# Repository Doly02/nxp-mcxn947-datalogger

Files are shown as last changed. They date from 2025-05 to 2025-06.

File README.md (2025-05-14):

## Digital Data Logger with Information Loss Prevention in Case of Power Failure

- Author: Tomáš Dolák 
- Login: [xdolak09](https://www.vut.cz/lide/tomas-dolak-247220)
- Email: <xdolak09@stud.fit.vutbr.cz>
- Supervisor: Ing. Václav Šímek
- Consultant: Ing. Martin Moštěk PhD. (NXP Semiconductors)

The goal of this project is to develop a digital data logger that captures serial data from a UART peripheral, timestamps it, and stores the logged data on an SD card.
A key requirement of the implementation is to ensure data integrity by preventing loss in the event of a power failure. This digital data logger was developed based on the requirements provided by the Wireless Charging Team at NXP Semiconductors.

### Table of Contents
- [Requirements](#requirements)
  - [Hardware Components](#hardware-components)
  - [Software Requirements](#software-requirements)
- [Repository Organization](#repository-organization)
- [How to Use the Digital Data Logger](#how-to-use-the-digital-data-logger)
  - [USB Interfaces](#usb-interfaces)
  - [Signal Diodes](#signal-diodes)
  - [Data Recording](#data-recording)
  - [Reading Data from the Data Logger](#reading-data-from-the-data-logger)
  - [Structure of Logged Data](#structure-of-logged-data)
  - [Format of Logged Entries](#format-of-logged-entries)
- [Developer Notes](#developer-notes)
  - [Modules](#modules)
- [Testing](#testing)
  - [Functional Testing](#functional-testing)
  - [Static Code Analysis](#static-code-analysis)
- [Documentation](#documentation)
- [Known Issues](#known-issues)
- [References](#references)

### Requirements 
To build and run `datalogger`, you will need the following:

#### Hardware Components
1. NXP FRDM-MCXN947 Development Board
2. Expansion Shield Proposed in This Bachelor Thesis

#### Software Requirements
1. MCUXpresso IDE v11.10.0 With GCC-based ARM Embedded Toolchain (Arm-none-eabi-gcc Compiler)
1. NXP SDK FRDM-MCXN947 Version 2.16.000

### Repository Organization
```
/nxp-mcxn947-datalogger
├── application/                 # Main Directory With Digital Recorder Firmware.
│   ├── src/                  # Contains The Firmware Source Files.
│   ├── doc/                     # HTML and LaTeX Firmware Documentation Generated by Doxygen.
│   ├── include/                 # Contains The Firmware Header Files.
│   └── others...                # Project Files (.cproject & .project), Libraries (e.g. FATFS), FreeRTOS, Utilities, Modules and Drivers From NXP SDK.
│
├── hardware/
│   ├── components/              # List of Used Hardware Components on Expansion Shield.
│   ├── design/                  # KiCAD Project Containing Schematic and PCB Design.
│   └── pinout_datalogger.xlsx   # Table With Overview of Microcontroller Pin Connections.
├── power_consumption/           # Digital Data Logger Power Consumption Data, Measured By Power Profiler Kit II. [1]
├── tests/
│   ├── functional_tests/        # Functional Test Folder For Verifying Correct Data Collection.
│   │   ├── test_files/          # Test Files Used By serial_tests.py Script.
│   │   ├── stress_test.py       # Script With Stress Test For Digital Data Logger Sends Data Continiously With Baudrate 921600.
│   │   └── serial_tests.py      # serial_tests.py Script.
│   └── static_analysis/
│       ├── outputs/             # Contains Outputs of Static Code Analysis According To MISRA C:2012 Rules, Performed by PC-lint Tool.
│       ├── parsers/             # Contains Parsers That Filter Rule-Breakings MISRA Rules From The Required and Mandatory Categories.
│       ├── lint_config.lnt      # Configuration File of PC Lint Plus.
│       └── sources.lst          # Defines a Set of Files To Be Analyzed by PC Lint Plus.
│
├── thesis/                                     # Sub-Module
│   ├── xdolak09-bthesis.tex                    # Main LaTeX Project of Technical Report.
│   ├── project-01-kapitoly-chapters.tex        # Chapters LaTeX Project of Technical Report.
│   ├── project-20-literatura-bibliography.bib  # Bibliography of Technical Report.
│   ├── project-30-prilohy-appendices.tex       # Appendices of Technical Report.
│   ├── table-of-extraneous-words.tex           # Table of Extraneous Words in Technical Report.
│   ├── bib-styles
│   ├── obrazky-figures/         # Used Figures.
│   ├── template-fig/            # VUT Logo.
│   └── diagrams/                # Created Digrams For Technical Report.
│
├── config                       # Contains a Sample Configuration File That Can Be Used To Configure The Behaviour of The Digital Recorder.
├── README.md
```

### How to Use the Digital Data Logger

#### Signal Diodes

The digital data logger is equipped with five status LEDs (labeled 1–5) located on the front side of the enclosure. These LEDs visually indicate the current operational state of the logger.

The image below shows the placement and labeling of each LED on the front panel of the enclosure:

<p align="center">
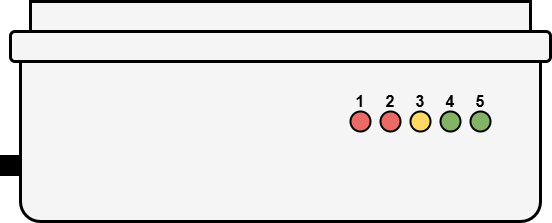
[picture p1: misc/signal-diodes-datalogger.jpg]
Data logger status LEDs
  <br>
  <em>Data logger status LEDs </em><br>
</p>

The table below describes the function of each LED:

| LED | Description |
|-----|---|
| 1 | Lights up when the available free space on the SD card falls below the limit defined by the `free_space` parameter in the configuration file. |
| 2 | Indicates an error condition. This LED turns on if the configuration file is invalid or if a critical error occurs during data recording (e.g., file creation failure or UART framing error). |
| 3 | Signals that the data logger is no longer actively recording. This state occurs, for example, when the monitored device stops transmitting data or is disconnected. |
| 4 | Blinks during active data recording to indicate that data is being received and saved to the SD card. |
| 5 | Lights up approximately 16 seconds after powering the logger to indicate that the backup capacitor is sufficiently charged. Once lit, it is safe to disconnect the device from power without risking data loss. |

#### Data Recording
1. **(Optional But Recommended)** Prepare the configuration file `config`, which should be placed in the root directory of the SD card.  
This file allows you to customize the data logger's behavior instead of using the default configuration.

<p align="center">
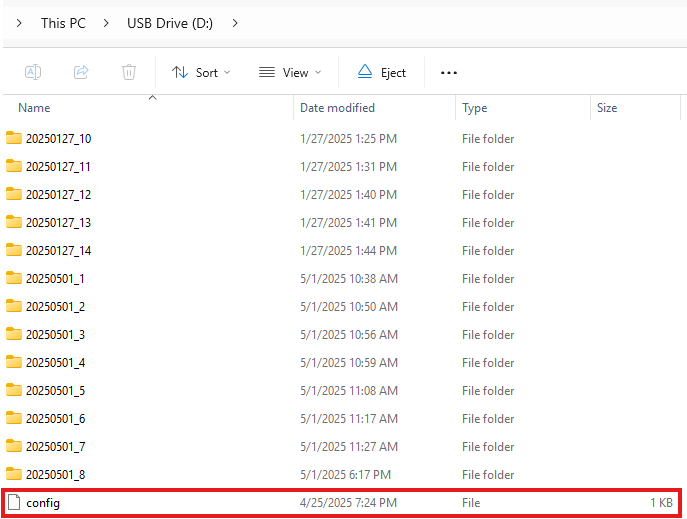
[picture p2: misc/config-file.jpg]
Location of the config file on the SD card
  <br>
  <em>Location of the config file on the SD card</em><br>
</p>

Example content of `config`:
```
baudrate=115200
file_size=2048
stop_bits=1
data_bits=8
parity=none
free_space=50
```
- **Note:** The order of parameters is not fixed.

If some of the parameters in the configuration file are missing or the configuration file is missing completely,  
the default values defined in the `defs.h` file are used.

| Parameter | Default Value | Data Type |
|---|---|---|
| `baudrate` | `230400` | uint32_t |
| `file_size` | `8192` | uint32_t (in KiB) |
| `stop_bits` | `kLPUART_OneStopBit` | enum (lpuart_stop_bit_count_t) |
| `data_bits` | `kLPUART_EightDataBits` | enum (lpuart_data_bits_t) |
| `parity` | `kLPUART_ParityDisabled` | enum (lpuart_parity_mode_t) |
| `free_space` | `50` | uint32_t (in MiB) |

2. Insert the SD card (type SDHC) into the data logger.

3. Power on the data logger via USB or another power source. The data logger will automatically:
- Load the configuration from `config` (if present)
- After startup, the data logger enters the recording mode by default. At the beginning of the record task, it initializes the SD card, and if a new or unformatted card is detected,  
  the firmware will automatically format it and initialize the FAT file system with 32-bit LBA.

4. Wait until the LED 5 indicator turns on.  
   This LED indicates that the digital data logger can be safely disconnected without the risk of data loss or file system corruption.

5. Connect the digital data logger to the monitored device that transmits serial data via UART.  
   Once the data transmission starts, the data logger will indicate active reception by blinking a dedicated LED 4,  
   which is shown in the following image.

6. At this point, the digital data logger is actively recording incoming UART data.  
   During recording, the same LED continuously blinks to indicate that data logging is in progress.

7. If an error occurs during UART data reception (e.g. framing error),  
   the digital data logger will illuminate a separate error LED 2  
   to indicate that logging has been interrupted due to a fault.

   If the error prevents further data reception, an additional LED 3 will also light up  
   to signal that the device can no longer continue logging until it is restarted or the error is resolved.

8. To safely stop data logging, disconnect the digital data logger from the monitored device.  
   At this point, all buffered data will be properly finalized and stored on the SD card.  
   The status LED D3 will then light up to indicate that data reception has been halted  
   and the device is in standby mode.

9. To resume data logging after it has been halted, simply reconnect the digital data logger  
   to the monitored UART device. The logger will automatically return to recording mode  
   (described in step 6) and continue capturing incoming data.

10. In the event of a power disconnection during logging,  
    the digital data logger detects the power loss and automatically saves all buffered data.  
    The recording is then gracefully finalized to prevent data loss or file system corruption.

#### Reading Data from the Data Logger
To read the recorded data from the digital data logger, simply connect the device to a computer using the USB1_HS connector.  
The data logger will automatically switch into data access mode (MSC mode), and the SD card will be exposed as a standard mass storage device,  
allowing the user to copy the recorded data files.

<p align="center">
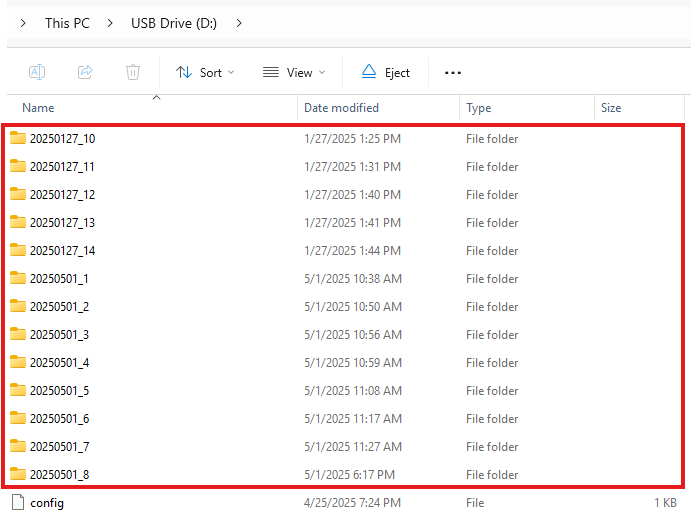
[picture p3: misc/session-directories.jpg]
Organization of session directories with logs on SD cards
  <br>
  <em>Organization of session directories with logs on SD cards</em><br>
</p>

#### Structure of Logged Data
After each startup, the data logger creates a new session directory in which all the logs from the current runtime are stored.  
These session folders are organized by the date and an incrementing counter in the format:

```
YYYYMMDD_X/
```

Where:  
- `YYYYMMDD` is the date of the session creation  
- `X` is an integer session index used to differentiate multiple sessions created on the same day

After data has been recorded, each session folder contains text-based log files storing the data collected during the corresponding session.  
The maximum size of each log file is determined by the `file_size` parameter defined in the configuration file (see chapter on configuration).  
Log files are named using the following format:

```
YYYYMMDD_HHMMSS_X.txt
```

- `YYYYMMDD_HHMMSS` is the timestamp when the log file was created  
- `X` is an index used to differentiate multiple files created at the same second

#### Format of Logged Entries
Each logged line represents a single data record terminated by a line break sequence (`\r\n`).  
Every line is prefixed with a timestamp in the format:

```
(HH:MM:SS) Logged Message
```

This timestamp represents the time when the specific data was captured by the logger.  
The following example illustrates the typical appearance of consecutive logged lines in a file:

```
(00:10:16) New Data 23741
(00:10:16) New Data 23742
(00:10:16) New Data 23743
(00:10:16) New Data 23744
(00:10:16) New Data 23745
(00:10:16) New Data 23746
(00:10:16) New Data 23747
(00:10:16) New Data 23748
(00:10:16) New Data 23749
```

### Developer Notes
All application-level source and header files are located in the `source/` and `include/` directories.

The firmware is structured into several functional modules, such as recording logic, mass storage access, power loss detection, and system status signaling.  
Many of these modules can be individually enabled or disabled as needed. This behavior is achieved through conditional compilation in ISO C, and logic blocks are active only  
if enabled via preprocessor macros. These settings are centrally managed in the application configuration header file `defs.h`.

The `defs.h` configuration file also includes the option to control the verbosity of firmware output messages. The firmware supports three message output levels:

- **Error Messages** (prefixed with `ERR:`) report critical conditions. This level is always active and can't be disabled.

```
PRINTF("ERR: Failed to Create File %s. Error=%d\r\n", u8FileName, (uint32_t)status);
```

- **Informational Messages** (prefixed with `INFO:`) provide context such as initialization progress, configuration file loading, creation of log, etc.

```
PRINTF("INFO: Created Log %s.\r\n", u8FileName);
```

- **Debug messages** (prefixed with `DEBUG:`) offer the most detailed output and include additional technical details useful during development.

```
PRINTF("DEBUG: File System Not Found. Creating FAT File System...\r\n");
```

All of these outputs are provided through the UART serial interface. The firmware uses the `LP_FLEXCOMM4` UART peripheral instance,  
configured with the following parameters:

| Parameter | Value | 
|---|---|
| Baudrate | 115200 |
| Data Bits | 8 |
| Stop Bit | 1 |
| Parity | None |

The firmware runs on the FreeRTOS real-time operating system. To ensure maximum reliability and predictability, only static memory  
allocation is used throughout the firmware. All tasks and synchronization primitives are created with predefined memory sizes,  
and dynamic memory allocation is fully disabled in the FreeRTOS configuration. Additionally, specific memory allocation functions  
for system tasks such as the idle task and timer task have been implemented to support fully static operation.

The overall hardware and software initialization procedures are handled by the `APP_InitBoard()` function, declared in the header file _app_initialization.h_  
and defined in the source file _app_initialization.c_.

The application consists of two FreeRTOS tasks – _record_task_, which is responsible for recording UART data, and _msc_task_, responsible for exposing the recorded data  
via USB. These tasks are implemented in `app_tasks.c` and `pp_tasks.h`, and are created and started from within the `main.c` file.

### Modules
The application files (`main.c`, `app_tasks.c`, and `app_initialization.c`) utilize the following separate modules.  
Each module has its own source and header file:

- `error` – Handles errors and defines error codes.  
- `led` – Manages LED Indicators For System Status.
- `mass_storage` – Provides access to log files over USB MSC.  
- `parser` – Parses the configuration file (`config`) from the SD card.
- `pwrloss_det` – Detects and reacts to power loss.
- `record` – Implements logic for recording incoming serial data from UART.
- `task_switching` – Includes the method for detection of attached or detached application USB.
- `time` – Provides date/time handling for file naming and timestamping (external and internal RTCs).
- `uart` – Includes initialization (+ configuration), enabling and disabling of the UART peripheral.  
- `temperature` – Extension for temperature measurement using the P3T1755 on-board temperature sensor on the FRDM-MCXN947.

### Testing

#### Functional Testing
The digital data logger was tested using a Python script located in the `tests/` directory under the name `serial_test.py`.

The script `serial_test.py` simulates the monitored device by reading test text files and sending their contents as serial data through the COM port to the digital data logger.  
There is a time delay between each file being sent, which deliberately causes the `CONSOLELOG_Flush()` function to be called,  
so that each test input is recorded in a separate file that can be compared against the original test file.

Scripted testing was performed at various baud rates, with testing primarily focused on baud rates corresponding to actual deployment scenarios.  
After the test was completed, the recorded outputs were compared to the original test files. The results of the comparison confirmed that in all cases tested,  
the transfer was correct and there was no data loss or corruption.

The digital data logger was also successfully verified using the `stress_test.py` script that contains a stress test.  
In this test, data was sent at 921600 baud. The data was first collected into a circular buffer of 4 KiB,  
from which it was then stored on the SD card in blocks of 4 KiB. The resulting recording files were 1 MiB in size.

Functional testing also covered the behavior of the digital recorder in non-standard scenarios that may occur during real-world deployment.The Results are Summarized in Table Below.

| Test description | Expected result | Passed |
|---|---|---|
| Missing configuration file | Error indication using LED D2, recording interrupted | Yes |
| Missing `baudrate` value in configuration | Start recording with default `baudrate` value | Yes |
| Recording on a new unformatted SD card | SD card is formatted, file system initialized, and device then records incoming data | Yes |
| Recording with file size of 512 B | File created and properly closed upon reaching limit | Yes |
| Recording with file size of 1 MB | File created and properly closed upon reaching limit | Yes |
| Low free SD card capacity (i.e., below value of parameter `free_space`) | Indication via LED | Yes |
| Transfer of recorded data from the digital recorder | Records transferred to host device from the digital recorder | Yes |

#### Static Code Analysis
In addition to functional testing, static analysis of the source code was performed using rules from the MISRA (_Motor Industry Software Reliability Association_) specification, specifically MISRA C:2012. The focus was primarily on rules classified as required and mandatory. All detected violations in these categories were either corrected or justified through comments in the source code, including a reference to the relevant rule and a rationale for the exception.

The code analysis was performed with tool PC-lint Plus v2.2 developed by Vector. [2]

#### Documentation

This project provides a full range of documentation.

- The hardware and software design concepts are described in detail in the technical report, which is available in folder `thesis/` under name `xdolak09-bthesis.pdf`
- The firmware documentation is located in the `application/doc/` directory. It is generated using Doxygen and available in two formats:
  1. **HTML documentation** - open the file `annotated.html` on the path `application/doc/html/`to start browsing.
  2. **LaTeX documentation** - found under `application/doc/latex` , where the main output file is `refman.pdf`.

### Known Issues
No issues were observed during development, testing, or practical usage of the digital data logger.

### References
[1] "Nordic Semiconductors Power Profiler Kit II" [online]. [cited 2025-5-6]. Available at [https://www.nordicsemi.com/Products/Development-hardware/Power-Profiler-Kit-2](https://www.nordicsemi.com/Products/Development-hardware/Power-Profiler-Kit-2)

[2] "PC-lint Plus 2.2 Static Code Analysis Tool for C and C++ Source Code" [online]. [cited 2025-5-6]. Available at [https://pclintplus.com/](https://pclintplus.com/)

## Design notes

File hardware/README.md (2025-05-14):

# Hardware Documentation

This folder contains all hardware-related materials for the expansion shield designed for the FRDM-MCXN947 development board used in data logger project.

### Folder Structure

- `expansion_shield/` – Contains the full KiCad 8 project of the expansion board. This includes the schematic, PCB layout, and associated design files.
- `BOM.csv` – A standard bill of materials generated from KiCad 8 listing the components used on the expansion board.  
- `component.txt` – A human-readable version of the BOM, listing key components along with direct links to online distributors for easy purchasing.  
  **Note:** This list does **not** include passive components such as resistors and capacitor (100 nF) used for the RTC DS3231M+.
- `schematic.pdf` – A PDF version of the complete schematic diagram of the expansion shield for quick reference without needing KiCad.

### Notes
- The KiCad project is created with **KiCad 8**. Make sure to use the correct version to avoid compatibility issues.
- The provided component links in `component.txt` were valid at the time of writing but may change over time depending on distributor availability.

For more information about the system design, refer to the `thesis/` folder or see the main `README` in root folder.

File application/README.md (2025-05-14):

# Application – Firmware Source Code

This folder contains the complete source code, configuration, and documentation for the firmware of the digital data logger.

### Folder Structure

- `src/` – Contains all **source files** implementing the functionality of the digital data logger.  
  This includes modules for UART data reception, SD card logging, power loss detection, LED signaling, and system management.

- `include/` – Contains the corresponding **header files** for the source files in `src/`.  
  This folder also includes the main **firmware configuration file** `defs.h`, which allows developers to e.g. enable or disable specific firmware modules at compile time, adjust default values for logging parameters such as baud rate, file size, or thresholds, configuration of FreeRTOS task stacks 

- `doc/` – Contains **Doxygen-generated documentation** for the firmware in two formats:
  - `html/annotated.html` – Start page for **HTML documentation** that can be viewed in a web browser
  - `latex/refman.pdf` – Main file of the **PDF documentation** generated via LaTeX

- `configuration/` – Holds configuration files for **external modules** used in the project, such as:
  - **FreeRTOS** – Real-time operating system for task scheduling and memory management
  - **FATFS** – Lightweight filesystem used for SD card access

- Additional source files, drivers, and libraries from the **MCUXpresso SDK** are also included.  
  These are required for proper compilation and hardware support for the **NXP FRDM-MCXN947** microcontroller.

### Project Configuration
The project currently includes two build configurations:
- `Debug/`
- `Release/` 

The project structure is prepared for future expansion, where development (`Debug`) and production (`Release`) builds can be differentiated.

### Notes

- The firmware is written in **C**, structured modularly, and built for the **NXP FRDM-MCXN947** board.
- All modules and configuration options are documented in the `doc/` folder and the comments within `defs.h`.

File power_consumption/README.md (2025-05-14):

This Folder Includes:

- Files starting with a prefix `pwr_consumption_DD_MM_YYYY_mcxn947...ppk2` are the measurement log files of a fully implemented digital logger with an expansion shield.

- File `pwr_consumption_2-2-2025-5min.ppk2` is a five-minute run of the digital recorder, in a state when the digital recorder was not yet fully developed and it was necessary to measure the consumption of the device to derive the parameters of the backup power supply.

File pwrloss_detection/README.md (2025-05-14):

This folder contains signal recordings that are essential for detecting power loss events and for analyzing how the firmware of the digital data logger responds to such conditions.
The log files are named using the pattern `pwrloss-x.sal`, where `x` is a number indicating the capture sequence. 

Note: 
- In capture `x = 0`, the recording started shortly after the digital data logger was powered on. Therefore, the initial voltage rise (power-up transition) is not visible in this trace.
- - In captures `x = {1,2,3,4}`, the recording was started before the digital data logger was connected to power. As a result, these traces include the full power-up sequence, including the rising edge of the `VIN` signal.

To visualize the recorded signals, you need the Logic 2  application from Saleae.

Signal Descriptions:
- `TIMER_state` signal indicates when the power loss detection is enabled or triggered (main CTIMER signal).
- `CMP_state` signal indicates the comparator's response to power loss.
- `VIN` signal is the input voltage (5V branch).

On the signal captures, it can be observed that around the 16th second, the power loss detection is enabled. This is indicated by:
- `TIMER_state` transitioning from `1` to `0`
- `CMP_state` stays at `0`

If a power loss is subsequently detected, it is indicated by:
- `CMP_state` transitioning from `0` to `1`
- `TIMER_state` transitioning from `1` to `0`

At this moment, the firmware initiates a dedicated procedure (RECORD_PowerlossFlush) that ensures no data is lost and the file system remains intact during the power-down event. This includes safely closing open files and flushing remaining data from internal buffers to the storage medium.

It is also important to monitor the `VIN` signal in the voltage range from 5 V down to 3.5 V. When the voltage approaches 3.5 V, the LDO regulator may become unstable, which can affect the operation of the digital logger.

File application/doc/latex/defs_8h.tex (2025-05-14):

\doxysection{include/defs.h File Reference}
\hypertarget{defs_8h}{}\label{defs_8h}\index{include/defs.h@{include/defs.h}}
{\ttfamily \#include $<$stdbool.\+h$>$}\newline
\doxysubsubsection*{Macros}
\begin{DoxyCompactItemize}
\item 
\#define \mbox{\hyperlink{defs_8h_aec2bcbab7ad208b42215cf4225e259e1}{NOT\+\_\+\+IMPLEMENTED}}~\#\mbox{\hyperlink{error_8c_a5798ff116cd549740fcaa6c6c1589ca1}{error}} "{}This Feature Is Not Implemented!"{}
\item 
\#define \mbox{\hyperlink{defs_8h_a8e3b191086204c5a914ecb42010d79b7}{MSC\+\_\+\+STACK\+\_\+\+SIZE}}~((uint32\+\_\+t)(5000\+UL / (uint32\+\_\+t)sizeof(port\+STACK\+\_\+\+TYPE)))
\begin{DoxyCompactList}\small\item\em Defines The Stack Size For Mass Storage Task. \end{DoxyCompactList}\item 
\#define \mbox{\hyperlink{defs_8h_a596e2563f1ece6b4d9a86d20455183a1}{RECORD\+\_\+\+STACK\+\_\+\+SIZE}}~((uint32\+\_\+t)(5000\+UL / (uint32\+\_\+t)sizeof(port\+STACK\+\_\+\+TYPE)))
\begin{DoxyCompactList}\small\item\em Defines The Stack Size For Recording Task. \end{DoxyCompactList}\item 
\#define \mbox{\hyperlink{defs_8h_a8a9cca2657f8a210b60490573042babc}{MSC\+\_\+\+ENABLED}}~(true)
\begin{DoxyCompactList}\small\item\em Enables/\+Disables Mass Storage Functionality. \end{DoxyCompactList}\item 
\#define \mbox{\hyperlink{defs_8h_a580f977f97ee7f7ceb91b1c42306f537}{INFO\+\_\+\+ENABLED}}~(false)
\begin{DoxyCompactList}\small\item\em Enables/\+Disables Debug Mode. \end{DoxyCompactList}\item 
\#define \mbox{\hyperlink{defs_8h_a7d2ae674cad5299a52b0e7dceac10087}{DEBUG\+\_\+\+ENABLED}}~(false)
\begin{DoxyCompactList}\small\item\em Enables/\+Disables Debug Mode. \end{DoxyCompactList}\item 
\#define \mbox{\hyperlink{defs_8h_afce4b642de5f6181c410f35cffb92cfe}{UART\+\_\+\+FIFO\+\_\+\+ENABLED}}~(true)
\begin{DoxyCompactList}\small\item\em Enables/\+Disables HW FIFO Queue on Application LPUART. \end{DoxyCompactList}\item 
\#define \mbox{\hyperlink{defs_8h_a2cc80d434c5fb494b9c88cd7775f6059}{UART\+\_\+\+FIFO\+\_\+\+LENGHT}}~(4u)
\begin{DoxyCompactList}\small\item\em Defines The Size of HW FIFO Queue. \end{DoxyCompactList}\item 
\#define \mbox{\hyperlink{defs_8h_a2c770b4d1c45e582fe15305dd53bc832}{UART\+\_\+\+PRINT\+\_\+\+ENABLED}}~(false)
\begin{DoxyCompactList}\small\item\em Enables/\+Disables Print of Received Bytes From Application LPUART To Console. \end{DoxyCompactList}\item 
\#define \mbox{\hyperlink{defs_8h_a70ae7656d68a5c5e6ce6f867d0652007}{PWRLOSS\+\_\+\+DETECTION\+\_\+\+ENABLED}}~(true)
\begin{DoxyCompactList}\small\item\em Enables/\+Disables Power Loss Detection. \end{DoxyCompactList}\item 
\#define \mbox{\hyperlink{defs_8h_aa3252ba28db7a402d73243c25da84a06}{PWRLOSS\+\_\+\+TEST\+\_\+\+GPIOS}}~(false)
\begin{DoxyCompactList}\small\item\em Enables/\+Disables GPIO For Testing Power Loss Detection. \end{DoxyCompactList}\item 
\#define \mbox{\hyperlink{defs_8h_a4a49c87e19c04996c7a1e35606802798}{TAU5}}~16.\+5
\begin{DoxyCompactList}\small\item\em Constant 5 Tau, When Back-\/\+Up Power Capacitor is Charged To 99\%. \end{DoxyCompactList}\item 
\#define \mbox{\hyperlink{defs_8h_adb3d2bcd621f551c6b54658940c42fa1}{PWRLOSS\+\_\+\+DET\+\_\+\+ACTIVE\+\_\+\+IN\+\_\+\+TIME}}~\mbox{\hyperlink{defs_8h_a4a49c87e19c04996c7a1e35606802798}{TAU5}}
\begin{DoxyCompactList}\small\item\em Time Interval When Power Loss Detection Became Active. \end{DoxyCompactList}\item 
\#define \mbox{\hyperlink{defs_8h_a8f12c7ad5263aca7dc9115c3db453025}{UART\+\_\+\+RECEIVE\+\_\+\+PRIO}}~(6U)
\begin{DoxyCompactList}\small\item\em Priority of LP\+\_\+\+FLEXCOMM Interrupt (UART) For Rx Of Recorded Data. \end{DoxyCompactList}\item 
\#define \mbox{\hyperlink{defs_8h_adb153985b953cf1557608f13fdbd74f1}{PWRLOSS\+\_\+\+DET\+\_\+\+PRIO}}~(5U)
\begin{DoxyCompactList}\small\item\em Priority of Comparator Interrupt For Power Loss Detection. \end{DoxyCompactList}\item 
\#define \mbox{\hyperlink{defs_8h_a9833f31bb9cd2e701f52a6d805b76bad}{PWRLOSS\+\_\+\+TIMER\+\_\+\+PRIO}}~(7U)
\begin{DoxyCompactList}\small\item\em Priority of Comparator Interrupt For Power Loss Detection. \end{DoxyCompactList}\item 
\#define \mbox{\hyperlink{defs_8h_a2d4e809715243195fc8b939c5d923aaa}{TEMPERATURE\+\_\+\+MEAS\+\_\+\+ENABLED}}~(false)
\begin{DoxyCompactList}\small\item\em Enables/\+Disables Temperature Recording. \end{DoxyCompactList}\item 
\#define \mbox{\hyperlink{defs_8h_aa3506ff4730ee7e3991d94b6c9cd8775}{CONTROL\+\_\+\+LED\+\_\+\+ENABLED}}~(true)
\begin{DoxyCompactList}\small\item\em Enables/\+Disables Signaling By LEDs. \end{DoxyCompactList}\item 
\#define \mbox{\hyperlink{defs_8h_a725b92a6209ddcd32e9a3365f4bbb2c9}{DEFAULT\+\_\+\+MAX\+\_\+\+FILESIZE}}~8192
\begin{DoxyCompactList}\small\item\em Default Maximal File Size If The Configuration File Could Not Be Read Properly. \end{DoxyCompactList}\item 
\#define \mbox{\hyperlink{defs_8h_a42bf63540ee0039a3a23db1b5ec3202b}{CONFIG\+\_\+\+FILE}}~"{}config"{}
\begin{DoxyCompactList}\small\item\em Configuration File. \end{DoxyCompactList}\item 
\#define \mbox{\hyperlink{defs_8h_affa2c3ad646ea14cf1a034c341caf19c}{DEFAULT\+\_\+\+BAUDRATE}}~230400\+UL
\begin{DoxyCompactList}\small\item\em Default Baud Rate If The Configuration File Could Not Be Read Properly. \end{DoxyCompactList}\item 
\#define \mbox{\hyperlink{defs_8h_a46bd477a00070e71bc80db7a292dc3bd}{DEFAULT\+\_\+\+DATA\+\_\+\+BITS}}~k\+LPUART\+\_\+\+Eight\+Data\+Bits
\begin{DoxyCompactList}\small\item\em Default Number of Data Bits If The Configuration File Could Not Be Read Properly. \end{DoxyCompactList}\item 
\#define \mbox{\hyperlink{defs_8h_ac7c5493765f96597e37aa3aa26a629f9}{DEFAULT\+\_\+\+STOP\+\_\+\+BITS}}~k\+LPUART\+\_\+\+One\+Stop\+Bit
\begin{DoxyCompactList}\small\item\em Default Number of Stop Bits If The Configuration File Could Not Be Read Properly. \end{DoxyCompactList}\item 
\#define \mbox{\hyperlink{defs_8h_a939612a13947b5bb9fc848e3222a231d}{DEFAULT\+\_\+\+PARITY}}~k\+LPUART\+\_\+\+Parity\+Disabled
\begin{DoxyCompactList}\small\item\em Default UART Parity If The Configuration File Could Not Be Read Properly. \end{DoxyCompactList}\item 
\#define \mbox{\hyperlink{defs_8h_a261f35b47dc206df57ba54ba5adbc739}{DEFAULT\+\_\+\+FREE\+\_\+\+SPACE}}~50\+UL
\begin{DoxyCompactList}\small\item\em Defines The Threshold Level of Free Memory on The SD card, Below Which The Lack of Memory is Indicated. \end{DoxyCompactList}\end{DoxyCompactItemize}

\doxysubsection{Macro Definition Documentation}
\Hypertarget{defs_8h_a42bf63540ee0039a3a23db1b5ec3202b}\index{defs.h@{defs.h}!CONFIG\_FILE@{CONFIG\_FILE}}
\index{CONFIG\_FILE@{CONFIG\_FILE}!defs.h@{defs.h}}
\doxysubsubsection{\texorpdfstring{CONFIG\_FILE}{CONFIG\_FILE}}
{\footnotesize\ttfamily \label{defs_8h_a42bf63540ee0039a3a23db1b5ec3202b} 
\#define CONFIG\+\_\+\+FILE~"{}config"{}}

Configuration File. 

\Hypertarget{defs_8h_aa3506ff4730ee7e3991d94b6c9cd8775}\index{defs.h@{defs.h}!CONTROL\_LED\_ENABLED@{CONTROL\_LED\_ENABLED}}
\index{CONTROL\_LED\_ENABLED@{CONTROL\_LED\_ENABLED}!defs.h@{defs.h}}
\doxysubsubsection{\texorpdfstring{CONTROL\_LED\_ENABLED}{CONTROL\_LED\_ENABLED}}
{\footnotesize\ttfamily \label{defs_8h_aa3506ff4730ee7e3991d94b6c9cd8775} 
\#define CONTROL\+\_\+\+LED\+\_\+\+ENABLED~(true)}

Enables/\+Disables Signaling By LEDs. 

\Hypertarget{defs_8h_a7d2ae674cad5299a52b0e7dceac10087}\index{defs.h@{defs.h}!DEBUG\_ENABLED@{DEBUG\_ENABLED}}
\index{DEBUG\_ENABLED@{DEBUG\_ENABLED}!defs.h@{defs.h}}
\doxysubsubsection{\texorpdfstring{DEBUG\_ENABLED}{DEBUG\_ENABLED}}
{\footnotesize\ttfamily \label{defs_8h_a7d2ae674cad5299a52b0e7dceac10087} 
\#define DEBUG\+\_\+\+ENABLED~(false)}

Enables/\+Disables Debug Mode. 

If Debug Mode Is Enabled Then More Logs Are Printed Into Debug Console. \Hypertarget{defs_8h_affa2c3ad646ea14cf1a034c341caf19c}\index{defs.h@{defs.h}!DEFAULT\_BAUDRATE@{DEFAULT\_BAUDRATE}}
\index{DEFAULT\_BAUDRATE@{DEFAULT\_BAUDRATE}!defs.h@{defs.h}}
\doxysubsubsection{\texorpdfstring{DEFAULT\_BAUDRATE}{DEFAULT\_BAUDRATE}}
{\footnotesize\ttfamily \label{defs_8h_affa2c3ad646ea14cf1a034c341caf19c} 
\#define DEFAULT\+\_\+\+BAUDRATE~230400\+UL}

Default Baud Rate If The Configuration File Could Not Be Read Properly. 

\Hypertarget{defs_8h_a46bd477a00070e71bc80db7a292dc3bd}\index{defs.h@{defs.h}!DEFAULT\_DATA\_BITS@{DEFAULT\_DATA\_BITS}}
\index{DEFAULT\_DATA\_BITS@{DEFAULT\_DATA\_BITS}!defs.h@{defs.h}}
\doxysubsubsection{\texorpdfstring{DEFAULT\_DATA\_BITS}{DEFAULT\_DATA\_BITS}}
{\footnotesize\ttfamily \label{defs_8h_a46bd477a00070e71bc80db7a292dc3bd} 
\#define DEFAULT\+\_\+\+DATA\+\_\+\+BITS~k\+LPUART\+\_\+\+Eight\+Data\+Bits}

Default Number of Data Bits If The Configuration File Could Not Be Read Properly. 

\Hypertarget{defs_8h_a261f35b47dc206df57ba54ba5adbc739}\index{defs.h@{defs.h}!DEFAULT\_FREE\_SPACE@{DEFAULT\_FREE\_SPACE}}
\index{DEFAULT\_FREE\_SPACE@{DEFAULT\_FREE\_SPACE}!defs.h@{defs.h}}
\doxysubsubsection{\texorpdfstring{DEFAULT\_FREE\_SPACE}{DEFAULT\_FREE\_SPACE}}
{\footnotesize\ttfamily \label{defs_8h_a261f35b47dc206df57ba54ba5adbc739} 
\#define DEFAULT\+\_\+\+FREE\+\_\+\+SPACE~50\+UL}

Defines The Threshold Level of Free Memory on The SD card, Below Which The Lack of Memory is Indicated. 

In Megabytes. \Hypertarget{defs_8h_a725b92a6209ddcd32e9a3365f4bbb2c9}\index{defs.h@{defs.h}!DEFAULT\_MAX\_FILESIZE@{DEFAULT\_MAX\_FILESIZE}}
\index{DEFAULT\_MAX\_FILESIZE@{DEFAULT\_MAX\_FILESIZE}!defs.h@{defs.h}}
\doxysubsubsection{\texorpdfstring{DEFAULT\_MAX\_FILESIZE}{DEFAULT\_MAX\_FILESIZE}}
{\footnotesize\ttfamily \label{defs_8h_a725b92a6209ddcd32e9a3365f4bbb2c9} 
\#define DEFAULT\+\_\+\+MAX\+\_\+\+FILESIZE~8192}

Default Maximal File Size If The Configuration File Could Not Be Read Properly. 

\Hypertarget{defs_8h_a939612a13947b5bb9fc848e3222a231d}\index{defs.h@{defs.h}!DEFAULT\_PARITY@{DEFAULT\_PARITY}}
\index{DEFAULT\_PARITY@{DEFAULT\_PARITY}!defs.h@{defs.h}}
\doxysubsubsection{\texorpdfstring{DEFAULT\_PARITY}{DEFAULT\_PARITY}}
{\footnotesize\ttfamily \label{defs_8h_a939612a13947b5bb9fc848e3222a231d} 
\#define DEFAULT\+\_\+\+PARITY~k\+LPUART\+\_\+\+Parity\+Disabled}

Default UART Parity If The Configuration File Could Not Be Read Properly. 

\Hypertarget{defs_8h_ac7c5493765f96597e37aa3aa26a629f9}\index{defs.h@{defs.h}!DEFAULT\_STOP\_BITS@{DEFAULT\_STOP\_BITS}}
\index{DEFAULT\_STOP\_BITS@{DEFAULT\_STOP\_BITS}!defs.h@{defs.h}}
\doxysubsubsection{\texorpdfstring{DEFAULT\_STOP\_BITS}{DEFAULT\_STOP\_BITS}}
{\footnotesize\ttfamily \label{defs_8h_ac7c5493765f96597e37aa3aa26a629f9} 
\#define DEFAULT\+\_\+\+STOP\+\_\+\+BITS~k\+LPUART\+\_\+\+One\+Stop\+Bit}

Default Number of Stop Bits If The Configuration File Could Not Be Read Properly. 

\Hypertarget{defs_8h_a580f977f97ee7f7ceb91b1c42306f537}\index{defs.h@{defs.h}!INFO\_ENABLED@{INFO\_ENABLED}}
\index{INFO\_ENABLED@{INFO\_ENABLED}!defs.h@{defs.h}}
\doxysubsubsection{\texorpdfstring{INFO\_ENABLED}{INFO\_ENABLED}}
{\footnotesize\ttfamily \label{defs_8h_a580f977f97ee7f7ceb91b1c42306f537} 
\#define INFO\+\_\+\+ENABLED~(false)}

Enables/\+Disables Debug Mode. 

If Info Mode Is Enabled Then Informational Logs Are Printed Into Debug Console. \Hypertarget{defs_8h_a8a9cca2657f8a210b60490573042babc}\index{defs.h@{defs.h}!MSC\_ENABLED@{MSC\_ENABLED}}
\index{MSC\_ENABLED@{MSC\_ENABLED}!defs.h@{defs.h}}
\doxysubsubsection{\texorpdfstring{MSC\_ENABLED}{MSC\_ENABLED}}
{\footnotesize\ttfamily \label{defs_8h_a8a9cca2657f8a210b60490573042babc} 
\#define MSC\+\_\+\+ENABLED~(true)}

Enables/\+Disables Mass Storage Functionality. 

\Hypertarget{defs_8h_a8e3b191086204c5a914ecb42010d79b7}\index{defs.h@{defs.h}!MSC\_STACK\_SIZE@{MSC\_STACK\_SIZE}}
\index{MSC\_STACK\_SIZE@{MSC\_STACK\_SIZE}!defs.h@{defs.h}}
\doxysubsubsection{\texorpdfstring{MSC\_STACK\_SIZE}{MSC\_STACK\_SIZE}}
{\footnotesize\ttfamily \label{defs_8h_a8e3b191086204c5a914ecb42010d79b7} 
\#define MSC\+\_\+\+STACK\+\_\+\+SIZE~((uint32\+\_\+t)(5000\+UL / (uint32\+\_\+t)sizeof(port\+STACK\+\_\+\+TYPE)))}

Defines The Stack Size For Mass Storage Task. 

\Hypertarget{defs_8h_aec2bcbab7ad208b42215cf4225e259e1}\index{defs.h@{defs.h}!NOT\_IMPLEMENTED@{NOT\_IMPLEMENTED}}
\index{NOT\_IMPLEMENTED@{NOT\_IMPLEMENTED}!defs.h@{defs.h}}
\doxysubsubsection{\texorpdfstring{NOT\_IMPLEMENTED}{NOT\_IMPLEMENTED}}
{\footnotesize\ttfamily \label{defs_8h_aec2bcbab7ad208b42215cf4225e259e1} 
\#define NOT\+\_\+\+IMPLEMENTED~\#\mbox{\hyperlink{error_8c_a5798ff116cd549740fcaa6c6c1589ca1}{error}} "{}This Feature Is Not Implemented!"{}}

\Hypertarget{defs_8h_adb3d2bcd621f551c6b54658940c42fa1}\index{defs.h@{defs.h}!PWRLOSS\_DET\_ACTIVE\_IN\_TIME@{PWRLOSS\_DET\_ACTIVE\_IN\_TIME}}
\index{PWRLOSS\_DET\_ACTIVE\_IN\_TIME@{PWRLOSS\_DET\_ACTIVE\_IN\_TIME}!defs.h@{defs.h}}
\doxysubsubsection{\texorpdfstring{PWRLOSS\_DET\_ACTIVE\_IN\_TIME}{PWRLOSS\_DET\_ACTIVE\_IN\_TIME}}
{\footnotesize\ttfamily \label{defs_8h_adb3d2bcd621f551c6b54658940c42fa1} 
\#define PWRLOSS\+\_\+\+DET\+\_\+\+ACTIVE\+\_\+\+IN\+\_\+\+TIME~\mbox{\hyperlink{defs_8h_a4a49c87e19c04996c7a1e35606802798}{TAU5}}}

Time Interval When Power Loss Detection Became Active. 

In Seconds. \Hypertarget{defs_8h_adb153985b953cf1557608f13fdbd74f1}\index{defs.h@{defs.h}!PWRLOSS\_DET\_PRIO@{PWRLOSS\_DET\_PRIO}}
\index{PWRLOSS\_DET\_PRIO@{PWRLOSS\_DET\_PRIO}!defs.h@{defs.h}}
\doxysubsubsection{\texorpdfstring{PWRLOSS\_DET\_PRIO}{PWRLOSS\_DET\_PRIO}}
{\footnotesize\ttfamily \label{defs_8h_adb153985b953cf1557608f13fdbd74f1} 
\#define PWRLOSS\+\_\+\+DET\+\_\+\+PRIO~(5U)}

Priority of Comparator Interrupt For Power Loss Detection. 

\Hypertarget{defs_8h_a70ae7656d68a5c5e6ce6f867d0652007}\index{defs.h@{defs.h}!PWRLOSS\_DETECTION\_ENABLED@{PWRLOSS\_DETECTION\_ENABLED}}
\index{PWRLOSS\_DETECTION\_ENABLED@{PWRLOSS\_DETECTION\_ENABLED}!defs.h@{defs.h}}
\doxysubsubsection{\texorpdfstring{PWRLOSS\_DETECTION\_ENABLED}{PWRLOSS\_DETECTION\_ENABLED}}
{\footnotesize\ttfamily \label{defs_8h_a70ae7656d68a5c5e6ce6f867d0652007} 
\#define PWRLOSS\+\_\+\+DETECTION\+\_\+\+ENABLED~(true)}

Enables/\+Disables Power Loss Detection. 

\Hypertarget{defs_8h_aa3252ba28db7a402d73243c25da84a06}\index{defs.h@{defs.h}!PWRLOSS\_TEST\_GPIOS@{PWRLOSS\_TEST\_GPIOS}}
\index{PWRLOSS\_TEST\_GPIOS@{PWRLOSS\_TEST\_GPIOS}!defs.h@{defs.h}}
\doxysubsubsection{\texorpdfstring{PWRLOSS\_TEST\_GPIOS}{PWRLOSS\_TEST\_GPIOS}}
{\footnotesize\ttfamily \label{defs_8h_aa3252ba28db7a402d73243c25da84a06} 
\#define PWRLOSS\+\_\+\+TEST\+\_\+\+GPIOS~(false)}

Enables/\+Disables GPIO For Testing Power Loss Detection. 

\Hypertarget{defs_8h_a9833f31bb9cd2e701f52a6d805b76bad}\index{defs.h@{defs.h}!PWRLOSS\_TIMER\_PRIO@{PWRLOSS\_TIMER\_PRIO}}
\index{PWRLOSS\_TIMER\_PRIO@{PWRLOSS\_TIMER\_PRIO}!defs.h@{defs.h}}
\doxysubsubsection{\texorpdfstring{PWRLOSS\_TIMER\_PRIO}{PWRLOSS\_TIMER\_PRIO}}
{\footnotesize\ttfamily \label{defs_8h_a9833f31bb9cd2e701f52a6d805b76bad} 
\#define PWRLOSS\+\_\+\+TIMER\+\_\+\+PRIO~(7U)}

Priority of Comparator Interrupt For Power Loss Detection. 

\Hypertarget{defs_8h_a596e2563f1ece6b4d9a86d20455183a1}\index{defs.h@{defs.h}!RECORD\_STACK\_SIZE@{RECORD\_STACK\_SIZE}}
\index{RECORD\_STACK\_SIZE@{RECORD\_STACK\_SIZE}!defs.h@{defs.h}}
\doxysubsubsection{\texorpdfstring{RECORD\_STACK\_SIZE}{RECORD\_STACK\_SIZE}}
{\footnotesize\ttfamily \label{defs_8h_a596e2563f1ece6b4d9a86d20455183a1} 
\#define RECORD\+\_\+\+STACK\+\_\+\+SIZE~((uint32\+\_\+t)(5000\+UL / (uint32\+\_\+t)sizeof(port\+STACK\+\_\+\+TYPE)))}

Defines The Stack Size For Recording Task. 

\Hypertarget{defs_8h_a4a49c87e19c04996c7a1e35606802798}\index{defs.h@{defs.h}!TAU5@{TAU5}}
\index{TAU5@{TAU5}!defs.h@{defs.h}}
\doxysubsubsection{\texorpdfstring{TAU5}{TAU5}}
{\footnotesize\ttfamily \label{defs_8h_a4a49c87e19c04996c7a1e35606802798} 
\#define TAU5~16.\+5}

Constant 5 Tau, When Back-\/\+Up Power Capacitor is Charged To 99\%. 

In Seconds (It\textquotesingle{}s Actually 16.\+5s). \Hypertarget{defs_8h_a2d4e809715243195fc8b939c5d923aaa}\index{defs.h@{defs.h}!TEMPERATURE\_MEAS\_ENABLED@{TEMPERATURE\_MEAS\_ENABLED}}
\index{TEMPERATURE\_MEAS\_ENABLED@{TEMPERATURE\_MEAS\_ENABLED}!defs.h@{defs.h}}
\doxysubsubsection{\texorpdfstring{TEMPERATURE\_MEAS\_ENABLED}{TEMPERATURE\_MEAS\_ENABLED}}
{\footnotesize\ttfamily \label{defs_8h_a2d4e809715243195fc8b939c5d923aaa} 
\#define TEMPERATURE\+\_\+\+MEAS\+\_\+\+ENABLED~(false)}

Enables/\+Disables Temperature Recording. 

\Hypertarget{defs_8h_afce4b642de5f6181c410f35cffb92cfe}\index{defs.h@{defs.h}!UART\_FIFO\_ENABLED@{UART\_FIFO\_ENABLED}}
\index{UART\_FIFO\_ENABLED@{UART\_FIFO\_ENABLED}!defs.h@{defs.h}}
\doxysubsubsection{\texorpdfstring{UART\_FIFO\_ENABLED}{UART\_FIFO\_ENABLED}}
{\footnotesize\ttfamily \label{defs_8h_afce4b642de5f6181c410f35cffb92cfe} 
\#define UART\+\_\+\+FIFO\+\_\+\+ENABLED~(true)}

Enables/\+Disables HW FIFO Queue on Application LPUART. 

\Hypertarget{defs_8h_a2cc80d434c5fb494b9c88cd7775f6059}\index{defs.h@{defs.h}!UART\_FIFO\_LENGHT@{UART\_FIFO\_LENGHT}}
\index{UART\_FIFO\_LENGHT@{UART\_FIFO\_LENGHT}!defs.h@{defs.h}}
\doxysubsubsection{\texorpdfstring{UART\_FIFO\_LENGHT}{UART\_FIFO\_LENGHT}}
{\footnotesize\ttfamily \label{defs_8h_a2cc80d434c5fb494b9c88cd7775f6059} 
\#define UART\+\_\+\+FIFO\+\_\+\+LENGHT~(4u)}

Defines The Size of HW FIFO Queue. 

\Hypertarget{defs_8h_a2c770b4d1c45e582fe15305dd53bc832}\index{defs.h@{defs.h}!UART\_PRINT\_ENABLED@{UART\_PRINT\_ENABLED}}
\index{UART\_PRINT\_ENABLED@{UART\_PRINT\_ENABLED}!defs.h@{defs.h}}
\doxysubsubsection{\texorpdfstring{UART\_PRINT\_ENABLED}{UART\_PRINT\_ENABLED}}
{\footnotesize\ttfamily \label{defs_8h_a2c770b4d1c45e582fe15305dd53bc832} 
\#define UART\+\_\+\+PRINT\+\_\+\+ENABLED~(false)}

Enables/\+Disables Print of Received Bytes From Application LPUART To Console. 

\Hypertarget{defs_8h_a8f12c7ad5263aca7dc9115c3db453025}\index{defs.h@{defs.h}!UART\_RECEIVE\_PRIO@{UART\_RECEIVE\_PRIO}}
\index{UART\_RECEIVE\_PRIO@{UART\_RECEIVE\_PRIO}!defs.h@{defs.h}}
\doxysubsubsection{\texorpdfstring{UART\_RECEIVE\_PRIO}{UART\_RECEIVE\_PRIO}}
{\footnotesize\ttfamily \label{defs_8h_a8f12c7ad5263aca7dc9115c3db453025} 
\#define UART\+\_\+\+RECEIVE\+\_\+\+PRIO~(6U)}

Priority of LP\+\_\+\+FLEXCOMM Interrupt (UART) For Rx Of Recorded Data.

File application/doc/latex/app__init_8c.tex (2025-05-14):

\doxysection{src/app\+\_\+init.c File Reference}
\hypertarget{app__init_8c}{}\label{app__init_8c}\index{src/app\_init.c@{src/app\_init.c}}
{\ttfamily \#include "{}app\+\_\+tasks.\+h"{}}\newline
{\ttfamily \#include "{}app\+\_\+init.\+h"{}}\newline
\doxysubsubsection*{Functions}
\begin{DoxyCompactItemize}
\item 
void \mbox{\hyperlink{app__init_8c_af08640c49c85139dcc18b9e69d4ffd0c}{APP\+\_\+\+Init\+Board}} (void)
\begin{DoxyCompactList}\small\item\em Initializes Board Peripherals And Modules For Proper Functionality of The Logger. \end{DoxyCompactList}\end{DoxyCompactItemize}

\doxysubsection{Function Documentation}
\Hypertarget{app__init_8c_af08640c49c85139dcc18b9e69d4ffd0c}\index{app\_init.c@{app\_init.c}!APP\_InitBoard@{APP\_InitBoard}}
\index{APP\_InitBoard@{APP\_InitBoard}!app\_init.c@{app\_init.c}}
\doxysubsubsection{\texorpdfstring{APP\_InitBoard()}{APP\_InitBoard()}}
{\footnotesize\ttfamily \label{app__init_8c_af08640c49c85139dcc18b9e69d4ffd0c} 
void APP\+\_\+\+Init\+Board (\begin{DoxyParamCaption}\item[{void}]{}{}\end{DoxyParamCaption})}

Initializes Board Peripherals And Modules For Proper Functionality of The Logger.

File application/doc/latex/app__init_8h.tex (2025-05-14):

\doxysection{include/app\+\_\+init.h File Reference}
\hypertarget{app__init_8h}{}\label{app__init_8h}\index{include/app\_init.h@{include/app\_init.h}}
{\ttfamily \#include "{}fsl\+\_\+device\+\_\+registers.\+h"{}}\newline
{\ttfamily \#include "{}fsl\+\_\+debug\+\_\+console.\+h"{}}\newline
{\ttfamily \#include "{}fsl\+\_\+clock.\+h"{}}\newline
{\ttfamily \#include "{}pin\+\_\+mux.\+h"{}}\newline
{\ttfamily \#include "{}clock\+\_\+config.\+h"{}}\newline
{\ttfamily \#include "{}board.\+h"{}}\newline
{\ttfamily \#include "{}led.\+h"{}}\newline
{\ttfamily \#include "{}uart.\+h"{}}\newline
{\ttfamily \#include "{}time.\+h"{}}\newline
{\ttfamily \#include "{}error.\+h"{}}\newline
{\ttfamily \#include "{}temperature.\+h"{}}\newline
{\ttfamily \#include "{}pwrloss\+\_\+det.\+h"{}}\newline
\doxysubsubsection*{Functions}
\begin{DoxyCompactItemize}
\item 
void \mbox{\hyperlink{app__init_8h_af08640c49c85139dcc18b9e69d4ffd0c}{APP\+\_\+\+Init\+Board}} (void)
\begin{DoxyCompactList}\small\item\em Initializes Board Peripherals And Modules For Proper Functionality of The Logger. \end{DoxyCompactList}\end{DoxyCompactItemize}

\doxysubsection{Function Documentation}
\Hypertarget{app__init_8h_af08640c49c85139dcc18b9e69d4ffd0c}\index{app\_init.h@{app\_init.h}!APP\_InitBoard@{APP\_InitBoard}}
\index{APP\_InitBoard@{APP\_InitBoard}!app\_init.h@{app\_init.h}}
\doxysubsubsection{\texorpdfstring{APP\_InitBoard()}{APP\_InitBoard()}}
{\footnotesize\ttfamily \label{app__init_8h_af08640c49c85139dcc18b9e69d4ffd0c} 
void APP\+\_\+\+Init\+Board (\begin{DoxyParamCaption}\item[{void}]{}{}\end{DoxyParamCaption})}

Initializes Board Peripherals And Modules For Proper Functionality of The Logger.

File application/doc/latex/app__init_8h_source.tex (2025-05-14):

\doxysection{app\+\_\+init.\+h}
\hypertarget{app__init_8h_source}{}\label{app__init_8h_source}\index{include/app\_init.h@{include/app\_init.h}}
\mbox{\hyperlink{app__init_8h}{Go to the documentation of this file.}}
\begin{DoxyCode}{0}
\DoxyCodeLine{00001\ \textcolor{comment}{/******************************}}
\DoxyCodeLine{00002\ \textcolor{comment}{\ *\ \ Project:\ \ \ \ \ \ \ \ NXP\ MCXN947\ Datalogger}}
\DoxyCodeLine{00003\ \textcolor{comment}{\ *\ \ File\ Name:\ \ \ \ \ \ init.c}}
\DoxyCodeLine{00004\ \textcolor{comment}{\ *\ \ Author:\ \ \ \ \ \ \ \ \ Tomas\ Dolak}}
\DoxyCodeLine{00005\ \textcolor{comment}{\ *\ \ Date:\ \ \ \ \ \ \ \ \ \ \ 31.03.2025}}
\DoxyCodeLine{00006\ \textcolor{comment}{\ *\ \ Description:\ \ \ \ Implements\ Datalogger\ Application.}}
\DoxyCodeLine{00007\ \textcolor{comment}{\ *}}
\DoxyCodeLine{00008\ \textcolor{comment}{\ *\ ****************************/}}
\DoxyCodeLine{00009\ }
\DoxyCodeLine{00010\ \textcolor{comment}{/******************************}}
\DoxyCodeLine{00011\ \textcolor{comment}{\ *\ \ @package\ \ \ \ \ \ \ \ NXP\ MCXN947\ Datalogger}}
\DoxyCodeLine{00012\ \textcolor{comment}{\ *\ \ @file\ \ \ \ \ \ \ \ \ \ \ init.c}}
\DoxyCodeLine{00013\ \textcolor{comment}{\ *\ \ @author\ \ \ \ \ \ \ \ \ Tomas\ Dolak}}
\DoxyCodeLine{00014\ \textcolor{comment}{\ *\ \ @date\ \ \ \ \ \ \ \ \ \ \ 31.03.2025}}
\DoxyCodeLine{00015\ \textcolor{comment}{\ *\ \ @brief\ \ \ \ \ \ \ \ \ \ Implements\ Datalogger\ Application.}}
\DoxyCodeLine{00016\ \textcolor{comment}{\ *\ ****************************/}}
\DoxyCodeLine{00017\ }
\DoxyCodeLine{00018\ \textcolor{preprocessor}{\#ifndef\ APP\_INIT\_H\_}}
\DoxyCodeLine{00019\ \textcolor{preprocessor}{\#define\ APP\_INIT\_H\_}}
\DoxyCodeLine{00020\ \textcolor{comment}{/*******************************************************************************}}
\DoxyCodeLine{00021\ \textcolor{comment}{\ *\ Includes}}
\DoxyCodeLine{00022\ \textcolor{comment}{\ ******************************************************************************/}}
\DoxyCodeLine{00023\ \textcolor{comment}{/*\ NXP\ Board\ Specific\ */}}
\DoxyCodeLine{00024\ \textcolor{preprocessor}{\#include\ "{}fsl\_device\_registers.h"{}}}
\DoxyCodeLine{00025\ \textcolor{preprocessor}{\#include\ "{}fsl\_debug\_console.h"{}}}
\DoxyCodeLine{00026\ \textcolor{preprocessor}{\#include\ "{}fsl\_clock.h"{}}}
\DoxyCodeLine{00027\ }
\DoxyCodeLine{00028\ \textcolor{preprocessor}{\#include\ "{}pin\_mux.h"{}}}
\DoxyCodeLine{00029\ \textcolor{preprocessor}{\#include\ "{}clock\_config.h"{}}}
\DoxyCodeLine{00030\ \textcolor{preprocessor}{\#include\ "{}board.h"{}}}
\DoxyCodeLine{00031\ }
\DoxyCodeLine{00032\ \textcolor{comment}{/*\ Application\ Includes\ */}}
\DoxyCodeLine{00033\ \textcolor{preprocessor}{\#include\ "{}\mbox{\hyperlink{led_8h}{led.h}}"{}}\ \ \ \ \ \ \ \ \ \ \ \ \ \ \ \textcolor{comment}{//\ Control\ LEDs\ Module}}
\DoxyCodeLine{00034\ \textcolor{preprocessor}{\#include\ "{}\mbox{\hyperlink{uart_8h}{uart.h}}"{}}\ \ \ \ \ \ \ \ \ \ \ \ \ \textcolor{comment}{//\ UART\ Module}}
\DoxyCodeLine{00035\ \textcolor{preprocessor}{\#include\ "{}\mbox{\hyperlink{time_8h}{time.h}}"{}}\ \ \ \ \ \ \ \ \ \ \ \ \ \textcolor{comment}{//\ Time\ Module}}
\DoxyCodeLine{00036\ \textcolor{preprocessor}{\#include\ "{}\mbox{\hyperlink{error_8h}{error.h}}"{}}\ \ \ \ \ \ \ \ \ \ \ \ \ \ \ \textcolor{comment}{//\ Error\ Handling}}
\DoxyCodeLine{00037\ \textcolor{preprocessor}{\#include\ "{}\mbox{\hyperlink{temperature_8h}{temperature.h}}"{}}\ \ \ \ \ \ \ \textcolor{comment}{//\ Temperature\ Measurement\ Module}}
\DoxyCodeLine{00038\ \textcolor{preprocessor}{\#include\ "{}\mbox{\hyperlink{pwrloss__det_8h}{pwrloss\_det.h}}"{}}\ \ \ \ \ \ \ \textcolor{comment}{//\ Power\ Loss\ Detection\ Module}}
\DoxyCodeLine{00039\ }
\DoxyCodeLine{00040\ \textcolor{comment}{/*******************************************************************************}}
\DoxyCodeLine{00041\ \textcolor{comment}{\ *\ Global\ Definitions}}
\DoxyCodeLine{00042\ \textcolor{comment}{\ ******************************************************************************/}}
\DoxyCodeLine{00043\ }
\DoxyCodeLine{00044\ \textcolor{comment}{/*******************************************************************************}}
\DoxyCodeLine{00045\ \textcolor{comment}{\ *\ Global\ Structures}}
\DoxyCodeLine{00046\ \textcolor{comment}{\ ******************************************************************************/}}
\DoxyCodeLine{00047\ }
\DoxyCodeLine{00048\ \textcolor{comment}{/*******************************************************************************}}
\DoxyCodeLine{00049\ \textcolor{comment}{\ *\ Function\ Prototypes}}
\DoxyCodeLine{00050\ \textcolor{comment}{\ ******************************************************************************/}}
\DoxyCodeLine{00051\ }
\DoxyCodeLine{00056\ \textcolor{keywordtype}{void}\ \mbox{\hyperlink{app__init_8h_af08640c49c85139dcc18b9e69d4ffd0c}{APP\_InitBoard}}(\textcolor{keywordtype}{void});}
\DoxyCodeLine{00057\ }
\DoxyCodeLine{00058\ }
\DoxyCodeLine{00059\ \textcolor{preprocessor}{\#endif\ }\textcolor{comment}{/*\ APP\_INIT\_H\_\ */}\textcolor{preprocessor}{}}

\end{DoxyCode}

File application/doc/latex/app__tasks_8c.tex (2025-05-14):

\doxysection{src/app\+\_\+tasks.c File Reference}
\hypertarget{app__tasks_8c}{}\label{app__tasks_8c}\index{src/app\_tasks.c@{src/app\_tasks.c}}
{\ttfamily \#include "{}app\+\_\+tasks.\+h"{}}\newline
{\ttfamily \#include "{}rtc\+\_\+ds3231.\+h"{}}\newline
{\ttfamily \#include "{}mass\+\_\+storage.\+h"{}}\newline
{\ttfamily \#include "{}task\+\_\+switching.\+h"{}}\newline
{\ttfamily \#include "{}record.\+h"{}}\newline
{\ttfamily \#include $<$time.\+h$>$}\newline
\doxysubsubsection*{Functions}
\begin{DoxyCompactItemize}
\item 
void \mbox{\hyperlink{app__tasks_8c_afc4213d2d4926914e58ecd69e8a2ad08}{msc\+\_\+task}} (void \texorpdfstring{$\ast$}{*}handle)
\begin{DoxyCompactList}\small\item\em Task Responsible For Mass Storage Functionality in Device Mode. \end{DoxyCompactList}\item 
void \mbox{\hyperlink{app__tasks_8c_a6fc052f631f3c48fe52fd49e056785bd}{record\+\_\+task}} (void \texorpdfstring{$\ast$}{*}handle)
\begin{DoxyCompactList}\small\item\em Task Recording Serial Data. \end{DoxyCompactList}\item 
void \mbox{\hyperlink{app__tasks_8c_a1988aa923b19fa6f31c93afa7773f793}{v\+Application\+Get\+Idle\+Task\+Memory}} (Static\+Task\+\_\+t \texorpdfstring{$\ast$}{*}\texorpdfstring{$\ast$}{*}ppx\+Idle\+Task\+TCBBuffer, Stack\+Type\+\_\+t \texorpdfstring{$\ast$}{*}\texorpdfstring{$\ast$}{*}ppx\+Idle\+Task\+Stack\+Buffer, uint32\+\_\+t \texorpdfstring{$\ast$}{*}pul\+Idle\+Task\+Stack\+Size)
\begin{DoxyCompactList}\small\item\em Hook Function to Provide Memory For The Idle Task in Free\+RTOS. \end{DoxyCompactList}\item 
void \mbox{\hyperlink{app__tasks_8c_a1e80ecbd3fc2d04f18d6409ffa893a86}{v\+Application\+Get\+Timer\+Task\+Memory}} (Static\+Task\+\_\+t \texorpdfstring{$\ast$}{*}\texorpdfstring{$\ast$}{*}ppx\+Timer\+Task\+TCBBuffer, Stack\+Type\+\_\+t \texorpdfstring{$\ast$}{*}\texorpdfstring{$\ast$}{*}ppx\+Timer\+Task\+Stack\+Buffer, uint32\+\_\+t \texorpdfstring{$\ast$}{*}pul\+Timer\+Task\+Stack\+Size)
\begin{DoxyCompactList}\small\item\em Hook Function to Provide Memory For The Timer Task in Free\+RTOS. \end{DoxyCompactList}\end{DoxyCompactItemize}
\doxysubsubsection*{Variables}
\begin{DoxyCompactItemize}
\item 
static Static\+Task\+\_\+t \mbox{\hyperlink{group___task_management_gae4cad385712053d9a712350bfaa6a609}{x\+Idle\+Task\+TCB}}
\begin{DoxyCompactList}\small\item\em TCB (Task Control Block) -\/ Meta-\/\+Data of IDLE Task. \end{DoxyCompactList}\item 
static Stack\+Type\+\_\+t \mbox{\hyperlink{group___task_management_ga14cdc368a30f8ae63554506a3b52ac93}{ux\+Idle\+Task\+Stack}} \mbox{[}config\+MINIMAL\+\_\+\+STACK\+\_\+\+SIZE\mbox{]}
\begin{DoxyCompactList}\small\item\em Stack for Static Idle Task. \end{DoxyCompactList}\item 
static Static\+Task\+\_\+t \mbox{\hyperlink{group___task_management_gacc894c54ff9d2500bb480c6c87146d98}{x\+Timer\+Task\+TCB}}
\begin{DoxyCompactList}\small\item\em TCB (Task Control Block) -\/ Meta-\/\+Data of Timer Task. \end{DoxyCompactList}\item 
static Stack\+Type\+\_\+t \mbox{\hyperlink{group___task_management_gaf9fe642f3d18526be6f8488df25ac3ce}{ux\+Timer\+Task\+Stack}} \mbox{[}config\+TIMER\+\_\+\+TASK\+\_\+\+STACK\+\_\+\+DEPTH\mbox{]}
\begin{DoxyCompactList}\small\item\em Stack for Static Timer Task. \end{DoxyCompactList}\end{DoxyCompactItemize}

\doxysubsection{Function Documentation}
\Hypertarget{app__tasks_8c_afc4213d2d4926914e58ecd69e8a2ad08}\index{app\_tasks.c@{app\_tasks.c}!msc\_task@{msc\_task}}
\index{msc\_task@{msc\_task}!app\_tasks.c@{app\_tasks.c}}
\doxysubsubsection{\texorpdfstring{msc\_task()}{msc\_task()}}
{\footnotesize\ttfamily \label{app__tasks_8c_afc4213d2d4926914e58ecd69e8a2ad08} 
void msc\+\_\+task (\begin{DoxyParamCaption}\item[{void \texorpdfstring{$\ast$}{*}}]{handle}{}\end{DoxyParamCaption})}

Task Responsible For Mass Storage Functionality in Device Mode. 

This Task Implements USB Mass Storage Class (MSC) Operations, Allowing The System to Act As a Mass Storage Device. It Handles Communication With The Host and Manages Read/\+Write Operations.

\begin{DoxyParams}{Parameters}
{\em handle} & Pointer to The Device Handle Used For The USB Operations. \\
\hline
\end{DoxyParams}
\Hypertarget{app__tasks_8c_a6fc052f631f3c48fe52fd49e056785bd}\index{app\_tasks.c@{app\_tasks.c}!record\_task@{record\_task}}
\index{record\_task@{record\_task}!app\_tasks.c@{app\_tasks.c}}
\doxysubsubsection{\texorpdfstring{record\_task()}{record\_task()}}
{\footnotesize\ttfamily \label{app__tasks_8c_a6fc052f631f3c48fe52fd49e056785bd} 
void record\+\_\+task (\begin{DoxyParamCaption}\item[{void \texorpdfstring{$\ast$}{*}}]{handle}{}\end{DoxyParamCaption})}

Task Recording Serial Data. 

The Task Provides Data Reception, Data Processing (For Example, Adding Time Stamps) And Also Data Storage. In Case The Monitored Device Is Disconnected From The Data Logger, All The Buffered Data In RAM Is Stored On The Memory Card.

\begin{DoxyParams}{Parameters}
{\em handle} & Pointer to The Device Handle Used For The USB Operations. \\
\hline
\end{DoxyParams}
\Hypertarget{app__tasks_8c_a1988aa923b19fa6f31c93afa7773f793}\index{app\_tasks.c@{app\_tasks.c}!vApplicationGetIdleTaskMemory@{vApplicationGetIdleTaskMemory}}
\index{vApplicationGetIdleTaskMemory@{vApplicationGetIdleTaskMemory}!app\_tasks.c@{app\_tasks.c}}
\doxysubsubsection{\texorpdfstring{vApplicationGetIdleTaskMemory()}{vApplicationGetIdleTaskMemory()}}
{\footnotesize\ttfamily \label{app__tasks_8c_a1988aa923b19fa6f31c93afa7773f793} 
void v\+Application\+Get\+Idle\+Task\+Memory (\begin{DoxyParamCaption}\item[{Static\+Task\+\_\+t \texorpdfstring{$\ast$}{*}\texorpdfstring{$\ast$}{*}}]{ppx\+Idle\+Task\+TCBBuffer}{, }\item[{Stack\+Type\+\_\+t \texorpdfstring{$\ast$}{*}\texorpdfstring{$\ast$}{*}}]{ppx\+Idle\+Task\+Stack\+Buffer}{, }\item[{uint32\+\_\+t \texorpdfstring{$\ast$}{*}}]{pul\+Idle\+Task\+Stack\+Size}{}\end{DoxyParamCaption})}

Hook Function to Provide Memory For The Idle Task in Free\+RTOS. 

This Hook Function Provides The Memory Needed For The Idle Task, Which Is Statically Allocated When config\+SUPPORT\+\_\+\+STATIC\+\_\+\+ALLOCATION Is Set to 1. The Free\+RTOS Scheduler Calls This Function to Get The Task Control Block (TCB) and Stack For The Idle Task.

\begin{DoxyParams}[1]{Parameters}
\mbox{\texttt{ out}}  & {\em ppx\+Idle\+Task\+TCBBuffer} & Pointer to The TCB Buffer For The Idle Task. \\
\hline
\mbox{\texttt{ out}}  & {\em ppx\+Idle\+Task\+Stack\+Buffer} & Pointer to The Stack Buffer For The Idle Task. \\
\hline
\mbox{\texttt{ out}}  & {\em pul\+Idle\+Task\+Stack\+Size} & Pointer to a Variable Holding The Stack Size. \\
\hline
\end{DoxyParams}
MISRA Deviation\+: Rule 10.\+8 \mbox{[}Required\mbox{]} Suppress\+: Conversion From Signed Macro To Unsigned Type. Justification\+: \textquotesingle{}Config\+MINIMAL\+\_\+\+STACK\+\_\+\+SIZE\textquotesingle{} Is Defined By Free\+RTOS As A Signed Macro. The Conversion To \textquotesingle{}Uint32\+\_\+t\textquotesingle{} Is Intentional And Safe In This Context. Fixing The Definition is Not Possible.\Hypertarget{app__tasks_8c_a1e80ecbd3fc2d04f18d6409ffa893a86}\index{app\_tasks.c@{app\_tasks.c}!vApplicationGetTimerTaskMemory@{vApplicationGetTimerTaskMemory}}
\index{vApplicationGetTimerTaskMemory@{vApplicationGetTimerTaskMemory}!app\_tasks.c@{app\_tasks.c}}
\doxysubsubsection{\texorpdfstring{vApplicationGetTimerTaskMemory()}{vApplicationGetTimerTaskMemory()}}
{\footnotesize\ttfamily \label{app__tasks_8c_a1e80ecbd3fc2d04f18d6409ffa893a86} 
void v\+Application\+Get\+Timer\+Task\+Memory (\begin{DoxyParamCaption}\item[{Static\+Task\+\_\+t \texorpdfstring{$\ast$}{*}\texorpdfstring{$\ast$}{*}}]{ppx\+Timer\+Task\+TCBBuffer}{, }\item[{Stack\+Type\+\_\+t \texorpdfstring{$\ast$}{*}\texorpdfstring{$\ast$}{*}}]{ppx\+Timer\+Task\+Stack\+Buffer}{, }\item[{uint32\+\_\+t \texorpdfstring{$\ast$}{*}}]{pul\+Timer\+Task\+Stack\+Size}{}\end{DoxyParamCaption})}

Hook Function to Provide Memory For The Timer Task in Free\+RTOS. 

This Hook Function Provides The Memory Needed For The Timer Task, Which Is Statically Allocated When config\+SUPPORT\+\_\+\+STATIC\+\_\+\+ALLOCATION Is Set To 1 And config\+USE\+\_\+\+TIMERS Is Enabled. The Free\+RTOS Scheduler Calls This Function to Get The Task Control Block (TCB) And Stack For The Timer Task.

\begin{DoxyParams}[1]{Parameters}
\mbox{\texttt{ out}}  & {\em ppx\+Timer\+Task\+TCBBuffer} & Pointer to The TCB Buffer For The Timer Task. \\
\hline
\mbox{\texttt{ out}}  & {\em ppx\+Timer\+Task\+Stack\+Buffer} & Pointer to The Stack Buffer For The Timer Task. \\
\hline
\mbox{\texttt{ out}}  & {\em pul\+Timer\+Task\+Stack\+Size} & Pointer to a Variable Holding The Stack Size. \\
\hline
\end{DoxyParams}
MISRA Deviation\+: Rule 10.\+8 \mbox{[}Required\mbox{]} Suppress\+: Conversion From Signed Macro To Unsigned Type. Justification\+: \textquotesingle{}config\+TIMER\+\_\+\+TASK\+\_\+\+STACK\+\_\+\+DEPTH\textquotesingle{} Is Defined By Free\+RTOS As A Signed Macro. The Conversion To \textquotesingle{}Uint32\+\_\+t\textquotesingle{} Is Intentional And Safe In This Context. Fixing The Definition is Not Possible.

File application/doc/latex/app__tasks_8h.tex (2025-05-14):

\doxysection{include/app\+\_\+tasks.h File Reference}
\hypertarget{app__tasks_8h}{}\label{app__tasks_8h}\index{include/app\_tasks.h@{include/app\_tasks.h}}
{\ttfamily \#include "{}Free\+RTOS.\+h"{}}\newline
{\ttfamily \#include "{}task.\+h"{}}\newline
{\ttfamily \#include "{}queue.\+h"{}}\newline
{\ttfamily \#include "{}semphr.\+h"{}}\newline
{\ttfamily \#include "{}timers.\+h"{}}\newline
{\ttfamily \#include $<$disk.\+h$>$}\newline
\doxysubsubsection*{Macros}
\begin{DoxyCompactItemize}
\item 
\#define \mbox{\hyperlink{app__tasks_8h_a2c6c08fc3284377444145fa6b627ac21}{TASK\+\_\+\+PRIO}}~(config\+MAX\+\_\+\+PRIORITIES -\/ 1)
\end{DoxyCompactItemize}
\doxysubsubsection*{Functions}
\begin{DoxyCompactItemize}
\item 
void \mbox{\hyperlink{app__tasks_8h_afc4213d2d4926914e58ecd69e8a2ad08}{msc\+\_\+task}} (void \texorpdfstring{$\ast$}{*}handle)
\begin{DoxyCompactList}\small\item\em Task Responsible For Mass Storage Functionality in Device Mode. \end{DoxyCompactList}\item 
void \mbox{\hyperlink{app__tasks_8h_a6fc052f631f3c48fe52fd49e056785bd}{record\+\_\+task}} (void \texorpdfstring{$\ast$}{*}handle)
\begin{DoxyCompactList}\small\item\em Task Recording Serial Data. \end{DoxyCompactList}\item 
void \mbox{\hyperlink{app__tasks_8h_a1988aa923b19fa6f31c93afa7773f793}{v\+Application\+Get\+Idle\+Task\+Memory}} (Static\+Task\+\_\+t \texorpdfstring{$\ast$}{*}\texorpdfstring{$\ast$}{*}ppx\+Idle\+Task\+TCBBuffer, Stack\+Type\+\_\+t \texorpdfstring{$\ast$}{*}\texorpdfstring{$\ast$}{*}ppx\+Idle\+Task\+Stack\+Buffer, uint32\+\_\+t \texorpdfstring{$\ast$}{*}pul\+Idle\+Task\+Stack\+Size)
\begin{DoxyCompactList}\small\item\em Hook Function to Provide Memory For The Idle Task in Free\+RTOS. \end{DoxyCompactList}\item 
void \mbox{\hyperlink{app__tasks_8h_a1e80ecbd3fc2d04f18d6409ffa893a86}{v\+Application\+Get\+Timer\+Task\+Memory}} (Static\+Task\+\_\+t \texorpdfstring{$\ast$}{*}\texorpdfstring{$\ast$}{*}ppx\+Timer\+Task\+TCBBuffer, Stack\+Type\+\_\+t \texorpdfstring{$\ast$}{*}\texorpdfstring{$\ast$}{*}ppx\+Timer\+Task\+Stack\+Buffer, uint32\+\_\+t \texorpdfstring{$\ast$}{*}pul\+Timer\+Task\+Stack\+Size)
\begin{DoxyCompactList}\small\item\em Hook Function to Provide Memory For The Timer Task in Free\+RTOS. \end{DoxyCompactList}\end{DoxyCompactItemize}
\doxysubsubsection*{Variables}
\begin{DoxyCompactItemize}
\item 
Task\+Handle\+\_\+t \mbox{\hyperlink{app__tasks_8h_a728d33fa6714c81e0ddb020328ac36ee}{g\+\_\+x\+Msc\+Task\+Handle}}
\begin{DoxyCompactList}\small\item\em USB Mass Storage Task Handle. \end{DoxyCompactList}\item 
Task\+Handle\+\_\+t \mbox{\hyperlink{app__tasks_8h_a95134cbd8723a2c8b0cdd33f75d979fb}{g\+\_\+x\+Record\+Task\+Handle}}
\begin{DoxyCompactList}\small\item\em Record Task Handle. \end{DoxyCompactList}\item 
Semaphore\+Handle\+\_\+t \mbox{\hyperlink{app__tasks_8h_af59d7418386068624f2b915e32fe23ff}{g\+\_\+x\+Sem\+Record}}
\begin{DoxyCompactList}\small\item\em Semaphore For Record Task Management. \end{DoxyCompactList}\item 
Semaphore\+Handle\+\_\+t \mbox{\hyperlink{app__tasks_8h_a286a007f0c94c51fa505aa600c488122}{g\+\_\+x\+Sem\+Mass\+Storage}}
\begin{DoxyCompactList}\small\item\em Semaphore For USB Mass Storage Task Management. \end{DoxyCompactList}\end{DoxyCompactItemize}

\doxysubsection{Macro Definition Documentation}
\Hypertarget{app__tasks_8h_a2c6c08fc3284377444145fa6b627ac21}\index{app\_tasks.h@{app\_tasks.h}!TASK\_PRIO@{TASK\_PRIO}}
\index{TASK\_PRIO@{TASK\_PRIO}!app\_tasks.h@{app\_tasks.h}}
\doxysubsubsection{\texorpdfstring{TASK\_PRIO}{TASK\_PRIO}}
{\footnotesize\ttfamily \label{app__tasks_8h_a2c6c08fc3284377444145fa6b627ac21} 
\#define TASK\+\_\+\+PRIO~(config\+MAX\+\_\+\+PRIORITIES -\/ 1)}

\doxysubsection{Function Documentation}
\Hypertarget{app__tasks_8h_afc4213d2d4926914e58ecd69e8a2ad08}\index{app\_tasks.h@{app\_tasks.h}!msc\_task@{msc\_task}}
\index{msc\_task@{msc\_task}!app\_tasks.h@{app\_tasks.h}}
\doxysubsubsection{\texorpdfstring{msc\_task()}{msc\_task()}}
{\footnotesize\ttfamily \label{app__tasks_8h_afc4213d2d4926914e58ecd69e8a2ad08} 
void msc\+\_\+task (\begin{DoxyParamCaption}\item[{void \texorpdfstring{$\ast$}{*}}]{handle}{}\end{DoxyParamCaption})}

Task Responsible For Mass Storage Functionality in Device Mode. 

This Task Implements USB Mass Storage Class (MSC) Operations, Allowing The System to Act As a Mass Storage Device. It Handles Communication With The Host and Manages Read/\+Write Operations.

\begin{DoxyParams}{Parameters}
{\em handle} & Pointer to The Device Handle Used For The USB Operations. \\
\hline
\end{DoxyParams}
\Hypertarget{app__tasks_8h_a6fc052f631f3c48fe52fd49e056785bd}\index{app\_tasks.h@{app\_tasks.h}!record\_task@{record\_task}}
\index{record\_task@{record\_task}!app\_tasks.h@{app\_tasks.h}}
\doxysubsubsection{\texorpdfstring{record\_task()}{record\_task()}}
{\footnotesize\ttfamily \label{app__tasks_8h_a6fc052f631f3c48fe52fd49e056785bd} 
void record\+\_\+task (\begin{DoxyParamCaption}\item[{void \texorpdfstring{$\ast$}{*}}]{handle}{}\end{DoxyParamCaption})}

Task Recording Serial Data. 

The Task Provides Data Reception, Data Processing (For Example, Adding Time Stamps) And Also Data Storage. In Case The Monitored Device Is Disconnected From The Data Logger, All The Buffered Data In RAM Is Stored On The Memory Card.

\begin{DoxyParams}{Parameters}
{\em handle} & Pointer to The Device Handle Used For The USB Operations. \\
\hline
\end{DoxyParams}
\Hypertarget{app__tasks_8h_a1988aa923b19fa6f31c93afa7773f793}\index{app\_tasks.h@{app\_tasks.h}!vApplicationGetIdleTaskMemory@{vApplicationGetIdleTaskMemory}}
\index{vApplicationGetIdleTaskMemory@{vApplicationGetIdleTaskMemory}!app\_tasks.h@{app\_tasks.h}}
\doxysubsubsection{\texorpdfstring{vApplicationGetIdleTaskMemory()}{vApplicationGetIdleTaskMemory()}}
{\footnotesize\ttfamily \label{app__tasks_8h_a1988aa923b19fa6f31c93afa7773f793} 
void v\+Application\+Get\+Idle\+Task\+Memory (\begin{DoxyParamCaption}\item[{Static\+Task\+\_\+t \texorpdfstring{$\ast$}{*}\texorpdfstring{$\ast$}{*}}]{ppx\+Idle\+Task\+TCBBuffer}{, }\item[{Stack\+Type\+\_\+t \texorpdfstring{$\ast$}{*}\texorpdfstring{$\ast$}{*}}]{ppx\+Idle\+Task\+Stack\+Buffer}{, }\item[{uint32\+\_\+t \texorpdfstring{$\ast$}{*}}]{pul\+Idle\+Task\+Stack\+Size}{}\end{DoxyParamCaption})}

Hook Function to Provide Memory For The Idle Task in Free\+RTOS. 

This Hook Function Provides The Memory Needed For The Idle Task, Which Is Statically Allocated When config\+SUPPORT\+\_\+\+STATIC\+\_\+\+ALLOCATION Is Set to 1. The Free\+RTOS Scheduler Calls This Function to Get The Task Control Block (TCB) and Stack For The Idle Task.

\begin{DoxyParams}[1]{Parameters}
\mbox{\texttt{ out}}  & {\em ppx\+Idle\+Task\+TCBBuffer} & Pointer to The TCB Buffer For The Idle Task. \\
\hline
\mbox{\texttt{ out}}  & {\em ppx\+Idle\+Task\+Stack\+Buffer} & Pointer to The Stack Buffer For The Idle Task. \\
\hline
\mbox{\texttt{ out}}  & {\em pul\+Idle\+Task\+Stack\+Size} & Pointer to a Variable Holding The Stack Size. \\
\hline
\end{DoxyParams}
MISRA Deviation\+: Rule 10.\+8 \mbox{[}Required\mbox{]} Suppress\+: Conversion From Signed Macro To Unsigned Type. Justification\+: \textquotesingle{}Config\+MINIMAL\+\_\+\+STACK\+\_\+\+SIZE\textquotesingle{} Is Defined By Free\+RTOS As A Signed Macro. The Conversion To \textquotesingle{}Uint32\+\_\+t\textquotesingle{} Is Intentional And Safe In This Context. Fixing The Definition is Not Possible.\Hypertarget{app__tasks_8h_a1e80ecbd3fc2d04f18d6409ffa893a86}\index{app\_tasks.h@{app\_tasks.h}!vApplicationGetTimerTaskMemory@{vApplicationGetTimerTaskMemory}}
\index{vApplicationGetTimerTaskMemory@{vApplicationGetTimerTaskMemory}!app\_tasks.h@{app\_tasks.h}}
\doxysubsubsection{\texorpdfstring{vApplicationGetTimerTaskMemory()}{vApplicationGetTimerTaskMemory()}}
{\footnotesize\ttfamily \label{app__tasks_8h_a1e80ecbd3fc2d04f18d6409ffa893a86} 
void v\+Application\+Get\+Timer\+Task\+Memory (\begin{DoxyParamCaption}\item[{Static\+Task\+\_\+t \texorpdfstring{$\ast$}{*}\texorpdfstring{$\ast$}{*}}]{ppx\+Timer\+Task\+TCBBuffer}{, }\item[{Stack\+Type\+\_\+t \texorpdfstring{$\ast$}{*}\texorpdfstring{$\ast$}{*}}]{ppx\+Timer\+Task\+Stack\+Buffer}{, }\item[{uint32\+\_\+t \texorpdfstring{$\ast$}{*}}]{pul\+Timer\+Task\+Stack\+Size}{}\end{DoxyParamCaption})}

Hook Function to Provide Memory For The Timer Task in Free\+RTOS. 

This Hook Function Provides The Memory Needed For The Timer Task, Which Is Statically Allocated When config\+SUPPORT\+\_\+\+STATIC\+\_\+\+ALLOCATION Is Set To 1 And config\+USE\+\_\+\+TIMERS Is Enabled. The Free\+RTOS Scheduler Calls This Function to Get The Task Control Block (TCB) And Stack For The Timer Task.

\begin{DoxyParams}[1]{Parameters}
\mbox{\texttt{ out}}  & {\em ppx\+Timer\+Task\+TCBBuffer} & Pointer to The TCB Buffer For The Timer Task. \\
\hline
\mbox{\texttt{ out}}  & {\em ppx\+Timer\+Task\+Stack\+Buffer} & Pointer to The Stack Buffer For The Timer Task. \\
\hline
\mbox{\texttt{ out}}  & {\em pul\+Timer\+Task\+Stack\+Size} & Pointer to a Variable Holding The Stack Size. \\
\hline
\end{DoxyParams}
MISRA Deviation\+: Rule 10.\+8 \mbox{[}Required\mbox{]} Suppress\+: Conversion From Signed Macro To Unsigned Type. Justification\+: \textquotesingle{}config\+TIMER\+\_\+\+TASK\+\_\+\+STACK\+\_\+\+DEPTH\textquotesingle{} Is Defined By Free\+RTOS As A Signed Macro. The Conversion To \textquotesingle{}Uint32\+\_\+t\textquotesingle{} Is Intentional And Safe In This Context. Fixing The Definition is Not Possible.

\doxysubsection{Variable Documentation}
\Hypertarget{app__tasks_8h_a728d33fa6714c81e0ddb020328ac36ee}\index{app\_tasks.h@{app\_tasks.h}!g\_xMscTaskHandle@{g\_xMscTaskHandle}}
\index{g\_xMscTaskHandle@{g\_xMscTaskHandle}!app\_tasks.h@{app\_tasks.h}}
\doxysubsubsection{\texorpdfstring{g\_xMscTaskHandle}{g\_xMscTaskHandle}}
{\footnotesize\ttfamily \label{app__tasks_8h_a728d33fa6714c81e0ddb020328ac36ee} 
Task\+Handle\+\_\+t g\+\_\+x\+Msc\+Task\+Handle\hspace{0.3cm}{\ttfamily [extern]}}

USB Mass Storage Task Handle. 

\Hypertarget{app__tasks_8h_a95134cbd8723a2c8b0cdd33f75d979fb}\index{app\_tasks.h@{app\_tasks.h}!g\_xRecordTaskHandle@{g\_xRecordTaskHandle}}
\index{g\_xRecordTaskHandle@{g\_xRecordTaskHandle}!app\_tasks.h@{app\_tasks.h}}
\doxysubsubsection{\texorpdfstring{g\_xRecordTaskHandle}{g\_xRecordTaskHandle}}
{\footnotesize\ttfamily \label{app__tasks_8h_a95134cbd8723a2c8b0cdd33f75d979fb} 
Task\+Handle\+\_\+t g\+\_\+x\+Record\+Task\+Handle\hspace{0.3cm}{\ttfamily [extern]}}

Record Task Handle. 

\Hypertarget{app__tasks_8h_a286a007f0c94c51fa505aa600c488122}\index{app\_tasks.h@{app\_tasks.h}!g\_xSemMassStorage@{g\_xSemMassStorage}}
\index{g\_xSemMassStorage@{g\_xSemMassStorage}!app\_tasks.h@{app\_tasks.h}}
\doxysubsubsection{\texorpdfstring{g\_xSemMassStorage}{g\_xSemMassStorage}}
{\footnotesize\ttfamily \label{app__tasks_8h_a286a007f0c94c51fa505aa600c488122} 
Semaphore\+Handle\+\_\+t g\+\_\+x\+Sem\+Mass\+Storage\hspace{0.3cm}{\ttfamily [extern]}}

Semaphore For USB Mass Storage Task Management. 

\Hypertarget{app__tasks_8h_af59d7418386068624f2b915e32fe23ff}\index{app\_tasks.h@{app\_tasks.h}!g\_xSemRecord@{g\_xSemRecord}}
\index{g\_xSemRecord@{g\_xSemRecord}!app\_tasks.h@{app\_tasks.h}}
\doxysubsubsection{\texorpdfstring{g\_xSemRecord}{g\_xSemRecord}}
{\footnotesize\ttfamily \label{app__tasks_8h_af59d7418386068624f2b915e32fe23ff} 
Semaphore\+Handle\+\_\+t g\+\_\+x\+Sem\+Record\hspace{0.3cm}{\ttfamily [extern]}}

Semaphore For Record Task Management.

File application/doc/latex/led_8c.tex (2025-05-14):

\doxysection{src/led.c File Reference}
\hypertarget{led_8c}{}\label{led_8c}\index{src/led.c@{src/led.c}}
{\ttfamily \#include $<$led.\+h$>$}\newline
\doxysubsubsection*{Functions}
\begin{DoxyCompactItemize}
\item 
void \mbox{\hyperlink{led_8c_a7455e287128129db10bb2ae70909ff7a}{LED\+\_\+\+Set\+High}} (GPIO\+\_\+\+Type \texorpdfstring{$\ast$}{*}port\+\_\+base, uint32\+\_\+t pin)
\begin{DoxyCompactList}\small\item\em Sets Logic 1 on GPIO Pin. \end{DoxyCompactList}\item 
void \mbox{\hyperlink{led_8c_ab02c6a3a312ce2e008f471310fef8f5b}{LED\+\_\+\+Set\+Low}} (GPIO\+\_\+\+Type \texorpdfstring{$\ast$}{*}port\+\_\+base, uint32\+\_\+t pin)
\begin{DoxyCompactList}\small\item\em Sets Logic 0 on GPIO Pin. \end{DoxyCompactList}\item 
void \mbox{\hyperlink{led_8c_a90d3262aad7d8e74c655aecba5bdb8b1}{LED\+\_\+\+Signal\+Ready}} (void)
\begin{DoxyCompactList}\small\item\em Indicates Ready State of The Recording Device. \end{DoxyCompactList}\item 
void \mbox{\hyperlink{led_8c_ae4d93582ce6f8960bbbe8771670864f2}{LED\+\_\+\+Signal\+Recording}} (void)
\begin{DoxyCompactList}\small\item\em Signals That Device Is Currently Receiving Bytes (Recording). \end{DoxyCompactList}\item 
void \mbox{\hyperlink{led_8c_a357ebead2af4aa7710b82477c78c3ae5}{LED\+\_\+\+Signal\+Recording\+Stop}} (void)
\begin{DoxyCompactList}\small\item\em Signals That Device Is Stopped Receiving Bytes (Recording). \end{DoxyCompactList}\item 
void \mbox{\hyperlink{led_8c_a051c422ce8dcca2df8022a718fa9e85c}{LED\+\_\+\+Signal\+Back\+Up\+Power\+Available}} (void)
\begin{DoxyCompactList}\small\item\em Signals Configuration File Missing or Contains Unexpected Data. \end{DoxyCompactList}\item 
void \mbox{\hyperlink{led_8c_aeab72eb69dcad626cad6ab8d18f5b7f7}{LED\+\_\+\+Signal\+Low\+Memory}} (void)
\begin{DoxyCompactList}\small\item\em Signals That There Will Be Empty Space on SD Card. \end{DoxyCompactList}\item 
void \mbox{\hyperlink{led_8c_a13c3d29b05f96fd3490c9b7680f7df08}{LED\+\_\+\+Signal\+Error}} (void)
\begin{DoxyCompactList}\small\item\em Signals Error During Recording. \end{DoxyCompactList}\item 
void \mbox{\hyperlink{led_8c_ac6978cdce3f5c99d7cd85a6991a5394a}{LED\+\_\+\+Signal\+Flush}} (void)
\begin{DoxyCompactList}\small\item\em Signals That Flush Has Been Activated. \end{DoxyCompactList}\item 
void \mbox{\hyperlink{led_8c_a790afc5a8ed07437a4788698ca9afe45}{LED\+\_\+\+Clear\+Signal\+Flush}} (void)
\begin{DoxyCompactList}\small\item\em Clears Flush LED After UART Re-\/\+Inicialization. \end{DoxyCompactList}\end{DoxyCompactItemize}

\doxysubsection{Function Documentation}
\Hypertarget{led_8c_a790afc5a8ed07437a4788698ca9afe45}\index{led.c@{led.c}!LED\_ClearSignalFlush@{LED\_ClearSignalFlush}}
\index{LED\_ClearSignalFlush@{LED\_ClearSignalFlush}!led.c@{led.c}}
\doxysubsubsection{\texorpdfstring{LED\_ClearSignalFlush()}{LED\_ClearSignalFlush()}}
{\footnotesize\ttfamily \label{led_8c_a790afc5a8ed07437a4788698ca9afe45} 
void LED\+\_\+\+Clear\+Signal\+Flush (\begin{DoxyParamCaption}\item[{void}]{}{}\end{DoxyParamCaption})}

Clears Flush LED After UART Re-\/\+Inicialization. 

\Hypertarget{led_8c_a7455e287128129db10bb2ae70909ff7a}\index{led.c@{led.c}!LED\_SetHigh@{LED\_SetHigh}}
\index{LED\_SetHigh@{LED\_SetHigh}!led.c@{led.c}}
\doxysubsubsection{\texorpdfstring{LED\_SetHigh()}{LED\_SetHigh()}}
{\footnotesize\ttfamily \label{led_8c_a7455e287128129db10bb2ae70909ff7a} 
void LED\+\_\+\+Set\+High (\begin{DoxyParamCaption}\item[{GPIO\+\_\+\+Type \texorpdfstring{$\ast$}{*}}]{port\+\_\+base}{, }\item[{uint32\+\_\+t}]{pin}{}\end{DoxyParamCaption})}

Sets Logic 1 on GPIO Pin. 

\begin{DoxyParams}{Parameters}
{\em port\+\_\+base} & Pointer to GPIO Instance. \\
\hline
{\em pin} & Pin. \\
\hline
\end{DoxyParams}
\Hypertarget{led_8c_ab02c6a3a312ce2e008f471310fef8f5b}\index{led.c@{led.c}!LED\_SetLow@{LED\_SetLow}}
\index{LED\_SetLow@{LED\_SetLow}!led.c@{led.c}}
\doxysubsubsection{\texorpdfstring{LED\_SetLow()}{LED\_SetLow()}}
{\footnotesize\ttfamily \label{led_8c_ab02c6a3a312ce2e008f471310fef8f5b} 
void LED\+\_\+\+Set\+Low (\begin{DoxyParamCaption}\item[{GPIO\+\_\+\+Type \texorpdfstring{$\ast$}{*}}]{port\+\_\+base}{, }\item[{uint32\+\_\+t}]{pin}{}\end{DoxyParamCaption})}

Sets Logic 0 on GPIO Pin. 

\begin{DoxyParams}{Parameters}
{\em port\+\_\+base} & Pointer to GPIO Instance. \\
\hline
{\em pin} & Pin. \\
\hline
\end{DoxyParams}
\Hypertarget{led_8c_a051c422ce8dcca2df8022a718fa9e85c}\index{led.c@{led.c}!LED\_SignalBackUpPowerAvailable@{LED\_SignalBackUpPowerAvailable}}
\index{LED\_SignalBackUpPowerAvailable@{LED\_SignalBackUpPowerAvailable}!led.c@{led.c}}
\doxysubsubsection{\texorpdfstring{LED\_SignalBackUpPowerAvailable()}{LED\_SignalBackUpPowerAvailable()}}
{\footnotesize\ttfamily \label{led_8c_a051c422ce8dcca2df8022a718fa9e85c} 
void LED\+\_\+\+Signal\+Back\+Up\+Power\+Available (\begin{DoxyParamCaption}\item[{void}]{}{}\end{DoxyParamCaption})}

Signals Configuration File Missing or Contains Unexpected Data. 

\Hypertarget{led_8c_a13c3d29b05f96fd3490c9b7680f7df08}\index{led.c@{led.c}!LED\_SignalError@{LED\_SignalError}}
\index{LED\_SignalError@{LED\_SignalError}!led.c@{led.c}}
\doxysubsubsection{\texorpdfstring{LED\_SignalError()}{LED\_SignalError()}}
{\footnotesize\ttfamily \label{led_8c_a13c3d29b05f96fd3490c9b7680f7df08} 
void LED\+\_\+\+Signal\+Error (\begin{DoxyParamCaption}\item[{void}]{}{}\end{DoxyParamCaption})}

Signals Error During Recording. 

\Hypertarget{led_8c_ac6978cdce3f5c99d7cd85a6991a5394a}\index{led.c@{led.c}!LED\_SignalFlush@{LED\_SignalFlush}}
\index{LED\_SignalFlush@{LED\_SignalFlush}!led.c@{led.c}}
\doxysubsubsection{\texorpdfstring{LED\_SignalFlush()}{LED\_SignalFlush()}}
{\footnotesize\ttfamily \label{led_8c_ac6978cdce3f5c99d7cd85a6991a5394a} 
void LED\+\_\+\+Signal\+Flush (\begin{DoxyParamCaption}\item[{void}]{}{}\end{DoxyParamCaption})}

Signals That Flush Has Been Activated. 

\Hypertarget{led_8c_aeab72eb69dcad626cad6ab8d18f5b7f7}\index{led.c@{led.c}!LED\_SignalLowMemory@{LED\_SignalLowMemory}}
\index{LED\_SignalLowMemory@{LED\_SignalLowMemory}!led.c@{led.c}}
\doxysubsubsection{\texorpdfstring{LED\_SignalLowMemory()}{LED\_SignalLowMemory()}}
{\footnotesize\ttfamily \label{led_8c_aeab72eb69dcad626cad6ab8d18f5b7f7} 
void LED\+\_\+\+Signal\+Low\+Memory (\begin{DoxyParamCaption}\item[{void}]{}{}\end{DoxyParamCaption})}

Signals That There Will Be Empty Space on SD Card. 

\Hypertarget{led_8c_a90d3262aad7d8e74c655aecba5bdb8b1}\index{led.c@{led.c}!LED\_SignalReady@{LED\_SignalReady}}
\index{LED\_SignalReady@{LED\_SignalReady}!led.c@{led.c}}
\doxysubsubsection{\texorpdfstring{LED\_SignalReady()}{LED\_SignalReady()}}
{\footnotesize\ttfamily \label{led_8c_a90d3262aad7d8e74c655aecba5bdb8b1} 
void LED\+\_\+\+Signal\+Ready (\begin{DoxyParamCaption}\item[{void}]{}{}\end{DoxyParamCaption})}

Indicates Ready State of The Recording Device. 

\Hypertarget{led_8c_ae4d93582ce6f8960bbbe8771670864f2}\index{led.c@{led.c}!LED\_SignalRecording@{LED\_SignalRecording}}
\index{LED\_SignalRecording@{LED\_SignalRecording}!led.c@{led.c}}
\doxysubsubsection{\texorpdfstring{LED\_SignalRecording()}{LED\_SignalRecording()}}
{\footnotesize\ttfamily \label{led_8c_ae4d93582ce6f8960bbbe8771670864f2} 
void LED\+\_\+\+Signal\+Recording (\begin{DoxyParamCaption}\item[{void}]{}{}\end{DoxyParamCaption})}

Signals That Device Is Currently Receiving Bytes (Recording). 

\Hypertarget{led_8c_a357ebead2af4aa7710b82477c78c3ae5}\index{led.c@{led.c}!LED\_SignalRecordingStop@{LED\_SignalRecordingStop}}
\index{LED\_SignalRecordingStop@{LED\_SignalRecordingStop}!led.c@{led.c}}
\doxysubsubsection{\texorpdfstring{LED\_SignalRecordingStop()}{LED\_SignalRecordingStop()}}
{\footnotesize\ttfamily \label{led_8c_a357ebead2af4aa7710b82477c78c3ae5} 
void LED\+\_\+\+Signal\+Recording\+Stop (\begin{DoxyParamCaption}\item[{void}]{}{}\end{DoxyParamCaption})}

Signals That Device Is Stopped Receiving Bytes (Recording).

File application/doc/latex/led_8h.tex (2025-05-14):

\doxysection{include/led.h File Reference}
\hypertarget{led_8h}{}\label{led_8h}\index{include/led.h@{include/led.h}}
{\ttfamily \#include "{}fsl\+\_\+gpio.\+h"{}}\newline
{\ttfamily \#include "{}board.\+h"{}}\newline
\doxysubsubsection*{Macros}
\begin{DoxyCompactItemize}
\item 
\#define \mbox{\hyperlink{led_8h_a84357dafca10c0bedd27ddf562ec038f}{ERROR\+\_\+\+LED\+\_\+\+PORT}}~GPIO0
\begin{DoxyCompactList}\small\item\em Error LED\textquotesingle{}s Port Number. \end{DoxyCompactList}\item 
\#define \mbox{\hyperlink{led_8h_a24b5595c4f500e96c463709e93f372df}{ERROR\+\_\+\+LED\+\_\+\+PIN\+\_\+\+RECORD}}~0x09
\begin{DoxyCompactList}\small\item\em Error LED\textquotesingle{}s Pin 2. \end{DoxyCompactList}\item 
\#define \mbox{\hyperlink{led_8h_afd1ca686ff8235c560a32a3a164d1332}{MEMORY\+\_\+\+LOW\+\_\+\+LED\+\_\+\+PORT}}~GPIO0
\begin{DoxyCompactList}\small\item\em Low Memory LED\textquotesingle{}s Port Number. \end{DoxyCompactList}\item 
\#define \mbox{\hyperlink{led_8h_ad0d6a0ebc0e8b8e08da47c03675be9f4}{MEMORY\+\_\+\+LOW\+\_\+\+LED\+\_\+\+PIN}}~0x07
\begin{DoxyCompactList}\small\item\em Error LED\textquotesingle{}s Pin 1. \end{DoxyCompactList}\item 
\#define \mbox{\hyperlink{led_8h_a58fc08140f1f3f414c40ca7a59258ab8}{FLUSH\+\_\+\+LED\+\_\+\+PORT}}~GPIO0
\begin{DoxyCompactList}\small\item\em Flush LED\textquotesingle{}s Port Number. \end{DoxyCompactList}\item 
\#define \mbox{\hyperlink{led_8h_a104335d8ce14e6db09a76faf2ad04f78}{RECORD\+\_\+\+LED\+\_\+\+PIN\+\_\+\+FLUSH}}~0x0D
\begin{DoxyCompactList}\small\item\em Error LED\textquotesingle{}s Pin 3. \end{DoxyCompactList}\item 
\#define \mbox{\hyperlink{led_8h_a72816a8b71df387833d9cb24aafcfaaa}{RECORD\+\_\+\+LED\+\_\+\+PORT}}~GPIO2
\begin{DoxyCompactList}\small\item\em Recording LED\textquotesingle{}s Port Number. \end{DoxyCompactList}\item 
\#define \mbox{\hyperlink{led_8h_a63ef077ec9bea5b9b4bf1ea75170ab51}{RECORD\+\_\+\+LED\+\_\+\+PIN}}~0x0B
\begin{DoxyCompactList}\small\item\em Record LED\textquotesingle{}s Pin. \end{DoxyCompactList}\item 
\#define \mbox{\hyperlink{led_8h_a8d1a4771539dc53163d8061f4b69e25c}{BACKUP\+\_\+\+POWER\+\_\+\+LED\+\_\+\+PORT}}~GPIO4
\begin{DoxyCompactList}\small\item\em Recording LED\textquotesingle{}s Port Number. \end{DoxyCompactList}\item 
\#define \mbox{\hyperlink{led_8h_a3b699b928ec222ebe45b1fbd4924608b}{BACKUP\+\_\+\+POWER\+\_\+\+LED\+\_\+\+PIN}}~0x11
\begin{DoxyCompactList}\small\item\em Record LED\textquotesingle{}s Pin. \end{DoxyCompactList}\end{DoxyCompactItemize}
\doxysubsubsection*{Functions}
\begin{DoxyCompactItemize}
\item 
void \mbox{\hyperlink{led_8h_a7455e287128129db10bb2ae70909ff7a}{LED\+\_\+\+Set\+High}} (GPIO\+\_\+\+Type \texorpdfstring{$\ast$}{*}port\+\_\+base, uint32\+\_\+t pin)
\begin{DoxyCompactList}\small\item\em Sets Logic 1 on GPIO Pin. \end{DoxyCompactList}\item 
void \mbox{\hyperlink{led_8h_ab02c6a3a312ce2e008f471310fef8f5b}{LED\+\_\+\+Set\+Low}} (GPIO\+\_\+\+Type \texorpdfstring{$\ast$}{*}port\+\_\+base, uint32\+\_\+t pin)
\begin{DoxyCompactList}\small\item\em Sets Logic 0 on GPIO Pin. \end{DoxyCompactList}\item 
void \mbox{\hyperlink{led_8h_a90d3262aad7d8e74c655aecba5bdb8b1}{LED\+\_\+\+Signal\+Ready}} (void)
\begin{DoxyCompactList}\small\item\em Indicates Ready State of The Recording Device. \end{DoxyCompactList}\item 
void \mbox{\hyperlink{led_8h_ae4d93582ce6f8960bbbe8771670864f2}{LED\+\_\+\+Signal\+Recording}} (void)
\begin{DoxyCompactList}\small\item\em Signals That Device Is Currently Receiving Bytes (Recording). \end{DoxyCompactList}\item 
void \mbox{\hyperlink{led_8h_a357ebead2af4aa7710b82477c78c3ae5}{LED\+\_\+\+Signal\+Recording\+Stop}} (void)
\begin{DoxyCompactList}\small\item\em Signals That Device Is Stopped Receiving Bytes (Recording). \end{DoxyCompactList}\item 
void \mbox{\hyperlink{led_8h_a051c422ce8dcca2df8022a718fa9e85c}{LED\+\_\+\+Signal\+Back\+Up\+Power\+Available}} (void)
\begin{DoxyCompactList}\small\item\em Signals Configuration File Missing or Contains Unexpected Data. \end{DoxyCompactList}\item 
void \mbox{\hyperlink{led_8h_aeab72eb69dcad626cad6ab8d18f5b7f7}{LED\+\_\+\+Signal\+Low\+Memory}} (void)
\begin{DoxyCompactList}\small\item\em Signals That There Will Be Empty Space on SD Card. \end{DoxyCompactList}\item 
void \mbox{\hyperlink{led_8h_a13c3d29b05f96fd3490c9b7680f7df08}{LED\+\_\+\+Signal\+Error}} (void)
\begin{DoxyCompactList}\small\item\em Signals Error During Recording. \end{DoxyCompactList}\item 
void \mbox{\hyperlink{led_8h_ac6978cdce3f5c99d7cd85a6991a5394a}{LED\+\_\+\+Signal\+Flush}} (void)
\begin{DoxyCompactList}\small\item\em Signals That Flush Has Been Activated. \end{DoxyCompactList}\item 
void \mbox{\hyperlink{led_8h_a790afc5a8ed07437a4788698ca9afe45}{LED\+\_\+\+Clear\+Signal\+Flush}} (void)
\begin{DoxyCompactList}\small\item\em Clears Flush LED After UART Re-\/\+Inicialization. \end{DoxyCompactList}\end{DoxyCompactItemize}

\doxysubsection{Macro Definition Documentation}
\Hypertarget{led_8h_a3b699b928ec222ebe45b1fbd4924608b}\index{led.h@{led.h}!BACKUP\_POWER\_LED\_PIN@{BACKUP\_POWER\_LED\_PIN}}
\index{BACKUP\_POWER\_LED\_PIN@{BACKUP\_POWER\_LED\_PIN}!led.h@{led.h}}
\doxysubsubsection{\texorpdfstring{BACKUP\_POWER\_LED\_PIN}{BACKUP\_POWER\_LED\_PIN}}
{\footnotesize\ttfamily \label{led_8h_a3b699b928ec222ebe45b1fbd4924608b} 
\#define BACKUP\+\_\+\+POWER\+\_\+\+LED\+\_\+\+PIN~0x11}

Record LED\textquotesingle{}s Pin. 

P4\+\_\+17 \Hypertarget{led_8h_a8d1a4771539dc53163d8061f4b69e25c}\index{led.h@{led.h}!BACKUP\_POWER\_LED\_PORT@{BACKUP\_POWER\_LED\_PORT}}
\index{BACKUP\_POWER\_LED\_PORT@{BACKUP\_POWER\_LED\_PORT}!led.h@{led.h}}
\doxysubsubsection{\texorpdfstring{BACKUP\_POWER\_LED\_PORT}{BACKUP\_POWER\_LED\_PORT}}
{\footnotesize\ttfamily \label{led_8h_a8d1a4771539dc53163d8061f4b69e25c} 
\#define BACKUP\+\_\+\+POWER\+\_\+\+LED\+\_\+\+PORT~GPIO4}

Recording LED\textquotesingle{}s Port Number. 

Signals That Device Records. \Hypertarget{led_8h_a24b5595c4f500e96c463709e93f372df}\index{led.h@{led.h}!ERROR\_LED\_PIN\_RECORD@{ERROR\_LED\_PIN\_RECORD}}
\index{ERROR\_LED\_PIN\_RECORD@{ERROR\_LED\_PIN\_RECORD}!led.h@{led.h}}
\doxysubsubsection{\texorpdfstring{ERROR\_LED\_PIN\_RECORD}{ERROR\_LED\_PIN\_RECORD}}
{\footnotesize\ttfamily \label{led_8h_a24b5595c4f500e96c463709e93f372df} 
\#define ERROR\+\_\+\+LED\+\_\+\+PIN\+\_\+\+RECORD~0x09}

Error LED\textquotesingle{}s Pin 2. 

P0\+\_\+9 \Hypertarget{led_8h_a84357dafca10c0bedd27ddf562ec038f}\index{led.h@{led.h}!ERROR\_LED\_PORT@{ERROR\_LED\_PORT}}
\index{ERROR\_LED\_PORT@{ERROR\_LED\_PORT}!led.h@{led.h}}
\doxysubsubsection{\texorpdfstring{ERROR\_LED\_PORT}{ERROR\_LED\_PORT}}
{\footnotesize\ttfamily \label{led_8h_a84357dafca10c0bedd27ddf562ec038f} 
\#define ERROR\+\_\+\+LED\+\_\+\+PORT~GPIO0}

Error LED\textquotesingle{}s Port Number. 

\Hypertarget{led_8h_a58fc08140f1f3f414c40ca7a59258ab8}\index{led.h@{led.h}!FLUSH\_LED\_PORT@{FLUSH\_LED\_PORT}}
\index{FLUSH\_LED\_PORT@{FLUSH\_LED\_PORT}!led.h@{led.h}}
\doxysubsubsection{\texorpdfstring{FLUSH\_LED\_PORT}{FLUSH\_LED\_PORT}}
{\footnotesize\ttfamily \label{led_8h_a58fc08140f1f3f414c40ca7a59258ab8} 
\#define FLUSH\+\_\+\+LED\+\_\+\+PORT~GPIO0}

Flush LED\textquotesingle{}s Port Number. 

\Hypertarget{led_8h_ad0d6a0ebc0e8b8e08da47c03675be9f4}\index{led.h@{led.h}!MEMORY\_LOW\_LED\_PIN@{MEMORY\_LOW\_LED\_PIN}}
\index{MEMORY\_LOW\_LED\_PIN@{MEMORY\_LOW\_LED\_PIN}!led.h@{led.h}}
\doxysubsubsection{\texorpdfstring{MEMORY\_LOW\_LED\_PIN}{MEMORY\_LOW\_LED\_PIN}}
{\footnotesize\ttfamily \label{led_8h_ad0d6a0ebc0e8b8e08da47c03675be9f4} 
\#define MEMORY\+\_\+\+LOW\+\_\+\+LED\+\_\+\+PIN~0x07}

Error LED\textquotesingle{}s Pin 1. 

P0\+\_\+7 \Hypertarget{led_8h_afd1ca686ff8235c560a32a3a164d1332}\index{led.h@{led.h}!MEMORY\_LOW\_LED\_PORT@{MEMORY\_LOW\_LED\_PORT}}
\index{MEMORY\_LOW\_LED\_PORT@{MEMORY\_LOW\_LED\_PORT}!led.h@{led.h}}
\doxysubsubsection{\texorpdfstring{MEMORY\_LOW\_LED\_PORT}{MEMORY\_LOW\_LED\_PORT}}
{\footnotesize\ttfamily \label{led_8h_afd1ca686ff8235c560a32a3a164d1332} 
\#define MEMORY\+\_\+\+LOW\+\_\+\+LED\+\_\+\+PORT~GPIO0}

Low Memory LED\textquotesingle{}s Port Number. 

\Hypertarget{led_8h_a63ef077ec9bea5b9b4bf1ea75170ab51}\index{led.h@{led.h}!RECORD\_LED\_PIN@{RECORD\_LED\_PIN}}
\index{RECORD\_LED\_PIN@{RECORD\_LED\_PIN}!led.h@{led.h}}
\doxysubsubsection{\texorpdfstring{RECORD\_LED\_PIN}{RECORD\_LED\_PIN}}
{\footnotesize\ttfamily \label{led_8h_a63ef077ec9bea5b9b4bf1ea75170ab51} 
\#define RECORD\+\_\+\+LED\+\_\+\+PIN~0x0B}

Record LED\textquotesingle{}s Pin. 

P2\+\_\+11 \Hypertarget{led_8h_a104335d8ce14e6db09a76faf2ad04f78}\index{led.h@{led.h}!RECORD\_LED\_PIN\_FLUSH@{RECORD\_LED\_PIN\_FLUSH}}
\index{RECORD\_LED\_PIN\_FLUSH@{RECORD\_LED\_PIN\_FLUSH}!led.h@{led.h}}
\doxysubsubsection{\texorpdfstring{RECORD\_LED\_PIN\_FLUSH}{RECORD\_LED\_PIN\_FLUSH}}
{\footnotesize\ttfamily \label{led_8h_a104335d8ce14e6db09a76faf2ad04f78} 
\#define RECORD\+\_\+\+LED\+\_\+\+PIN\+\_\+\+FLUSH~0x0D}

Error LED\textquotesingle{}s Pin 3. 

P0\+\_\+13 \Hypertarget{led_8h_a72816a8b71df387833d9cb24aafcfaaa}\index{led.h@{led.h}!RECORD\_LED\_PORT@{RECORD\_LED\_PORT}}
\index{RECORD\_LED\_PORT@{RECORD\_LED\_PORT}!led.h@{led.h}}
\doxysubsubsection{\texorpdfstring{RECORD\_LED\_PORT}{RECORD\_LED\_PORT}}
{\footnotesize\ttfamily \label{led_8h_a72816a8b71df387833d9cb24aafcfaaa} 
\#define RECORD\+\_\+\+LED\+\_\+\+PORT~GPIO2}

Recording LED\textquotesingle{}s Port Number. 

Signals That Device Records. 

\doxysubsection{Function Documentation}
\Hypertarget{led_8h_a790afc5a8ed07437a4788698ca9afe45}\index{led.h@{led.h}!LED\_ClearSignalFlush@{LED\_ClearSignalFlush}}
\index{LED\_ClearSignalFlush@{LED\_ClearSignalFlush}!led.h@{led.h}}
\doxysubsubsection{\texorpdfstring{LED\_ClearSignalFlush()}{LED\_ClearSignalFlush()}}
{\footnotesize\ttfamily \label{led_8h_a790afc5a8ed07437a4788698ca9afe45} 
void LED\+\_\+\+Clear\+Signal\+Flush (\begin{DoxyParamCaption}\item[{void}]{}{}\end{DoxyParamCaption})}

Clears Flush LED After UART Re-\/\+Inicialization. 

\Hypertarget{led_8h_a7455e287128129db10bb2ae70909ff7a}\index{led.h@{led.h}!LED\_SetHigh@{LED\_SetHigh}}
\index{LED\_SetHigh@{LED\_SetHigh}!led.h@{led.h}}
\doxysubsubsection{\texorpdfstring{LED\_SetHigh()}{LED\_SetHigh()}}
{\footnotesize\ttfamily \label{led_8h_a7455e287128129db10bb2ae70909ff7a} 
void LED\+\_\+\+Set\+High (\begin{DoxyParamCaption}\item[{GPIO\+\_\+\+Type \texorpdfstring{$\ast$}{*}}]{port\+\_\+base}{, }\item[{uint32\+\_\+t}]{pin}{}\end{DoxyParamCaption})}

Sets Logic 1 on GPIO Pin. 

\begin{DoxyParams}{Parameters}
{\em port\+\_\+base} & Pointer to GPIO Instance. \\
\hline
{\em pin} & Pin. \\
\hline
\end{DoxyParams}
\Hypertarget{led_8h_ab02c6a3a312ce2e008f471310fef8f5b}\index{led.h@{led.h}!LED\_SetLow@{LED\_SetLow}}
\index{LED\_SetLow@{LED\_SetLow}!led.h@{led.h}}
\doxysubsubsection{\texorpdfstring{LED\_SetLow()}{LED\_SetLow()}}
{\footnotesize\ttfamily \label{led_8h_ab02c6a3a312ce2e008f471310fef8f5b} 
void LED\+\_\+\+Set\+Low (\begin{DoxyParamCaption}\item[{GPIO\+\_\+\+Type \texorpdfstring{$\ast$}{*}}]{port\+\_\+base}{, }\item[{uint32\+\_\+t}]{pin}{}\end{DoxyParamCaption})}

Sets Logic 0 on GPIO Pin. 

\begin{DoxyParams}{Parameters}
{\em port\+\_\+base} & Pointer to GPIO Instance. \\
\hline
{\em pin} & Pin. \\
\hline
\end{DoxyParams}
\Hypertarget{led_8h_a051c422ce8dcca2df8022a718fa9e85c}\index{led.h@{led.h}!LED\_SignalBackUpPowerAvailable@{LED\_SignalBackUpPowerAvailable}}
\index{LED\_SignalBackUpPowerAvailable@{LED\_SignalBackUpPowerAvailable}!led.h@{led.h}}
\doxysubsubsection{\texorpdfstring{LED\_SignalBackUpPowerAvailable()}{LED\_SignalBackUpPowerAvailable()}}
{\footnotesize\ttfamily \label{led_8h_a051c422ce8dcca2df8022a718fa9e85c} 
void LED\+\_\+\+Signal\+Back\+Up\+Power\+Available (\begin{DoxyParamCaption}\item[{void}]{}{}\end{DoxyParamCaption})}

Signals Configuration File Missing or Contains Unexpected Data. 

\Hypertarget{led_8h_a13c3d29b05f96fd3490c9b7680f7df08}\index{led.h@{led.h}!LED\_SignalError@{LED\_SignalError}}
\index{LED\_SignalError@{LED\_SignalError}!led.h@{led.h}}
\doxysubsubsection{\texorpdfstring{LED\_SignalError()}{LED\_SignalError()}}
{\footnotesize\ttfamily \label{led_8h_a13c3d29b05f96fd3490c9b7680f7df08} 
void LED\+\_\+\+Signal\+Error (\begin{DoxyParamCaption}\item[{void}]{}{}\end{DoxyParamCaption})}

Signals Error During Recording. 

\Hypertarget{led_8h_ac6978cdce3f5c99d7cd85a6991a5394a}\index{led.h@{led.h}!LED\_SignalFlush@{LED\_SignalFlush}}
\index{LED\_SignalFlush@{LED\_SignalFlush}!led.h@{led.h}}
\doxysubsubsection{\texorpdfstring{LED\_SignalFlush()}{LED\_SignalFlush()}}
{\footnotesize\ttfamily \label{led_8h_ac6978cdce3f5c99d7cd85a6991a5394a} 
void LED\+\_\+\+Signal\+Flush (\begin{DoxyParamCaption}\item[{void}]{}{}\end{DoxyParamCaption})}

Signals That Flush Has Been Activated. 

\Hypertarget{led_8h_aeab72eb69dcad626cad6ab8d18f5b7f7}\index{led.h@{led.h}!LED\_SignalLowMemory@{LED\_SignalLowMemory}}
\index{LED\_SignalLowMemory@{LED\_SignalLowMemory}!led.h@{led.h}}
\doxysubsubsection{\texorpdfstring{LED\_SignalLowMemory()}{LED\_SignalLowMemory()}}
{\footnotesize\ttfamily \label{led_8h_aeab72eb69dcad626cad6ab8d18f5b7f7} 
void LED\+\_\+\+Signal\+Low\+Memory (\begin{DoxyParamCaption}\item[{void}]{}{}\end{DoxyParamCaption})}

Signals That There Will Be Empty Space on SD Card. 

\Hypertarget{led_8h_a90d3262aad7d8e74c655aecba5bdb8b1}\index{led.h@{led.h}!LED\_SignalReady@{LED\_SignalReady}}
\index{LED\_SignalReady@{LED\_SignalReady}!led.h@{led.h}}
\doxysubsubsection{\texorpdfstring{LED\_SignalReady()}{LED\_SignalReady()}}
{\footnotesize\ttfamily \label{led_8h_a90d3262aad7d8e74c655aecba5bdb8b1} 
void LED\+\_\+\+Signal\+Ready (\begin{DoxyParamCaption}\item[{void}]{}{}\end{DoxyParamCaption})}

Indicates Ready State of The Recording Device. 

\Hypertarget{led_8h_ae4d93582ce6f8960bbbe8771670864f2}\index{led.h@{led.h}!LED\_SignalRecording@{LED\_SignalRecording}}
\index{LED\_SignalRecording@{LED\_SignalRecording}!led.h@{led.h}}
\doxysubsubsection{\texorpdfstring{LED\_SignalRecording()}{LED\_SignalRecording()}}
{\footnotesize\ttfamily \label{led_8h_ae4d93582ce6f8960bbbe8771670864f2} 
void LED\+\_\+\+Signal\+Recording (\begin{DoxyParamCaption}\item[{void}]{}{}\end{DoxyParamCaption})}

Signals That Device Is Currently Receiving Bytes (Recording). 

\Hypertarget{led_8h_a357ebead2af4aa7710b82477c78c3ae5}\index{led.h@{led.h}!LED\_SignalRecordingStop@{LED\_SignalRecordingStop}}
\index{LED\_SignalRecordingStop@{LED\_SignalRecordingStop}!led.h@{led.h}}
\doxysubsubsection{\texorpdfstring{LED\_SignalRecordingStop()}{LED\_SignalRecordingStop()}}
{\footnotesize\ttfamily \label{led_8h_a357ebead2af4aa7710b82477c78c3ae5} 
void LED\+\_\+\+Signal\+Recording\+Stop (\begin{DoxyParamCaption}\item[{void}]{}{}\end{DoxyParamCaption})}

Signals That Device Is Stopped Receiving Bytes (Recording).

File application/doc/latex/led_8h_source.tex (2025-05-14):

\doxysection{led.\+h}
\hypertarget{led_8h_source}{}\label{led_8h_source}\index{include/led.h@{include/led.h}}
\mbox{\hyperlink{led_8h}{Go to the documentation of this file.}}
\begin{DoxyCode}{0}
\DoxyCodeLine{00001\ \textcolor{comment}{/******************************}}
\DoxyCodeLine{00002\ \textcolor{comment}{\ *\ \ Project:\ \ \ \ \ \ \ \ NXP\ MCXN947\ Datalogger}}
\DoxyCodeLine{00003\ \textcolor{comment}{\ *\ \ File\ Name:\ \ \ \ \ \ leds.c}}
\DoxyCodeLine{00004\ \textcolor{comment}{\ *\ \ Author:\ \ \ \ \ \ \ \ \ Tomas\ Dolak}}
\DoxyCodeLine{00005\ \textcolor{comment}{\ *\ \ Date:\ \ \ \ \ \ \ \ \ \ \ 06.02.2025}}
\DoxyCodeLine{00006\ \textcolor{comment}{\ *\ \ Description:\ \ \ \ Implements\ The\ Logic\ For\ LEDs\ Control.}}
\DoxyCodeLine{00007\ \textcolor{comment}{\ *}}
\DoxyCodeLine{00008\ \textcolor{comment}{\ *\ ****************************/}}
\DoxyCodeLine{00009\ }
\DoxyCodeLine{00010\ \textcolor{comment}{/******************************}}
\DoxyCodeLine{00011\ \textcolor{comment}{\ *\ \ @package\ \ \ \ \ \ \ \ NXP\ MCXN947\ Datalogger}}
\DoxyCodeLine{00012\ \textcolor{comment}{\ *\ \ @file\ \ \ \ \ \ \ \ \ \ \ leds.c}}
\DoxyCodeLine{00013\ \textcolor{comment}{\ *\ \ @author\ \ \ \ \ \ \ \ \ Tomas\ Dolak}}
\DoxyCodeLine{00014\ \textcolor{comment}{\ *\ \ @date\ \ \ \ \ \ \ \ \ \ \ 06.02.2025}}
\DoxyCodeLine{00015\ \textcolor{comment}{\ *\ \ @brief\ \ \ \ \ \ \ \ \ \ Implements\ The\ Logic\ For\ LEDs\ Control.}}
\DoxyCodeLine{00016\ \textcolor{comment}{\ *\ ****************************/}}
\DoxyCodeLine{00017\ }
\DoxyCodeLine{00018\ \textcolor{preprocessor}{\#ifndef\ LED\_H\_}}
\DoxyCodeLine{00019\ \textcolor{preprocessor}{\#define\ LED\_H\_}}
\DoxyCodeLine{00020\ }
\DoxyCodeLine{00021\ \textcolor{comment}{/*******************************************************************************}}
\DoxyCodeLine{00022\ \textcolor{comment}{\ *\ Includes}}
\DoxyCodeLine{00023\ \textcolor{comment}{\ ******************************************************************************/}}
\DoxyCodeLine{00024\ \textcolor{preprocessor}{\#include\ "{}fsl\_gpio.h"{}}}
\DoxyCodeLine{00025\ \textcolor{preprocessor}{\#include\ "{}board.h"{}}}
\DoxyCodeLine{00026\ \textcolor{comment}{/*******************************************************************************}}
\DoxyCodeLine{00027\ \textcolor{comment}{\ *\ Functions\ Macros}}
\DoxyCodeLine{00028\ \textcolor{comment}{\ ******************************************************************************/}}
\DoxyCodeLine{00032\ \textcolor{preprocessor}{\#define\ ERROR\_LED\_PORT\ \ \ \ \ \ \ \ \ \ GPIO0}}
\DoxyCodeLine{00033\ }
\DoxyCodeLine{00038\ \textcolor{preprocessor}{\#define\ ERROR\_LED\_PIN\_RECORD\ \ \ \ 0x09}}
\DoxyCodeLine{00039\ }
\DoxyCodeLine{00040\ }
\DoxyCodeLine{00044\ \textcolor{preprocessor}{\#define\ MEMORY\_LOW\_LED\_PORT\ \ \ \ \ GPIO0}}
\DoxyCodeLine{00045\ }
\DoxyCodeLine{00050\ \textcolor{preprocessor}{\#define\ MEMORY\_LOW\_LED\_PIN\ \ \ \ \ \ 0x07}}
\DoxyCodeLine{00051\ }
\DoxyCodeLine{00052\ }
\DoxyCodeLine{00056\ \textcolor{preprocessor}{\#define\ FLUSH\_LED\_PORT\ \ \ \ \ \ GPIO0}}
\DoxyCodeLine{00057\ }
\DoxyCodeLine{00062\ \textcolor{preprocessor}{\#define\ RECORD\_LED\_PIN\_FLUSH\ \ \ \ 0x0D}}
\DoxyCodeLine{00063\ }
\DoxyCodeLine{00068\ \textcolor{preprocessor}{\#define\ RECORD\_LED\_PORT\ \ \ \ \ \ \ \ \ GPIO2}}
\DoxyCodeLine{00069\ }
\DoxyCodeLine{00074\ \textcolor{preprocessor}{\#define\ RECORD\_LED\_PIN\ \ \ \ \ \ \ \ \ \ 0x0B}}
\DoxyCodeLine{00075\ }
\DoxyCodeLine{00080\ \textcolor{preprocessor}{\#define\ BACKUP\_POWER\_LED\_PORT\ \ \ GPIO4}}
\DoxyCodeLine{00081\ }
\DoxyCodeLine{00086\ \textcolor{preprocessor}{\#define\ BACKUP\_POWER\_LED\_PIN\ \ \ \ 0x11}}
\DoxyCodeLine{00087\ \textcolor{comment}{/*******************************************************************************}}
\DoxyCodeLine{00088\ \textcolor{comment}{\ *\ Functions\ Definitions}}
\DoxyCodeLine{00089\ \textcolor{comment}{\ ******************************************************************************/}}
\DoxyCodeLine{00090\ }
\DoxyCodeLine{00096\ \textcolor{keywordtype}{void}\ \mbox{\hyperlink{led_8h_a7455e287128129db10bb2ae70909ff7a}{LED\_SetHigh}}(GPIO\_Type\ *port\_base,\ uint32\_t\ pin);}
\DoxyCodeLine{00097\ }
\DoxyCodeLine{00103\ \textcolor{keywordtype}{void}\ \mbox{\hyperlink{led_8h_ab02c6a3a312ce2e008f471310fef8f5b}{LED\_SetLow}}(GPIO\_Type\ *port\_base,\ uint32\_t\ pin);}
\DoxyCodeLine{00104\ }
\DoxyCodeLine{00108\ \textcolor{keywordtype}{void}\ \mbox{\hyperlink{led_8h_a90d3262aad7d8e74c655aecba5bdb8b1}{LED\_SignalReady}}(\textcolor{keywordtype}{void});}
\DoxyCodeLine{00109\ }
\DoxyCodeLine{00113\ \textcolor{keywordtype}{void}\ \mbox{\hyperlink{led_8h_ae4d93582ce6f8960bbbe8771670864f2}{LED\_SignalRecording}}(\textcolor{keywordtype}{void});}
\DoxyCodeLine{00114\ }
\DoxyCodeLine{00118\ \textcolor{keywordtype}{void}\ \mbox{\hyperlink{led_8h_a357ebead2af4aa7710b82477c78c3ae5}{LED\_SignalRecordingStop}}(\textcolor{keywordtype}{void});}
\DoxyCodeLine{00119\ }
\DoxyCodeLine{00123\ \textcolor{keywordtype}{void}\ \mbox{\hyperlink{led_8h_a051c422ce8dcca2df8022a718fa9e85c}{LED\_SignalBackUpPowerAvailable}}(\textcolor{keywordtype}{void});}
\DoxyCodeLine{00124\ }
\DoxyCodeLine{00128\ \textcolor{keywordtype}{void}\ \mbox{\hyperlink{led_8h_aeab72eb69dcad626cad6ab8d18f5b7f7}{LED\_SignalLowMemory}}(\textcolor{keywordtype}{void});}
\DoxyCodeLine{00129\ }
\DoxyCodeLine{00133\ \textcolor{keywordtype}{void}\ \mbox{\hyperlink{led_8h_a13c3d29b05f96fd3490c9b7680f7df08}{LED\_SignalError}}(\textcolor{keywordtype}{void});}
\DoxyCodeLine{00134\ }
\DoxyCodeLine{00138\ \textcolor{keywordtype}{void}\ \mbox{\hyperlink{led_8h_ac6978cdce3f5c99d7cd85a6991a5394a}{LED\_SignalFlush}}(\textcolor{keywordtype}{void});}
\DoxyCodeLine{00139\ }
\DoxyCodeLine{00143\ \textcolor{keywordtype}{void}\ \mbox{\hyperlink{led_8h_a790afc5a8ed07437a4788698ca9afe45}{LED\_ClearSignalFlush}}(\textcolor{keywordtype}{void});}
\DoxyCodeLine{00144\ }
\DoxyCodeLine{00145\ \textcolor{preprocessor}{\#endif\ }\textcolor{comment}{/*\ LED\_H\_\ */}\textcolor{preprocessor}{}}

\end{DoxyCode}

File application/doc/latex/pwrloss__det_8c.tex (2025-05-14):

\doxysection{src/pwrloss\+\_\+det.c File Reference}
\hypertarget{pwrloss__det_8c}{}\label{pwrloss__det_8c}\index{src/pwrloss\_det.c@{src/pwrloss\_det.c}}
{\ttfamily \#include "{}pwrloss\+\_\+det.\+h"{}}\newline
{\ttfamily \#include "{}record.\+h"{}}\newline
\doxysubsubsection*{Macros}
\begin{DoxyCompactItemize}
\item 
\#define \mbox{\hyperlink{pwrloss__det_8c_ab87b58674d2ede9f6589fd9a90e27c90}{REF\+\_\+\+VOLTAGE}}~0x\+FFu
\item 
\#define \mbox{\hyperlink{pwrloss__det_8c_a1076ce1f23d35e63137e2b4133f499da}{TRIGGER\+\_\+\+VOLTAGE}}~0x\+E1
\end{DoxyCompactItemize}
\doxysubsubsection*{Functions}
\begin{DoxyCompactItemize}
\item 
void \mbox{\hyperlink{pwrloss__det_8c_a959b3da8b96385f685f18d445102163c}{CTIMER4\+\_\+\+IRQHandler}} (void)
\item 
void \mbox{\hyperlink{pwrloss__det_8c_a91fcfb8aaaf84fcc82fcbc7ca6837ca9}{HSCMP1\+\_\+\+IRQHandler}} (void)
\item 
void \mbox{\hyperlink{pwrloss__det_8c_a640dcd500f29a2a077dbc83532cde9e5}{PWRLOSS\+\_\+\+Detection\+Init}} (void)
\begin{DoxyCompactList}\small\item\em Initializes Power Loss Detection Components. \end{DoxyCompactList}\end{DoxyCompactItemize}

\doxysubsection{Macro Definition Documentation}
\Hypertarget{pwrloss__det_8c_ab87b58674d2ede9f6589fd9a90e27c90}\index{pwrloss\_det.c@{pwrloss\_det.c}!REF\_VOLTAGE@{REF\_VOLTAGE}}
\index{REF\_VOLTAGE@{REF\_VOLTAGE}!pwrloss\_det.c@{pwrloss\_det.c}}
\doxysubsubsection{\texorpdfstring{REF\_VOLTAGE}{REF\_VOLTAGE}}
{\footnotesize\ttfamily \label{pwrloss__det_8c_ab87b58674d2ede9f6589fd9a90e27c90} 
\#define REF\+\_\+\+VOLTAGE~0x\+FFu}

\Hypertarget{pwrloss__det_8c_a1076ce1f23d35e63137e2b4133f499da}\index{pwrloss\_det.c@{pwrloss\_det.c}!TRIGGER\_VOLTAGE@{TRIGGER\_VOLTAGE}}
\index{TRIGGER\_VOLTAGE@{TRIGGER\_VOLTAGE}!pwrloss\_det.c@{pwrloss\_det.c}}
\doxysubsubsection{\texorpdfstring{TRIGGER\_VOLTAGE}{TRIGGER\_VOLTAGE}}
{\footnotesize\ttfamily \label{pwrloss__det_8c_a1076ce1f23d35e63137e2b4133f499da} 
\#define TRIGGER\+\_\+\+VOLTAGE~0x\+E1}

\doxysubsection{Function Documentation}
\Hypertarget{pwrloss__det_8c_a959b3da8b96385f685f18d445102163c}\index{pwrloss\_det.c@{pwrloss\_det.c}!CTIMER4\_IRQHandler@{CTIMER4\_IRQHandler}}
\index{CTIMER4\_IRQHandler@{CTIMER4\_IRQHandler}!pwrloss\_det.c@{pwrloss\_det.c}}
\doxysubsubsection{\texorpdfstring{CTIMER4\_IRQHandler()}{CTIMER4\_IRQHandler()}}
{\footnotesize\ttfamily \label{pwrloss__det_8c_a959b3da8b96385f685f18d445102163c} 
void CTIMER4\+\_\+\+IRQHandler (\begin{DoxyParamCaption}\item[{void}]{}{}\end{DoxyParamCaption})}

MISRA Deviation\+: Rule 10.\+3 \mbox{[}Required\mbox{]} Suppress\+: Conversion From enum To unsigned32. Justification\+: The Enum Value is Part of The NXP SDK and is Intentionally Used in Context as a Bitmask Flag For Hardware Status Registers.\Hypertarget{pwrloss__det_8c_a91fcfb8aaaf84fcc82fcbc7ca6837ca9}\index{pwrloss\_det.c@{pwrloss\_det.c}!HSCMP1\_IRQHandler@{HSCMP1\_IRQHandler}}
\index{HSCMP1\_IRQHandler@{HSCMP1\_IRQHandler}!pwrloss\_det.c@{pwrloss\_det.c}}
\doxysubsubsection{\texorpdfstring{HSCMP1\_IRQHandler()}{HSCMP1\_IRQHandler()}}
{\footnotesize\ttfamily \label{pwrloss__det_8c_a91fcfb8aaaf84fcc82fcbc7ca6837ca9} 
void HSCMP1\+\_\+\+IRQHandler (\begin{DoxyParamCaption}\item[{void}]{}{}\end{DoxyParamCaption})}

\Hypertarget{pwrloss__det_8c_a640dcd500f29a2a077dbc83532cde9e5}\index{pwrloss\_det.c@{pwrloss\_det.c}!PWRLOSS\_DetectionInit@{PWRLOSS\_DetectionInit}}
\index{PWRLOSS\_DetectionInit@{PWRLOSS\_DetectionInit}!pwrloss\_det.c@{pwrloss\_det.c}}
\doxysubsubsection{\texorpdfstring{PWRLOSS\_DetectionInit()}{PWRLOSS\_DetectionInit()}}
{\footnotesize\ttfamily \label{pwrloss__det_8c_a640dcd500f29a2a077dbc83532cde9e5} 
void PWRLOSS\+\_\+\+Detection\+Init (\begin{DoxyParamCaption}\item[{void}]{}{}\end{DoxyParamCaption})}

Initializes Power Loss Detection Components. 

This Function Configures The Comparator (LPCMP) for Monitoring The 5V Power Rail and The Timer (CTIMER4) That Delays The Activation of The Comparator Until The Backup Capacitor Is Fully Charged (\texorpdfstring{$\sim$}{\string~}5tau). After Initialization, The Timer is Started and The Comparator Will Be Enabled Upon Timer Match Event.

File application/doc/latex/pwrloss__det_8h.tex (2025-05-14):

\doxysection{include/pwrloss\+\_\+det.h File Reference}
\hypertarget{pwrloss__det_8h}{}\label{pwrloss__det_8h}\index{include/pwrloss\_det.h@{include/pwrloss\_det.h}}
{\ttfamily \#include "{}fsl\+\_\+lpcmp.\+h"{}}\newline
{\ttfamily \#include "{}fsl\+\_\+spc.\+h"{}}\newline
{\ttfamily \#include "{}led.\+h"{}}\newline
{\ttfamily \#include "{}defs.\+h"{}}\newline
{\ttfamily \#include "{}fsl\+\_\+ctimer.\+h"{}}\newline
\doxysubsubsection*{Macros}
\begin{DoxyCompactItemize}
\item 
\#define \mbox{\hyperlink{pwrloss__det_8h_a7342461d1fcb9a6c8c3ae456bafa61d5}{LPCMP\+\_\+\+BASE}}~CMP1
\begin{DoxyCompactList}\small\item\em Base Address of The Low-\/\+Power Comparator (LPCMP). \end{DoxyCompactList}\item 
\#define \mbox{\hyperlink{pwrloss__det_8h_af9b640fbdea56d26a90253d0fe4fc220}{LPCMP\+\_\+\+USER\+\_\+\+CHANNEL}}~0x02
\begin{DoxyCompactList}\small\item\em Comparator Input Channel Used For 5V Monitoring. \end{DoxyCompactList}\item 
\#define \mbox{\hyperlink{pwrloss__det_8h_a4f642f96675b7192c91d864dbf7dcb38}{LPCMP\+\_\+\+DAC\+\_\+\+CHANNEL}}~0x07
\begin{DoxyCompactList}\small\item\em Comparator Internal DAC Reference Channel. \end{DoxyCompactList}\item 
\#define \mbox{\hyperlink{pwrloss__det_8h_a648509c09a6537239f18c77e34597db7}{LPCMP\+\_\+\+IRQ\+\_\+\+ID}}~HSCMP1\+\_\+\+IRQn
\begin{DoxyCompactList}\small\item\em IRQ Number for The Comparator Peripheral. \end{DoxyCompactList}\item 
\#define \mbox{\hyperlink{pwrloss__det_8h_a23e04ddbaa1a9179a401e01986f5bbea}{SPC\+\_\+\+BASE}}~SPC0
\begin{DoxyCompactList}\small\item\em Base Address of The Supply Power Controller (SPC). \end{DoxyCompactList}\item 
\#define \mbox{\hyperlink{pwrloss__det_8h_ab7786fe5adcd1d885491257b0ebc27b8}{CTIMER}}~CTIMER4
\begin{DoxyCompactList}\small\item\em Timer Used To Control Delayed Activation of Power Loss Detection. \end{DoxyCompactList}\item 
\#define \mbox{\hyperlink{pwrloss__det_8h_a31628cf818c8dea7d3311a53c65cb924}{CTIMER\+\_\+\+MAT0\+\_\+\+OUT}}~k\+CTIMER\+\_\+\+Match\+\_\+0
\begin{DoxyCompactList}\small\item\em Timer Match Output Channel 0. \end{DoxyCompactList}\item 
\#define \mbox{\hyperlink{pwrloss__det_8h_a54ee2e0d23f2366ac80ccbdda3808b70}{CTIMER\+\_\+\+EMT0\+\_\+\+OUT}}~(1u $<$$<$ k\+CTIMER\+\_\+\+Match\+\_\+0)
\begin{DoxyCompactList}\small\item\em Timer External Match Output Mask For Channel 0. \end{DoxyCompactList}\item 
\#define \mbox{\hyperlink{pwrloss__det_8h_a282d828757fa193e5c9a4e671867cf34}{CTIMER\+\_\+\+CLK\+\_\+\+FREQ}}~CLOCK\+\_\+\+Get\+CTimer\+Clk\+Freq(4U)
\begin{DoxyCompactList}\small\item\em Clock Frequency Retrieval Macro For The Timer Instance. \end{DoxyCompactList}\end{DoxyCompactItemize}
\doxysubsubsection*{Functions}
\begin{DoxyCompactItemize}
\item 
void \mbox{\hyperlink{pwrloss__det_8h_a640dcd500f29a2a077dbc83532cde9e5}{PWRLOSS\+\_\+\+Detection\+Init}} (void)
\begin{DoxyCompactList}\small\item\em Initializes Power Loss Detection Components. \end{DoxyCompactList}\end{DoxyCompactItemize}

\doxysubsection{Macro Definition Documentation}
\Hypertarget{pwrloss__det_8h_ab7786fe5adcd1d885491257b0ebc27b8}\index{pwrloss\_det.h@{pwrloss\_det.h}!CTIMER@{CTIMER}}
\index{CTIMER@{CTIMER}!pwrloss\_det.h@{pwrloss\_det.h}}
\doxysubsubsection{\texorpdfstring{CTIMER}{CTIMER}}
{\footnotesize\ttfamily \label{pwrloss__det_8h_ab7786fe5adcd1d885491257b0ebc27b8} 
\#define CTIMER~CTIMER4}

Timer Used To Control Delayed Activation of Power Loss Detection. 

The Comparator is Enabled After a Delay of 5tau, Which Corresponds To The Time Needed For The Backup Capacitor To Become Fully Charged. This Delay Ensures Valid Detection of Power Drop Events and Avoids False Triggering During Startup. \Hypertarget{pwrloss__det_8h_a282d828757fa193e5c9a4e671867cf34}\index{pwrloss\_det.h@{pwrloss\_det.h}!CTIMER\_CLK\_FREQ@{CTIMER\_CLK\_FREQ}}
\index{CTIMER\_CLK\_FREQ@{CTIMER\_CLK\_FREQ}!pwrloss\_det.h@{pwrloss\_det.h}}
\doxysubsubsection{\texorpdfstring{CTIMER\_CLK\_FREQ}{CTIMER\_CLK\_FREQ}}
{\footnotesize\ttfamily \label{pwrloss__det_8h_a282d828757fa193e5c9a4e671867cf34} 
\#define CTIMER\+\_\+\+CLK\+\_\+\+FREQ~CLOCK\+\_\+\+Get\+CTimer\+Clk\+Freq(4U)}

Clock Frequency Retrieval Macro For The Timer Instance. 

\Hypertarget{pwrloss__det_8h_a54ee2e0d23f2366ac80ccbdda3808b70}\index{pwrloss\_det.h@{pwrloss\_det.h}!CTIMER\_EMT0\_OUT@{CTIMER\_EMT0\_OUT}}
\index{CTIMER\_EMT0\_OUT@{CTIMER\_EMT0\_OUT}!pwrloss\_det.h@{pwrloss\_det.h}}
\doxysubsubsection{\texorpdfstring{CTIMER\_EMT0\_OUT}{CTIMER\_EMT0\_OUT}}
{\footnotesize\ttfamily \label{pwrloss__det_8h_a54ee2e0d23f2366ac80ccbdda3808b70} 
\#define CTIMER\+\_\+\+EMT0\+\_\+\+OUT~(1u $<$$<$ k\+CTIMER\+\_\+\+Match\+\_\+0)}

Timer External Match Output Mask For Channel 0. 

\Hypertarget{pwrloss__det_8h_a31628cf818c8dea7d3311a53c65cb924}\index{pwrloss\_det.h@{pwrloss\_det.h}!CTIMER\_MAT0\_OUT@{CTIMER\_MAT0\_OUT}}
\index{CTIMER\_MAT0\_OUT@{CTIMER\_MAT0\_OUT}!pwrloss\_det.h@{pwrloss\_det.h}}
\doxysubsubsection{\texorpdfstring{CTIMER\_MAT0\_OUT}{CTIMER\_MAT0\_OUT}}
{\footnotesize\ttfamily \label{pwrloss__det_8h_a31628cf818c8dea7d3311a53c65cb924} 
\#define CTIMER\+\_\+\+MAT0\+\_\+\+OUT~k\+CTIMER\+\_\+\+Match\+\_\+0}

Timer Match Output Channel 0. 

\Hypertarget{pwrloss__det_8h_a7342461d1fcb9a6c8c3ae456bafa61d5}\index{pwrloss\_det.h@{pwrloss\_det.h}!LPCMP\_BASE@{LPCMP\_BASE}}
\index{LPCMP\_BASE@{LPCMP\_BASE}!pwrloss\_det.h@{pwrloss\_det.h}}
\doxysubsubsection{\texorpdfstring{LPCMP\_BASE}{LPCMP\_BASE}}
{\footnotesize\ttfamily \label{pwrloss__det_8h_a7342461d1fcb9a6c8c3ae456bafa61d5} 
\#define LPCMP\+\_\+\+BASE~CMP1}

Base Address of The Low-\/\+Power Comparator (LPCMP). 

Used To Detect Loss of Primary 5V Supply. If The Voltage Drops Below a Defined Threshold, It Triggers a Transition To Backup Power Mode for Safe Data Preservation. \Hypertarget{pwrloss__det_8h_a4f642f96675b7192c91d864dbf7dcb38}\index{pwrloss\_det.h@{pwrloss\_det.h}!LPCMP\_DAC\_CHANNEL@{LPCMP\_DAC\_CHANNEL}}
\index{LPCMP\_DAC\_CHANNEL@{LPCMP\_DAC\_CHANNEL}!pwrloss\_det.h@{pwrloss\_det.h}}
\doxysubsubsection{\texorpdfstring{LPCMP\_DAC\_CHANNEL}{LPCMP\_DAC\_CHANNEL}}
{\footnotesize\ttfamily \label{pwrloss__det_8h_a4f642f96675b7192c91d864dbf7dcb38} 
\#define LPCMP\+\_\+\+DAC\+\_\+\+CHANNEL~0x07}

Comparator Internal DAC Reference Channel. 

\Hypertarget{pwrloss__det_8h_a648509c09a6537239f18c77e34597db7}\index{pwrloss\_det.h@{pwrloss\_det.h}!LPCMP\_IRQ\_ID@{LPCMP\_IRQ\_ID}}
\index{LPCMP\_IRQ\_ID@{LPCMP\_IRQ\_ID}!pwrloss\_det.h@{pwrloss\_det.h}}
\doxysubsubsection{\texorpdfstring{LPCMP\_IRQ\_ID}{LPCMP\_IRQ\_ID}}
{\footnotesize\ttfamily \label{pwrloss__det_8h_a648509c09a6537239f18c77e34597db7} 
\#define LPCMP\+\_\+\+IRQ\+\_\+\+ID~HSCMP1\+\_\+\+IRQn}

IRQ Number for The Comparator Peripheral. 

\Hypertarget{pwrloss__det_8h_af9b640fbdea56d26a90253d0fe4fc220}\index{pwrloss\_det.h@{pwrloss\_det.h}!LPCMP\_USER\_CHANNEL@{LPCMP\_USER\_CHANNEL}}
\index{LPCMP\_USER\_CHANNEL@{LPCMP\_USER\_CHANNEL}!pwrloss\_det.h@{pwrloss\_det.h}}
\doxysubsubsection{\texorpdfstring{LPCMP\_USER\_CHANNEL}{LPCMP\_USER\_CHANNEL}}
{\footnotesize\ttfamily \label{pwrloss__det_8h_af9b640fbdea56d26a90253d0fe4fc220} 
\#define LPCMP\+\_\+\+USER\+\_\+\+CHANNEL~0x02}

Comparator Input Channel Used For 5V Monitoring. 

\Hypertarget{pwrloss__det_8h_a23e04ddbaa1a9179a401e01986f5bbea}\index{pwrloss\_det.h@{pwrloss\_det.h}!SPC\_BASE@{SPC\_BASE}}
\index{SPC\_BASE@{SPC\_BASE}!pwrloss\_det.h@{pwrloss\_det.h}}
\doxysubsubsection{\texorpdfstring{SPC\_BASE}{SPC\_BASE}}
{\footnotesize\ttfamily \label{pwrloss__det_8h_a23e04ddbaa1a9179a401e01986f5bbea} 
\#define SPC\+\_\+\+BASE~SPC0}

Base Address of The Supply Power Controller (SPC). 

For Activation Analog Modules. 

\doxysubsection{Function Documentation}
\Hypertarget{pwrloss__det_8h_a640dcd500f29a2a077dbc83532cde9e5}\index{pwrloss\_det.h@{pwrloss\_det.h}!PWRLOSS\_DetectionInit@{PWRLOSS\_DetectionInit}}
\index{PWRLOSS\_DetectionInit@{PWRLOSS\_DetectionInit}!pwrloss\_det.h@{pwrloss\_det.h}}
\doxysubsubsection{\texorpdfstring{PWRLOSS\_DetectionInit()}{PWRLOSS\_DetectionInit()}}
{\footnotesize\ttfamily \label{pwrloss__det_8h_a640dcd500f29a2a077dbc83532cde9e5} 
void PWRLOSS\+\_\+\+Detection\+Init (\begin{DoxyParamCaption}\item[{void}]{}{}\end{DoxyParamCaption})}

Initializes Power Loss Detection Components. 

This Function Configures The Comparator (LPCMP) for Monitoring The 5V Power Rail and The Timer (CTIMER4) That Delays The Activation of The Comparator Until The Backup Capacitor Is Fully Charged (\texorpdfstring{$\sim$}{\string~}5tau). After Initialization, The Timer is Started and The Comparator Will Be Enabled Upon Timer Match Event.

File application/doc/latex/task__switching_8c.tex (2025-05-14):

\doxysection{src/task\+\_\+switching.c File Reference}
\hypertarget{task__switching_8c}{}\label{task__switching_8c}\index{src/task\_switching.c@{src/task\_switching.c}}
{\ttfamily \#include "{}mass\+\_\+storage.\+h"{}}\newline
\doxysubsubsection*{Functions}
\begin{DoxyCompactItemize}
\item 
usb\+\_\+device\+\_\+notification\+\_\+t \mbox{\hyperlink{task__switching_8c_ab4bb1b4063898f52aa390037fc37db81}{USB\+\_\+\+State}} (usb\+\_\+device\+\_\+struct\+\_\+t \texorpdfstring{$\ast$}{*}p\+Device\+Handle)
\begin{DoxyCompactList}\small\item\em Checks If Application USB Is Attached To Digital Data Logger. \end{DoxyCompactList}\end{DoxyCompactItemize}

\doxysubsection{Function Documentation}
\Hypertarget{task__switching_8c_ab4bb1b4063898f52aa390037fc37db81}\index{task\_switching.c@{task\_switching.c}!USB\_State@{USB\_State}}
\index{USB\_State@{USB\_State}!task\_switching.c@{task\_switching.c}}
\doxysubsubsection{\texorpdfstring{USB\_State()}{USB\_State()}}
{\footnotesize\ttfamily \label{task__switching_8c_ab4bb1b4063898f52aa390037fc37db81} 
usb\+\_\+device\+\_\+notification\+\_\+t USB\+\_\+\+State (\begin{DoxyParamCaption}\item[{usb\+\_\+device\+\_\+struct\+\_\+t \texorpdfstring{$\ast$}{*}}]{p\+Device\+Handle}{}\end{DoxyParamCaption})}

Checks If Application USB Is Attached To Digital Data Logger. 

Checks Thru USB OTG (USB On-\/\+To-\/\+Go) SC Register. 
\begin{DoxyParams}[1]{Parameters}
\mbox{\texttt{ in}}  & {\em p\+Device\+Handle} & Pointer to USB Device Handle (e.\+g. Mass Storage Handle).\\
\hline
\end{DoxyParams}
\begin{DoxyReturn}{Returns}
k\+USB\+\_\+\+Device\+Notify\+Attach if USB Is Attached Otherwise Returns k\+USB\+\_\+\+Device\+Notify\+Detach. 
\end{DoxyReturn}

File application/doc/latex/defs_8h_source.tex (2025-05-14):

\doxysection{defs.\+h}
\hypertarget{defs_8h_source}{}\label{defs_8h_source}\index{include/defs.h@{include/defs.h}}
\mbox{\hyperlink{defs_8h}{Go to the documentation of this file.}}
\begin{DoxyCode}{0}
\DoxyCodeLine{00001\ \textcolor{comment}{/******************************}}
\DoxyCodeLine{00002\ \textcolor{comment}{\ *\ \ Project:\ \ \ \ \ \ \ \ NXP\ MCXN947\ Datalogger}}
\DoxyCodeLine{00003\ \textcolor{comment}{\ *\ \ File\ Name:\ \ \ \ \ \ defs.h}}
\DoxyCodeLine{00004\ \textcolor{comment}{\ *\ \ Author:\ \ \ \ \ \ \ \ \ Tomas\ Dolak}}
\DoxyCodeLine{00005\ \textcolor{comment}{\ *\ \ Date:\ \ \ \ \ \ \ \ \ \ \ 22.09.2024}}
\DoxyCodeLine{00006\ \textcolor{comment}{\ *\ \ Description:\ \ \ \ Header\ File\ Providing\ Definitions\ To\ Set\ Up\ The\ Project.}}
\DoxyCodeLine{00007\ \textcolor{comment}{\ *}}
\DoxyCodeLine{00008\ \textcolor{comment}{\ *\ ****************************/}}
\DoxyCodeLine{00009\ }
\DoxyCodeLine{00010\ \textcolor{comment}{/******************************}}
\DoxyCodeLine{00011\ \textcolor{comment}{\ *\ \ @package\ \ \ \ \ \ \ \ NXP\ MCXN947\ Datalogger}}
\DoxyCodeLine{00012\ \textcolor{comment}{\ *\ \ @file\ \ \ \ \ \ \ \ \ \ \ defs.h}}
\DoxyCodeLine{00013\ \textcolor{comment}{\ *\ \ @author\ \ \ \ \ \ \ \ \ Tomas\ Dolak}}
\DoxyCodeLine{00014\ \textcolor{comment}{\ *\ \ @date\ \ \ \ \ \ \ \ \ \ \ 22.09.2024}}
\DoxyCodeLine{00015\ \textcolor{comment}{\ *\ \ @brief\ \ \ \ \ \ \ \ \ \ Header\ File\ Providing\ Definitions\ To\ Set\ Up\ The\ Project.}}
\DoxyCodeLine{00016\ \textcolor{comment}{\ *\ ****************************/}}
\DoxyCodeLine{00017\ }
\DoxyCodeLine{00018\ \textcolor{preprocessor}{\#ifndef\ DEFS\_H\_}}
\DoxyCodeLine{00019\ \textcolor{preprocessor}{\#define\ DEFS\_H\_}}
\DoxyCodeLine{00020\ }
\DoxyCodeLine{00021\ \textcolor{comment}{/*******************************************************************************}}
\DoxyCodeLine{00022\ \textcolor{comment}{\ *\ Includes}}
\DoxyCodeLine{00023\ \textcolor{comment}{\ ******************************************************************************/}}
\DoxyCodeLine{00024\ \textcolor{preprocessor}{\#include\ <stdbool.h>}}
\DoxyCodeLine{00025\ }
\DoxyCodeLine{00026\ }
\DoxyCodeLine{00027\ \textcolor{comment}{/*******************************************************************************}}
\DoxyCodeLine{00028\ \textcolor{comment}{\ *\ Definitions}}
\DoxyCodeLine{00029\ \textcolor{comment}{\ ******************************************************************************/}}
\DoxyCodeLine{00030\ \textcolor{preprocessor}{\#define\ NOT\_IMPLEMENTED\ \ \ \ \ \ \ \ \ \ \ \ \ \#error\ "{}This\ Feature\ Is\ Not\ Implemented!"{}}}
\DoxyCodeLine{00031\ }
\DoxyCodeLine{00035\ \textcolor{preprocessor}{\#define\ MSC\_STACK\_SIZE\ \ \ \ \ \ \ \ ((uint32\_t)(5000UL\ /\ (uint32\_t)sizeof(portSTACK\_TYPE)))}}
\DoxyCodeLine{00036\ }
\DoxyCodeLine{00040\ \textcolor{preprocessor}{\#define\ RECORD\_STACK\_SIZE\ \ \ \ \ ((uint32\_t)(5000UL\ /\ (uint32\_t)sizeof(portSTACK\_TYPE)))}}
\DoxyCodeLine{00041\ }
\DoxyCodeLine{00045\ \textcolor{preprocessor}{\#define\ MSC\_ENABLED\ \ \ \ \ \ \ \ \ \ \ \ \ \ \ \ \ (true)}}
\DoxyCodeLine{00046\ }
\DoxyCodeLine{00051\ \textcolor{preprocessor}{\#define\ INFO\_ENABLED\ \ \ \ \ \ \ \ \ \ \ \ \ \ \ \ (false)}}
\DoxyCodeLine{00052\ }
\DoxyCodeLine{00057\ \textcolor{preprocessor}{\#define\ DEBUG\_ENABLED\ \ \ \ \ \ \ \ \ \ \ \ \ \ \ (false)}}
\DoxyCodeLine{00058\ }
\DoxyCodeLine{00062\ \textcolor{preprocessor}{\#define\ UART\_FIFO\_ENABLED\ \ \ \ \ \ \ \ \ \ \ (true)}}
\DoxyCodeLine{00063\ }
\DoxyCodeLine{00067\ \textcolor{preprocessor}{\#define\ UART\_FIFO\_LENGHT\ \ \ \ \ \ \ \ \ \ \ \ (4u)}}
\DoxyCodeLine{00068\ }
\DoxyCodeLine{00072\ \textcolor{preprocessor}{\#define\ UART\_PRINT\_ENABLED\ \ \ \ \ \ \ \ \ \ (false)}}
\DoxyCodeLine{00073\ }
\DoxyCodeLine{00077\ \textcolor{preprocessor}{\#define\ PWRLOSS\_DETECTION\_ENABLED\ \ \ (true)}}
\DoxyCodeLine{00078\ }
\DoxyCodeLine{00082\ \textcolor{preprocessor}{\#define\ PWRLOSS\_TEST\_GPIOS\ \ \ \ \ \ \ \ \ \ (false)}}
\DoxyCodeLine{00083\ }
\DoxyCodeLine{00088\ \textcolor{preprocessor}{\#define\ TAU5\ \ \ \ \ \ \ \ \ \ \ \ \ \ \ \ \ \ \ \ \ \ \ \ 16.5}}
\DoxyCodeLine{00089\ }
\DoxyCodeLine{00094\ \textcolor{preprocessor}{\#define\ PWRLOSS\_DET\_ACTIVE\_IN\_TIME\ \ TAU5}}
\DoxyCodeLine{00095\ }
\DoxyCodeLine{00099\ \textcolor{preprocessor}{\#define\ UART\_RECEIVE\_PRIO\ \ \ \ \ \ \ \ \ \ \ (6U)}}
\DoxyCodeLine{00100\ }
\DoxyCodeLine{00104\ \textcolor{preprocessor}{\#define\ PWRLOSS\_DET\_PRIO\ \ \ \ \ \ \ \ \ \ \ \ (5U)}}
\DoxyCodeLine{00105\ }
\DoxyCodeLine{00109\ \textcolor{preprocessor}{\#define\ PWRLOSS\_TIMER\_PRIO\ \ \ \ \ \ \ \ \ \ (7U)}}
\DoxyCodeLine{00110\ }
\DoxyCodeLine{00111\ }
\DoxyCodeLine{00115\ \textcolor{preprocessor}{\#define\ TEMPERATURE\_MEAS\_ENABLED\ \ \ \ (false)}}
\DoxyCodeLine{00116\ }
\DoxyCodeLine{00120\ \textcolor{preprocessor}{\#define\ CONTROL\_LED\_ENABLED\ \ \ \ \ \ \ \ \ (true)}}
\DoxyCodeLine{00121\ }
\DoxyCodeLine{00122\ }
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

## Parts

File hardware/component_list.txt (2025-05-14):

Caption:
-----------------------------------------------------------------------------------------------------------------------------------
Note: Basic Resistors and Capacitors Are Not Included In This Component List.
-----------------------------------
- Quantity Name (Other Information)
	- link (mouser): ...
----------------------------------------------------------------------------------------------------------------------------------------------------------------------
Pin Headers:
----------------------------------------------------------------------------------------------------------------------------------------------------------------------
- 2pcs SSQ-108-03-G-D (16 pin)
	- link (vendor): 	https://kinetictest.samtec.com/partnumber/ssq-108-03-g-d?vendor=
	- link (mouser):	https://cz.mouser.com/ProductDetail/Samtec/SSQ-108-03-G-D?qs=rU5fayqh%252BE0RwWDEJ6pPUQ%3D%3D
	- MOUSER number: 	200-SSQ10803GD

- 1pcs SSQ-106-03-S-D (12 Pin)
	- link (vendor): 	https://kinetictest.samtec.com/partnumber/ssq-106-03-s-d?vendor=
	- link (mouser):	https://cz.mouser.com/ProductDetail/Samtec/SSQ-106-03-T-D?qs=rU5fayqh%252BE1nrbBaxRMk2g%3D%3D
	- MOUSER number:	200-SSQ10603SD

- 1pcs SSQ-114-03-T-D (28 pin)
	- link (vendor): 	https://kinetictest.samtec.com/partnumber/ssq-114-03-g-d?vendor=
	- link (mouser):	https://cz.mouser.com/ProductDetail/Samtec/SSQ-114-03-T-D?qs=rU5fayqh%252BE3GMP3i4Q9eOA%3D%3D
	- MOUSER number:	200-SSQ11403TD

- 1pcs SSQ-116-01-G-D (32 pin)
	- link (vendor): 	https://kinetictest.samtec.com/partnumber/ssq-116-01-g-d
	- link (mouser):	https://cz.mouser.com/ProductDetail/Samtec/SSQ-116-01-G-D?qs=rU5fayqh%252BE0IfimSEbywwg%3D%3D
	- MOUSER number:	200-SSQ11601GD

- 1pcs SSQ-110-03-T-D
	- link (vendor): 	https://kinetictest.samtec.com/partnumber/ssq-110-03-t-d
	- link (mouser):	https://cz.mouser.com/ProductDetail/Samtec/SSQ-110-03-T-D?qs=rU5fayqh%252BE2PVxAFHKyYdw%3D%3D
	- MOUSER number:	200-SSQ11003TD

- 1pcs M20-7830342 (10 pin) [For Control LEDs]
	- link (mouser):	https://cz.mouser.com/ProductDetail/Harwin/M20-7830342?qs=Jph8NoUxIfXRffijnsn9uQ%3D%3D
	- MOUSER number:	855-M20-7830342

----------------------------------------------------------------------------------------------------------------------------------------------------------------------
Real-Time Circuit:
------------------------------------------------------	----------------------------------------------------------------------------------------------------------------
- 2pcs DS3231M+:
	- link (mouser):	https://cz.mouser.com/ProductDetail/Analog-Devices-Maxim-Integrated/DS3231M%2b?qs=Bakm8ERcljpd4MQpcnSykw%3D%3D
	- MOUSER number:	700-DS3231M+

----------------------------------------------------------------------------------------------------------------------------------------------------------------------
Back-Up Power:
----------------------------------------------------------------------------------------------------------------------------------------------------------------------
- 3pcs KYOCERA AVX - SCMR14G334SRBB0
	- link (mouser): 	https://cz.mouser.com/ProductDetail/KYOCERA-AVX/SCMR14G334SRBB0?qs=qSfuJ%252Bfl%2Fd4Npf0NpjEggg%3D%3D
	- MOUSER number:	581-SCMR14G334SRBB0

- 4pcs RSX301L-30DDTE25
	- link (mouser): 	https://cz.mouser.com/ProductDetail/ROHM-Semiconductor/RSX301L-30DDTE25?qs=YCa%2FAAYMW01WyKek9N1fLg%3D%3D
	- MOUSER number:	755-RSX301L-30DDTE25

- 7pcs BC546
	- link (mouser): 	https://cz.mouser.com/ProductDetail/onsemi-Fairchild/BC546ABU?qs=4YdYnegEbZUO%2FGL%2FQQD%2FXw%3D%3D
	- MOUSER number:	512-BC546ABU

----------------------------------------------------------------------------------------------------------------------------------------------------------------------
SDHC Card Slot:
----------------------------------------------------------------------------------------------------------------------------------------------------------------------
- 2pcs MEM2075-00-140-01-A
	- link (mouser): 	https://cz.mouser.com/ProductDetail/GCT/MEM2075-00-140-01-A?qs=KUoIvG%2F9IlZvfWpeERlq3Q%3D%3D
	- MOUSER number:	640-MEM20750014001A

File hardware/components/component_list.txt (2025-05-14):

Pin Headers:
- 2x SSQ-108-03-G-D (16 pin)
	- link: https://kinetictest.samtec.com/partnumber/ssq-108-03-g-d?vendor=
	- link: https://cz.mouser.com/ProductDetail/Samtec/SSQ-108-03-G-D?qs=rU5fayqh%252BE0RwWDEJ6pPUQ%3D%3D
- 1x SSQ-106-03-S-D (12 Pin)
	- link: https://kinetictest.samtec.com/partnumber/ssq-106-03-s-d?vendor=
	- link: https://cz.mouser.com/ProductDetail/Samtec/SSQ-106-03-T-D?qs=rU5fayqh%252BE1nrbBaxRMk2g%3D%3D
- 1x SSQ-114-03-T-D (28 pin)
	- link: https://kinetictest.samtec.com/partnumber/ssq-114-03-g-d?vendor=
	- link: https://cz.mouser.com/ProductDetail/Samtec/SSQ-114-03-T-D?qs=rU5fayqh%252BE3GMP3i4Q9eOA%3D%3D
- 1x SSQ-116-01-G-D (32 pin)
	- link: https://kinetictest.samtec.com/partnumber/ssq-116-01-g-d
	- link: https://cz.mouser.com/ProductDetail/Samtec/SSQ-116-01-G-D?qs=rU5fayqh%252BE0IfimSEbywwg%3D%3D
- 1x SSQ-110-03-T-D
	- link: https://kinetictest.samtec.com/partnumber/ssq-108-03-t-d?vendor=
	- link: https://cz.mouser.com/ProductDetail/Samtec/SSQ-110-03-T-D?qs=rU5fayqh%252BE2PVxAFHKyYdw%3D%3D

Real-Time Circuit
- 1x DS3231M+:
	- link: https://cz.mouser.com/ProductDetail/Analog-Devices-Maxim-Integrated/DS3231M%2b?qs=Bakm8ERcljpd4MQpcnSykw%3D%3D

Back-Up Power:
- KYOCERA AVX - SCMR14G334SRBB0
	- link: https://cz.mouser.com/ProductDetail/KYOCERA-AVX/SCMR14G334SRBB0?qs=qSfuJ%252Bfl%2Fd4Npf0NpjEggg%3D%3D
- KYOCERA AVX - SCMR14G334SRBA0
	- link: https://cz.mouser.com/ProductDetail/KYOCERA-AVX/SCMR14G334SRBA0?qs=qSfuJ%252Bfl%2Fd5ygRCUu015BA%3D%3D

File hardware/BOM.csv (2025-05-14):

Reference | Value | Datasheet | Footprint | Qty | DNP
BT1 | RTC_Battery | ~ | Battery:Battery_Panasonic_CR2032-HFN_Horizontal_CircularHoles | 1
C1,C2 | 0.33F | https://cz.mouser.com/ProductDetail/581-SCMT32H755SRBB0 | SuperCapacitors:C_Radial_D8mm_W24mm_L14mm_P13.5mm | 2
C4 | 100n | ~ | Capacitor_SMD:C_1206_3216Metric_Pad1.33x1.80mm_HandSolder | 1
D1 | RSX301L | https://fscdn.rohm.com/en/products/databook/datasheet/discrete/diode/schottky_barrier/rsx301l-30ddte25-e.pdf | Diode_SMD:D_SMA | 1 | DNP
D2 | RSX301L | https://fscdn.rohm.com/en/products/databook/datasheet/discrete/diode/schottky_barrier/rsx301l-30ddte25-e.pdf | Diode_SMD:D_SMA | 1
J1,J3 | SSQ-108-03-T-D | https://suddendocs.samtec.com/catalog_english/ssq_th.pdf | SSQ-xxx-03-T-D:SAMTEC_SSQ-108-XX-X-D | 2
J2 | SSQ-110-03-T-D | https://suddendocs.samtec.com/catalog_english/ssq_th.pdf | SSQ-xxx-03-T-D:SAMTEC_SSQ-110-03-T-D | 1
J4 | SSQ-106-03-T-D | https://suddendocs.samtec.com/catalog_english/ssq_th.pdf | SSQ-xxx-03-T-D:SAMTEC_SSQ-106-03-T-D | 1
J5 | Conn_02x05_Odd_Even | https://cz.mouser.com/datasheet/2/181/M20-783-1133465.pdf | Connector_PinSocket_2.54mm:PinSocket_2x05_P2.54mm_Vertical | 1
J8 | SSQ-114-03-T-D | https://suddendocs.samtec.com/catalog_english/ssq_th.pdf | SSQ-xxx-03-T-D:SAMTEC_SSQ-114-03-T-D | 1
J9 | SSQ-116-03-T-D | https://suddendocs.samtec.com/catalog_english/ssq_th.pdf | SSQ-xxx-03-T-D:SAMTEC_SSQ-116-XX-X-D | 1
Q1,Q2,Q3,Q4,Q5 | BC546 | https://www.onsemi.com/pub/Collateral/BC550-D.pdf | Package_TO_SOT_THT:TO-92_Inline | 5
R1 | 10R | ~ | Resistor_THT:R_Axial_DIN0204_L3.6mm_D1.6mm_P5.08mm_Horizontal | 1 | DNP
R2 | 18k | ~ | Resistor_SMD:R_1206_3216Metric_Pad1.30x1.75mm_HandSolder | 1
R3 | 33k | ~ | Resistor_SMD:R_1206_3216Metric_Pad1.30x1.75mm_HandSolder | 1
R4,R5,R6,R7,R8,R9,R10,R11,R12,R13,R14,R15,R16,R17 | 1k | ~ | Resistor_SMD:R_1206_3216Metric_Pad1.30x1.75mm_HandSolder | 14
R18 | 10R | ~ | Resistor_THT:R_Axial_DIN0204_L3.6mm_D1.6mm_P5.08mm_Horizontal | 1
U1 | DS3231M | http://datasheets.maximintegrated.com/en/ds/DS3231.pdf | Package_SO:SOIC-16W_7.5x10.3mm_P1.27mm | 1
U2 | NEO-7M-MODULE | https://www.mouser.co.uk/datasheet/2/1025/NEO_7_DataSheet__UBX_13003830_-2010064.pdf | Neo7M_Module_Lib:Neo-7M-Module | 1

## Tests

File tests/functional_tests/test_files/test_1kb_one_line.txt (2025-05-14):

ooOooooOOoOOOOooOoOoOOOoooooOoOOooooOOoOOoOoOOooOoooooOoooOoOoOOOOooOOoOoooOoOooOOoooooOOoOOOOoOOoOoOooooOoOOOOooooOoOOOooooOOooOooooOOOOoOOoOoooOooOoOoOOooOoOOoooOOOooOOOooOoOooooOOoOOooOOoOOoOooooOoOoOOoOooOOOoOOooOoOOoOooOooOOOoooooOOOOoOoOOoooOOOoOooOOooOOOOoOOOOooooooooooooOooOOOOoooooooOOOoOooOOooooOOooOOOOooooooOOOoOOOOoOoOOoOOOOOOooooOOOoOOOOOOoOOooooOOooOoOOOOOoOoOOoOooOOOoOoOoOooOooOoOOoOoOOoOOoOoOOooooooOOooooOooOoOOOoOOOOOoOoOooOOOOOOOoooooOOOOOOOOOOOOOooOOooOoOOOoOoOOoooOoOOooOOOoOOoooooOoOoOOoOOoOOOOoOoOOoooOOOOoOoOooOoOooOOOoOoOOOoOOooooOOOOoOoooOoOooooOOOOoOooooOoOOoOooOoooOoOooooOOooooooooooooooOooooOOoOOOoooOoooOOoOooOOOooOOOoOOOoooOOOOOOoOOOooOOoOOOoOOooOOOOoOOOoOooOOooOOoOOOoooOOoOOOOoOOOoooOOOoOoOOooOOoOoOOooOooooOOOOoooOoooOOooOOOoOOOOOOOOOOoOOOOOOoooOoOOoOOOOoOoooOoOOOoOoOOooOOoOoOOOooOOoOoOoOOoOOOOOooooOoOoOOOoooOOOOOOOoOOoOOOOoOOoOoOoOOOOoOoOoooOOooOoOOoOOoOOOooOooOOoOOOooOoooOOooOoOOOoOOoOoOoooooooooOOoooOOOoOOoOooOOOOoOOOooOOooooOoOoOOooOoOoOoOoooOoooOooooooOOooOOOooOoooOOoOoOoOoOOO

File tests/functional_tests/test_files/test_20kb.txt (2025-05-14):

Lorem ipsum dolor sit amet, consectetuer adipiscing elit. Aenean commodo ligula eget dolor. Aenean massa. Cum sociis natoque penatibus et magnis dis parturient montes, nascetur 
ridiculus mus. Donec quam felis, ultricies nec, pellentesque eu, pretium quis, sem. Nulla consequat massa quis enim. Donec pede justo, fringilla vel, aliquet nec, 
vulputate eget, arcu. In enim justo, rhoncus ut, imperdiet a, venenatis vitae, justo. Nullam dictum felis eu pede mollis pretium. Integer tincidunt. Cras dapibus. Vivamus 
elementum semper nisi. Aenean vulputate eleifend tellus. Aenean leo ligula, porttitor eu, consequat vitae, eleifend ac, enim. Aliquam lorem ante, dapibus in, viverra quis, 
feugiat a, tellus. Phasellus viverra nulla ut metus varius laoreet. Quisque rutrum. Aenean imperdiet. Etiam ultricies nisi vel augue. Curabitur ullamcorper ultricies nisi. 
Nam eget dui. Etiam rhoncus. Maecenas tempus, tellus eget condimentum rhoncus, sem quam semper libero, sit amet adipiscing sem neque sed ipsum. Nam quam nunc, blandit vel, luctus 
pulvinar, hendrerit id, lorem. Maecenas nec odio et ante tincidunt tempus. Donec vitae sapien ut libero venenatis faucibus. Nullam quis ante. Etiam sit amet orci eget eros 
faucibus tincidunt. Duis leo. Sed fringilla mauris sit amet nibh. Donec sodales sagittis magna. Sed consequat, leo eget bibendum sodales, augue velit cursus nunc, quis gravida 
magna mi a libero. Fusce vulputate eleifend sapien. Vestibulum purus quam, scelerisque ut, mollis sed, nonummy id, metus. Nullam accumsan lorem in dui. Cras ultricies mi eu 
turpis hendrerit fringilla. Vestibulum ante ipsum primis in faucibus orci luctus et ultrices posuere cubilia Curae; In ac dui quis mi consectetuer lacinia. Nam pretium turpis 
et arcu. Duis arcu tortor, suscipit eget, imperdiet nec, imperdiet iaculis, ipsum. Sed aliquam ultrices mauris. Integer ante arcu, accumsan a, consectetuer eget, posuere ut, mauris. 
Praesent adipiscing. Phasellus ullamcorper ipsum rutrum nunc. Nunc nonummy metus. Vestibulum volutpat pretium libero. Cras id dui. Aenean ut eros et nisl sagittis vestibulum. 
Nullam nulla eros, ultricies sit amet, nonummy id, imperdiet feugiat, pede. Sed lectus. Donec mollis hendrerit risus. Phasellus nec sem in justo pellentesque facilisis. Etiam 
mperdiet imperdiet orci. Nunc nec neque. Phasellus leo dolor, tempus non, auctor et, hendrerit quis, nisi. Curabitur ligula sapien, tincidunt non, euismod vitae, posuere imperdiet, 
leo. Maecenas malesuada. Praesent congue erat at massa. Sed cursus turpis vitae tortor. Donec posuere vulputate arcu. Phasellus accumsan cursus velit. Vestibulum ante ipsum primis 
in faucibus orci luctus et ultrices posuere cubilia Curae; Sed aliquam, nisi quis porttitor congue, elit erat euismod orci, ac placerat dolor lectus quis orci. Phasellus consectetuer 
vestibulum elit. Aenean tellus metus, bibendum sed, posuere ac, mattis non, nunc. Vestibulum fringilla pede sit amet augue. In turpis. Pellentesque posuere. Praesent turpis. 
Aenean posuere, tortor sed cursus feugiat, nunc augue blandit nunc, eu sollicitudin urna dolor sagittis lacus. Donec elit libero, sodales nec, volutpat a, suscipit non, turpis. 
Nullam sagittis. Suspendisse pulvinar, augue ac venenatis condimentum, sem libero volutpat nibh, nec pellentesque velit pede quis nunc. Vestibulum ante ipsum primis in faucibus 
orci luctus et ultrices posuere cubilia Curae; Fusce id purus. Ut varius tincidunt libero. Phasellus dolor. Maecenas vestibulum mollis diam. Pellentesque ut neque. Pellentesque 
habitant morbi tristique senectus et netus et malesuada fames ac turpis egestas. In dui magna, posuere eget, vestibulum et, tempor auctor, justo. In ac felis quis tortor malesuada 
pretium. Pellentesque auctor neque nec urna. Proin sapien ipsum, porta a, auctor quis, euismod ut, mi. Aenean viverra rhoncus pede. Pellentesque habitant morbi tristique senectus et 
netus et malesuada fames ac turpis egestas. Ut non enim eleifend felis pretium feugiat. Vivamus quis mi. Phasellus a est. Phasellus magna. In hac habitasse platea dictumst. Curabitur 
at lacus ac velit ornare lobortis. Curabitur a felis in nunc fringilla tristique. Morbi mattis ullamcorper velit. Phasellus gravida semper nisi. Nullam vel sem. Pellentesque libero 
tortor, tincidunt et, tincidunt eget, semper nec, quam. Sed hendrerit. Morbi ac felis. Nunc egestas, augue at pellentesque laoreet, felis eros vehicula leo, at malesuada velit leo 
quis pede. Donec interdum, metus et hendrerit aliquet, dolor diam sagittis ligula, eget egestas libero turpis vel mi. Nunc nulla. Fusce risus nisl, viverra et, tempor et, pretium 
in, sapien. Donec venenatis vulputate lorem. Morbi nec metus. Phasellus blandit leo ut odio. Maecenas ullamcorper, dui et placerat feugiat, eros pede varius nisi, condimentum viverra 
felis nunc et lorem. Sed magna purus, fermentum eu, tincidunt eu, varius ut, felis. In auctor lobortis lacus. Quisque libero metus, condimentum nec, tempor a, commodo mollis, magna. 
Vestibulum ullamcorper mauris at ligula. Fusce fermentum. Nullam cursus lacinia erat. Praesent blandit laoreet nibh. Fusce convallis metus id felis luctus adipiscing. Pellentesque 
egestas, neque sit amet convallis pulvinar, justo nulla eleifend augue, ac auctor orci leo non est. Quisque id mi. Ut tincidunt tincidunt erat. Etiam feugiat lorem non metus. 
Vestibulum dapibus nunc ac augue. Curabitur vestibulum aliquam leo. Praesent egestas neque eu enim. In hac habitasse platea dictumst. Fusce a quam. Etiam ut purus mattis mauris 
sodales aliquam. Curabitur nisi. Quisque malesuada placerat nisl. Nam ipsum risus, rutrum vitae, vestibulum eu, molestie vel, lacus. Sed augue ipsum, egestas nec, vestibulum et, 
malesuada adipiscing, dui. Vestibulum facilisis, purus nec pulvinar iaculis, ligula mi congue nunc, vitae euismod ligula urna in dolor. Mauris sollicitudin fermentum libero. 
Praesent nonummy mi in odio. Nunc interdum lacus sit amet orci. Vestibulum rutrum, mi nec elementum vehicula, eros quam gravida nisl, id fringilla neque ante vel mi. Morbi mollis 
tellus ac sapien. Phasellus volutpat, metus eget egestas mollis, lacus lacus blandit dui, id egestas quam mauris ut lacus. Fusce vel dui. Sed in libero ut nibh placerat accumsan. 
Proin faucibus arcu quis ante. In consectetuer turpis ut velit. Nulla sit amet est. Praesent metus tellus, elementum eu, semper a, adipiscing nec, purus. Cras risus ipsum, faucibus 
ut, ullamcorper id, varius ac, leo. Suspendisse feugiat. Suspendisse enim turpis, dictum sed, iaculis a, condimentum nec, nisi. Praesent nec nisl a purus blandit viverra. Praesent 
ac massa at ligula laoreet iaculis. Nulla neque dolor, sagittis eget, iaculis quis, molestie non, velit. Mauris turpis nunc, blandit et, volutpat molestie, porta ut, ligula. Fusce 
pharetra convallis urna. Quisque ut nisi. Donec mi odio, faucibus at, scelerisque quis, convallis in, nisi. Suspendisse non nisl sit amet velit hendrerit rutrum. Ut leo. Ut a nisl 
id ante tempus hendrerit. Proin pretium, leo ac pellentesque mollis, felis nunc ultrices eros, sed gravida augue augue mollis justo. Suspendisse eu ligula. Nulla facilisi. Donec id 
justo. Praesent porttitor, nulla vitae posuere iaculis, arcu nisl dignissim dolor, a pretium mi sem ut ipsum. Curabitur suscipit suscipit tellus. Praesent vestibulum dapibus nibh. 
Etiam iaculis nunc ac metus. Ut id nisl quis enim dignissim sagittis. Etiam sollicitudin, ipsum eu pulvinar rutrum, tellus ipsum laoreet sapien, quis venenatis ante odio sit amet eros. 
Proin magna. Duis vel nibh at velit scelerisque suscipit. Curabitur turpis. Vestibulum suscipit nulla quis orci. Fusce ac felis sit amet ligula pharetra condimentum. Maecenas egestas 
arcu quis ligula mattis placerat. Duis lobortis massa imperdiet quam. Suspendisse potenti. Pellentesque commodo eros a enim. Vestibulum turpis sem, aliquet eget, lobortis pellentesque, 
rutrum eu, nisl. Sed libero. Aliquam erat volutpat. Etiam vitae tortor. Morbi vestibulum volutpat enim. Aliquam eu nunc. Nunc sed turpis. Sed mollis, eros et ultrices tempus, mauris 
ipsum aliquam libero, non adipiscing dolor urna a orci. Nulla porta dolor. Class aptent taciti sociosqu ad litora torquent per conubia nostra, per inceptos hymenaeos. Pellentesque 
dapibus hendrerit tortor. Praesent egestas tristique nibh. Sed a libero. Cras varius. Donec vitae orci sed dolor rutrum auctor. Fusce egestas elit eget lorem. Suspendisse nisl elit, 
rhoncus eget, elementum ac, condimentum eget, diam. Nam at tortor in tellus interdum sagittis. Aliquam lobortis. Donec orci lectus, aliquam ut, faucibus non, euismod id, nulla. 
Curabitur blandit mollis lacus. Nam adipiscing. Vestibulum eu odio. Vivamus laoreet. Nullam tincidunt adipiscing enim. Phasellus tempus. Proin viverra, ligula sit amet ultrices semper, 
ligula arcu tristique sapien, a accumsan nisi mauris ac eros. Fusce neque. Suspendisse faucibus, nunc et pellentesque egestas, lacus ante convallis tellus, vitae iaculis lacus elit 
id tortor. Vivamus aliquet elit ac nisl. Fusce fermentum odio nec arcu. Vivamus euismod mauris. In ut quam vitae odio lacinia tincidunt. Praesent ut ligula non mi varius sagittis. 
Cras sagittis. Praesent ac sem eget est egestas volutpat. Vivamus consectetuer hendrerit lacus. Cras non dolor. Vivamus in erat ut urna cursus vestibulum. Fusce commodo aliquam arcu. 
Nam commodo suscipit quam. Quisque id odio. Praesent venenatis metus at tortor pulvinar varius. Lorem ipsum dolor sit amet, consectetuer adipiscing elit. Aenean commodo ligula eget 
dolor. Aenean massa. Cum sociis natoque penatibus et magnis dis parturient montes, nascetur ridiculus mus. Donec quam felis, ultricies nec, pellentesque eu, pretium quis, sem. Nulla 
consequat massa quis enim. Donec pede justo, fringilla vel, aliquet nec, vulputate eget, arcu. In enim justo, rhoncus ut, imperdiet a, venenatis vitae, justo. Nullam dictum felis eu 
pede mollis pretium. Integer tincidunt. Cras dapibus. Vivamus elementum semper nisi. Aenean vulputate eleifend tellus. 
Aenean leo ligula, porttitor eu, consequat vitae, eleifend ac, enim. Aliquam lorem ante, dapibus in, viverra quis, feugiat a, tellus. 
Phasellus viverra nulla ut metus varius laoreet. Quisque rutrum. Aenean imperdiet. Etiam ultricies nisi vel augue. Curabitur ullamcorper 
ultricies nisi. Nam eget dui. Etiam rhoncus. Maecenas tempus, tellus eget condimentum rhoncus, sem quam semper libero, sit amet adipiscing 
sem neque sed ipsum. Nam quam nunc, blandit vel, luctus pulvinar, hendrerit id, lorem. Maecenas nec odio et ante tincidunt tempus. Donec vitae 
sapien ut libero venenatis faucibus. Nullam quis ante. Etiam sit amet orci eget eros faucibus tincidunt. Duis leo. Sed fringilla mauris sit amet nibh. 
Donec sodales sagittis magna. Sed consequat, leo eget bibendum sodales, augue velit cursus nunc, quis gravida magna mi a libero. Fusce vulputate eleifend sapien. 
Vestibulum purus quam, scelerisque ut, mollis sed, nonummy id, metus. Nullam accumsan lorem in dui. Cras ultricies mi eu turpis hendrerit fringilla. Vestibulum ante 
ipsum primis in faucibus orci luctus et ultrices posuere cubilia Curae; In ac dui quis mi consectetuer lacinia. Nam pretium turpis et arcu. Duis arcu tortor, suscipit eget, 
imperdiet nec, imperdiet iaculis, ipsum. Sed aliquam ultrices mauris. Integer ante arcu, accumsan a, consectetuer eget, posuere ut, mauris. Praesent adipiscing. Phasellus 
ullamcorper ipsum rutrum nunc. Nunc nonummy metus. Vestibulum volutpat pretium libero. Cras id dui. Aenean ut eros et nisl sagittis vestibulum. Nullam nulla eros, ultricies 
sit amet, nonummy id, imperdiet feugiat, pede. Sed lectus. Donec mollis hendrerit risus. Phasellus nec sem in justo pellentesque facilisis. Etiam imperdiet imperdiet orci. Nunc 
nec neque. Phasellus leo dolor, tempus non, auctor et, hendrerit quis, nisi. Curabitur ligula sapien, tincidunt non, euismod vitae, posuere imperdiet, leo. Maecenas malesuada. 
Praesent congue erat at massa. Sed cursus turpis vitae tortor. Donec posuere vulputate arcu. Phasellus accumsan cursus velit. Vestibulum ante ipsum primis in faucibus orci 
luctus et ultrices posuere cubilia Curae; Sed aliquam, nisi quis porttitor congue, elit erat euismod orci, ac placerat dolor lectus quis orci. Phasellus consectetuer vestibulum 
elit. Aenean tellus metus, bibendum sed, posuere ac, mattis non, nunc. Vestibulum fringilla pede sit amet augue. In turpis. Pellentesque posuere. Praesent turpis. Aenean posuere, 
tortor sed cursus feugiat, nunc augue blandit nunc, eu sollicitudin urna dolor sagittis lacus. Donec elit libero, sodales nec, volutpat a, suscipit non, turpis. Nullam sagittis. 
Suspendisse pulvinar, augue ac venenatis condimentum, sem libero volutpat nibh, nec pellentesque velit pede quis nunc. Vestibulum ante ipsum primis in faucibus orci luctus et ultrices 
posuere cubilia Curae; Fusce id purus. Ut varius tincidunt libero. Phasellus dolor. Maecenas vestibulum mollis diam. Pellentesque ut neque. Pellentesque habitant morbi tristique 
senectus et netus et malesuada fames ac turpis egestas. In dui magna, posuere eget, vestibulum et, tempor auctor, justo. In ac felis quis tortor malesuada pretium. Pellentesque auctor 
neque nec urna. Proin sapien ipsum, porta a, auctor quis, euismod ut, mi. Aenean viverra rhoncus pede. Pellentesque habitant morbi tristique senectus et netus et malesuada fames ac 
turpis egestas. Ut non enim eleifend felis pretium feugiat. Vivamus quis mi. Phasellus a est. Phasellus magna. In hac habitasse platea dictumst. Curabitur at lacus ac velit ornare 
lobortis. Curabitur a felis in nunc fringilla tristique. Morbi mattis ullamcorper velit. Phasellus gravida semper nisi. Nullam vel sem. Pellentesque libero tortor, tincidunt et, 
tincidunt eget, semper nec, quam. Sed hendrerit. Morbi ac felis. Nunc egestas, augue at pellentesque laoreet, felis eros vehicula leo, at malesuada velit leo quis pede. Donec 
interdum, metus et hendrerit aliquet, dolor diam sagittis ligula, eget egestas libero turpis vel mi. Nunc nulla. Fusce risus nisl, viverra et, tempor et, pretium in, sapien. Donec 
venenatis vulputate lorem. Morbi nec metus. Phasellus blandit leo ut odio. Maecenas ullamcorper, dui et placerat feugiat, eros pede varius nisi, condimentum viverra felis nunc et 
lorem. Sed magna purus, fermentum eu, tincidunt eu, varius ut, felis. In auctor lobortis lacus. Quisque libero metus, condimentum nec, tempor a, commodo mollis, magna. Vestibulum 
ullamcorper mauris at ligula. Fusce fermentum. Nullam cursus lacinia erat. Praesent blandit laoreet nibh. Fusce convallis metus id felis luctus adipiscing. Pellentesque egestas, neque 
sit amet convallis pulvinar, justo nulla eleifend augue, ac auctor orci leo non est. Quisque id mi. Ut tincidunt tincidunt erat. Etiam feugiat lorem non metus. Vestibulum dapibus nunc 
ac augue. Curabitur vestibulum aliquam leo. Praesent egestas neque eu enim. In hac habitasse platea dictumst. Fusce a quam. Etiam ut purus mattis mauris sodales aliquam. Curabitur nisi. 
Quisque malesuada placerat nisl. Nam ipsum risus, rutrum vitae, vestibulum eu, molestie vel, lacus. Sed augue ipsum, egestas nec, vestibulum et, malesuada adipiscing, dui. Vestibulum 
facilisis, purus nec pulvinar iaculis, ligula mi congue nunc, vitae euismod ligula urna in dolor. Mauris sollicitudin fermentum libero. Praesent nonummy mi in odio. Nunc interdum lacus 
sit amet orci. Vestibulum rutrum, mi nec elementum vehicula, eros quam gravida nisl, id fringilla neque ante vel mi. Morbi mollis tellus ac sapien. Phasellus volutpat, metus eget 
egestas mollis, lacus lacus blandit dui, id egestas quam mauris ut lacus. Fusce vel dui. Sed in libero ut nibh placerat accumsan. Proin faucibus arcu quis ante. In consectetuer turpis 
ut velit. Nulla sit amet est. Praesent metus tellus, elementum eu, semper a, adipiscing nec, purus. Cras risus ipsum, faucibus ut, ullamcorper id, varius ac, leo. Suspendisse feugiat. 
Suspendisse enim turpis, dictum sed, iaculis a, condimentum nec, nisi. Praesent nec nisl a purus blandit viverra. Praesent ac massa at ligula laoreet iaculis. Nulla neque dolor, 
sagittis eget, iaculis quis, molestie non, velit. Mauris turpis nunc, blandit et, volutpat molestie, porta ut, ligula. Fusce pharetra convallis urna. Quisque ut nisi. Donec mi odio, 
faucibus at, scelerisque quis, convallis in, nisi. Suspendisse non nisl sit amet velit hendrerit rutrum. Ut leo. Ut a nisl id ante tempus hendrerit. Proin pretium, leo ac pellentesque 
mollis, felis nunc ultrices eros, sed gravida augue augue mollis justo. Suspendisse eu ligula. Nulla facilisi. Donec id justo. Praesent porttitor, nulla vitae posuere iaculis, arcu 
nisl dignissim dolor, a pretium mi sem ut ipsum. Curabitur suscipit suscipit tellus. Praesent vestibulum dapibus nibh. Etiam iaculis nunc ac metus. Ut id nisl quis enim dignissim 
sagittis. Etiam sollicitudin, ipsum eu pulvinar rutrum, tellus ipsum laoreet sapien, quis venenatis ante odio sit amet eros. Proin magna. Duis vel nibh at velit scelerisque suscipit. 
Curabitur turpis. Vestibulum suscipit nulla quis orci. Fusce ac felis sit amet ligula pharetra condimentum. Maecenas egestas arcu quis ligula mattis placerat. Duis lobortis massa 
imperdiet quam. Suspendisse potenti. Pellentesque commodo eros a enim. Vestibulum turpis sem, aliquet eget, lobortis pellentesque, rutrum eu, nisl. Sed libero. Aliquam erat volutpat. 
Etiam vitae tortor. Morbi vestibulum volutpat enim. Aliquam eu nunc. Nunc sed turpis. Sed mollis, eros et ultrices tempus, mauris ipsum aliquam libero, non adipiscing dolor urna a orci. 
Nulla porta dolor. Class aptent taciti sociosqu ad litora torquent per conubia nostra, per inceptos hymenaeos. Pellentesque dapibus hendrerit tortor. Praesent egestas tristique nibh. 
Sed a libero. Cras varius. Donec vitae orci sed dolor rutrum auctor. Fusce egestas elit eget lorem. Suspendisse nisl elit, rhoncus eget, elementum ac, condimentum eget, diam. Nam at 
tortor in tellus interdum sagittis. Aliquam lobortis. Donec orci lectus, aliquam ut, faucibus non, euismod id, nulla. Curabitur blandit mollis lacus. Nam adipiscing. Vestibulum eu odio. 
Vivamus laoreet. Nullam tincidunt adipiscing enim. Phasellus tempus. Proin viverra, ligula sit amet ultrices semper, ligula arcu tristique sapien, a accumsan nisi mauris ac eros. 
Fusce neque. Suspendisse faucibus, nunc et pellentesque egestas, lacus ante convallis tellus, vitae iaculis lacus elit id tortor. Vivamus aliquet elit ac nisl. Fusce fermentum odio 
nec arcu. Vivamus euismod mauris. In ut quam vitae odio lacinia tincidunt. Praesent ut ligula non mi varius sagittis. Cras sagittis. Praesent ac sem eget est egestas volutpat. Vivamus 
consectetuer hendrerit lacus. Cras non dolor. Vivamus in erat ut urna cursus vestibulum. Fusce commodo aliquam arcu. Nam commodo suscipit quam. Quisque id odio. Praesent venenatis metus 
at tortor pulvinar varius. Lorem ipsum dolor sit amet, consectetuer adipiscing elit. Aenean commodo ligula eget dolor. Aenean massa. Cum sociis natoque penatibus et magnis dis 
parturient montes, nascetur ridiculus mus. Donec quam felis, ultricies nec, pellentesque eu, pretium quis, sem. Nulla consequat massa quis enim. Donec pede justo, fringilla vel, 
aliquet nec, vulputate eget, arcu. In enim justo, rhoncus ut, imperdiet a, venenatis vitae, justo. Nullam dictum felis eu pede mollis pretium. Integer tincidunt. Cras dapibus. Vivamus 
elementum semper nisi. Aenean vulputate eleifend tellus. Aenean leo ligula, porttitor eu, consequat vitae, eleifend ac, enim. Aliquam lorem ante, dapibus in, viverra quis, feugiat a, 
tellus. Phasellus viverra nulla ut metus varius laoreet. Quisque rutrum. Aenean imperdiet. Etiam ultricies nisi vel augue. Curabitur ullamcorper ultricies nisi. Nam eget dui. 
Etiam rhoncus. Maecenas tempus, tellus eget condimentum rhoncus, sem quam semper libero, sit amet adipiscing sem neque sed ipsum. Nam quam nunc, blandit vel, luctus pulvinar, 
hendrerit id, lorem. Maecenas nec odio et ante tincidunt tempus. Donec vitae sapien ut libero venenatis faucibus. Nullam quis ante. Etiam sit amet orci eget eros faucibus tincidunt. 
Duis

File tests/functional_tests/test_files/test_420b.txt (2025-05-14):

ABCDEFGHIJKLMNOPQRSTUVWXYZabcdefghijklmnopqrstuvwxyz0123456789ABCDEFGHIJKLMNOPQRSTUVWXYZabcdefghijklmnopqrstuvwxyz0123456789ABCDEFGHIJKLMNOPQRSTUVWXYZabcdefghijklmnopqrstuvwxyz0123456789ABCDEFGHIJKLMNOPQRSTUVWXYZabcdefghijklmnopqrstuvwxyz0123456789ABCDEFGHIJKLMNOPQRSTUVWXYZabcdefghijklmnopqrstuvwxyz0123456789ABCDEFGHIJKLMNOPQRSTUVWXYZabcdefghijklmnopqrstuvwxyz0123456789ABCDEFGHIJKLMNOPQRSTUVWXYZabcdefghijklmnopqrstuvwxyz0123456789ABCDEFGHIJKLMNOPQRSTUVWXYZabcdefghijklmnopqrstuvwxyz0123456789

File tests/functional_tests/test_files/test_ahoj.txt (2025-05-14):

ahoj
ahoj
ahoj
ahoj
ahoj
ahoj
ahoj
ahoj
ahoj
ahoj
ahoj
ahoj
ahoj
ahoj
ahoj
ahoj
ahoj
ahoj
ahoj
ahoj
ahoj
ahoj
ahoj
ahoj
ahoj
ahoj
ahoj
ahoj
ahoj
ahoj
ahoj
ahoj

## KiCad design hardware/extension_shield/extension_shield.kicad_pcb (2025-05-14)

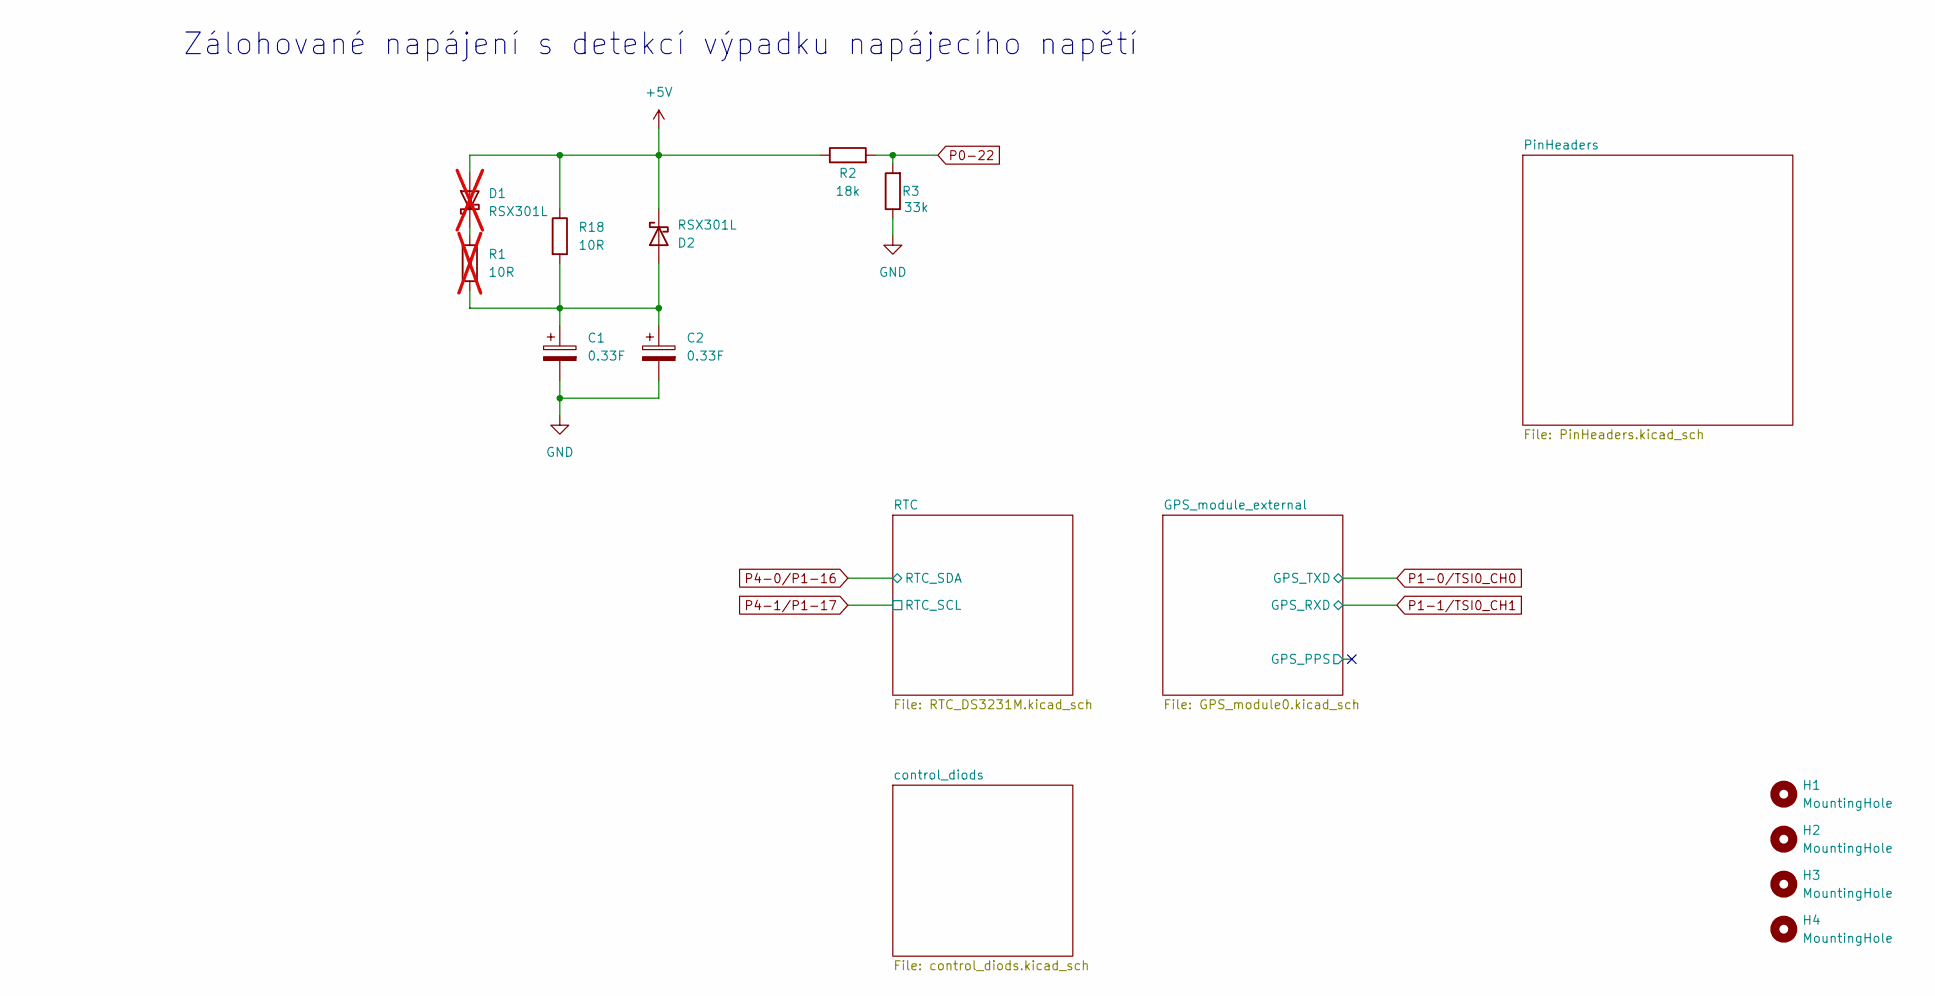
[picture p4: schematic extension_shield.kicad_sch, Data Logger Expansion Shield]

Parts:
C1, C2: 0.33F; C_Radial_D8mm_W24mm_L14mm_P13.5mm
D1: RSX301L; D_SMA; not fitted
D2: RSX301L; D_SMA
H1, H2, H3, H4: MountingHole; MountingHole_3.2mm_M3
R1: 10R; R_Axial_DIN0204_L3.6mm_D1.6mm_P5.08mm_Horizontal; not fitted
R2: 18k; R_1206_3216Metric_Pad1.30x1.75mm_HandSolder
R3: 33k; R_1206_3216Metric_Pad1.30x1.75mm_HandSolder
R18: 10R; R_Axial_DIN0204_L3.6mm_D1.6mm_P5.08mm_Horizontal

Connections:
+5V: D1.2 (A), D2.1 (K), R2.1, R18.1; also elsewhere on the board
GND: C1.2, C2.2, R3.1; also elsewhere on the board
unnamed: D1.1 (K), R1.1
unnamed: C1.1, C2.1, D2.2 (A), R1.2, R18.2
P0-22: R2.2, R3.2; also elsewhere on the board

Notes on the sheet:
Zálohované napájení s detekcí výpadku napájecího napětí

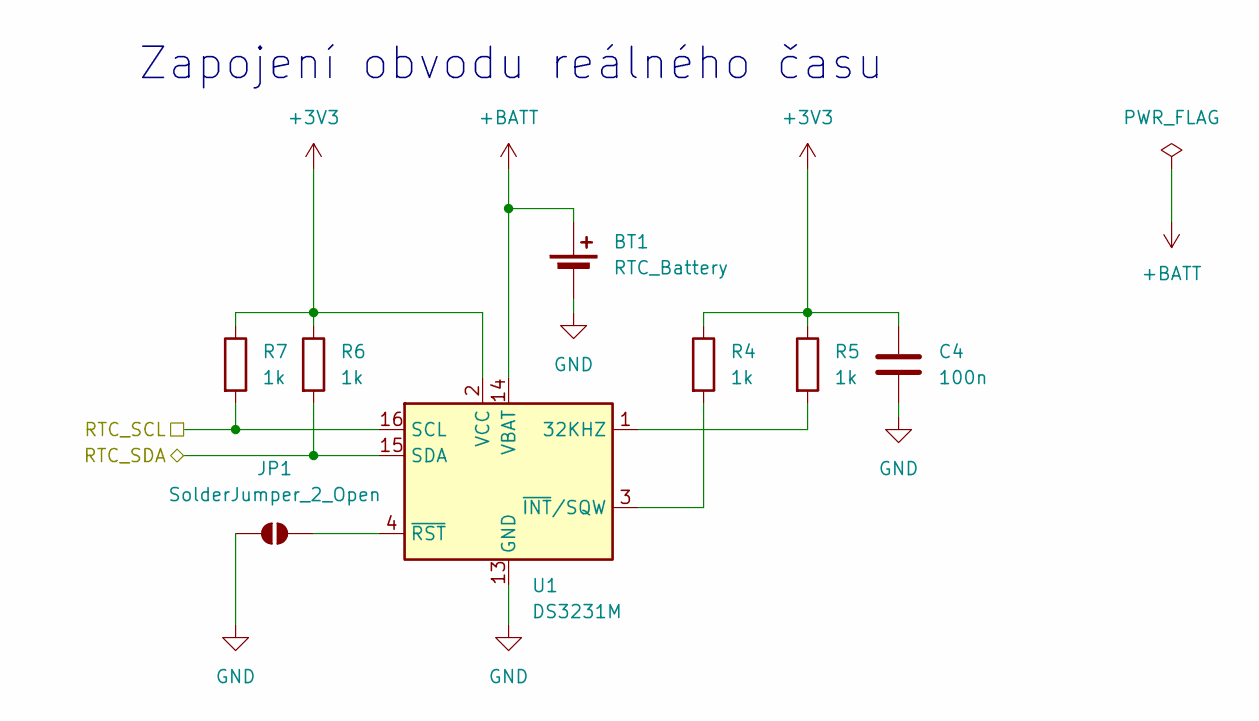
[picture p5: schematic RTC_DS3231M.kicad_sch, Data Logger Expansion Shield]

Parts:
BT1: RTC_Battery; Battery_Panasonic_CR2032-HFN_Horizontal_CircularHoles
C4: 100n; C_1206_3216Metric_Pad1.33x1.80mm_HandSolder
JP1: SolderJumper_2_Open; SolderJumper-2_P1.3mm_Open_Pad1.0x1.5mm
R4, R5, R6, R7: 1k; R_1206_3216Metric_Pad1.30x1.75mm_HandSolder
U1: DS3231M; SOIC-16W_7.5x10.3mm_P1.27mm

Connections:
+3V3: C4.1, R4.1, R5.1, R6.1, R7.1, U1.2 (VCC); also elsewhere on the board
+BATT: BT1.1 (+), U1.14 (VBAT)
GND: BT1.2 (-), C4.2, JP1.1 (A), U1.5 (GND), U1.6 (GND), U1.7 (GND), U1.8 (GND), U1.9 (GND), U1.10 (GND), U1.11 (GND), U1.12 (GND), U1.13 (GND); also elsewhere on the board
unnamed: JP1.2 (B), U1.4 (~RST)
unnamed: R5.2, U1.1 (32KHZ)
unnamed: R4.2, U1.3 (~INT/SQW)
P4-0/P1-16: R6.2, U1.15 (SDA); also elsewhere on the board
P4-1/P1-17: R7.2, U1.16 (SCL); also elsewhere on the board

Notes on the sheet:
Zapojení obvodu reálného času

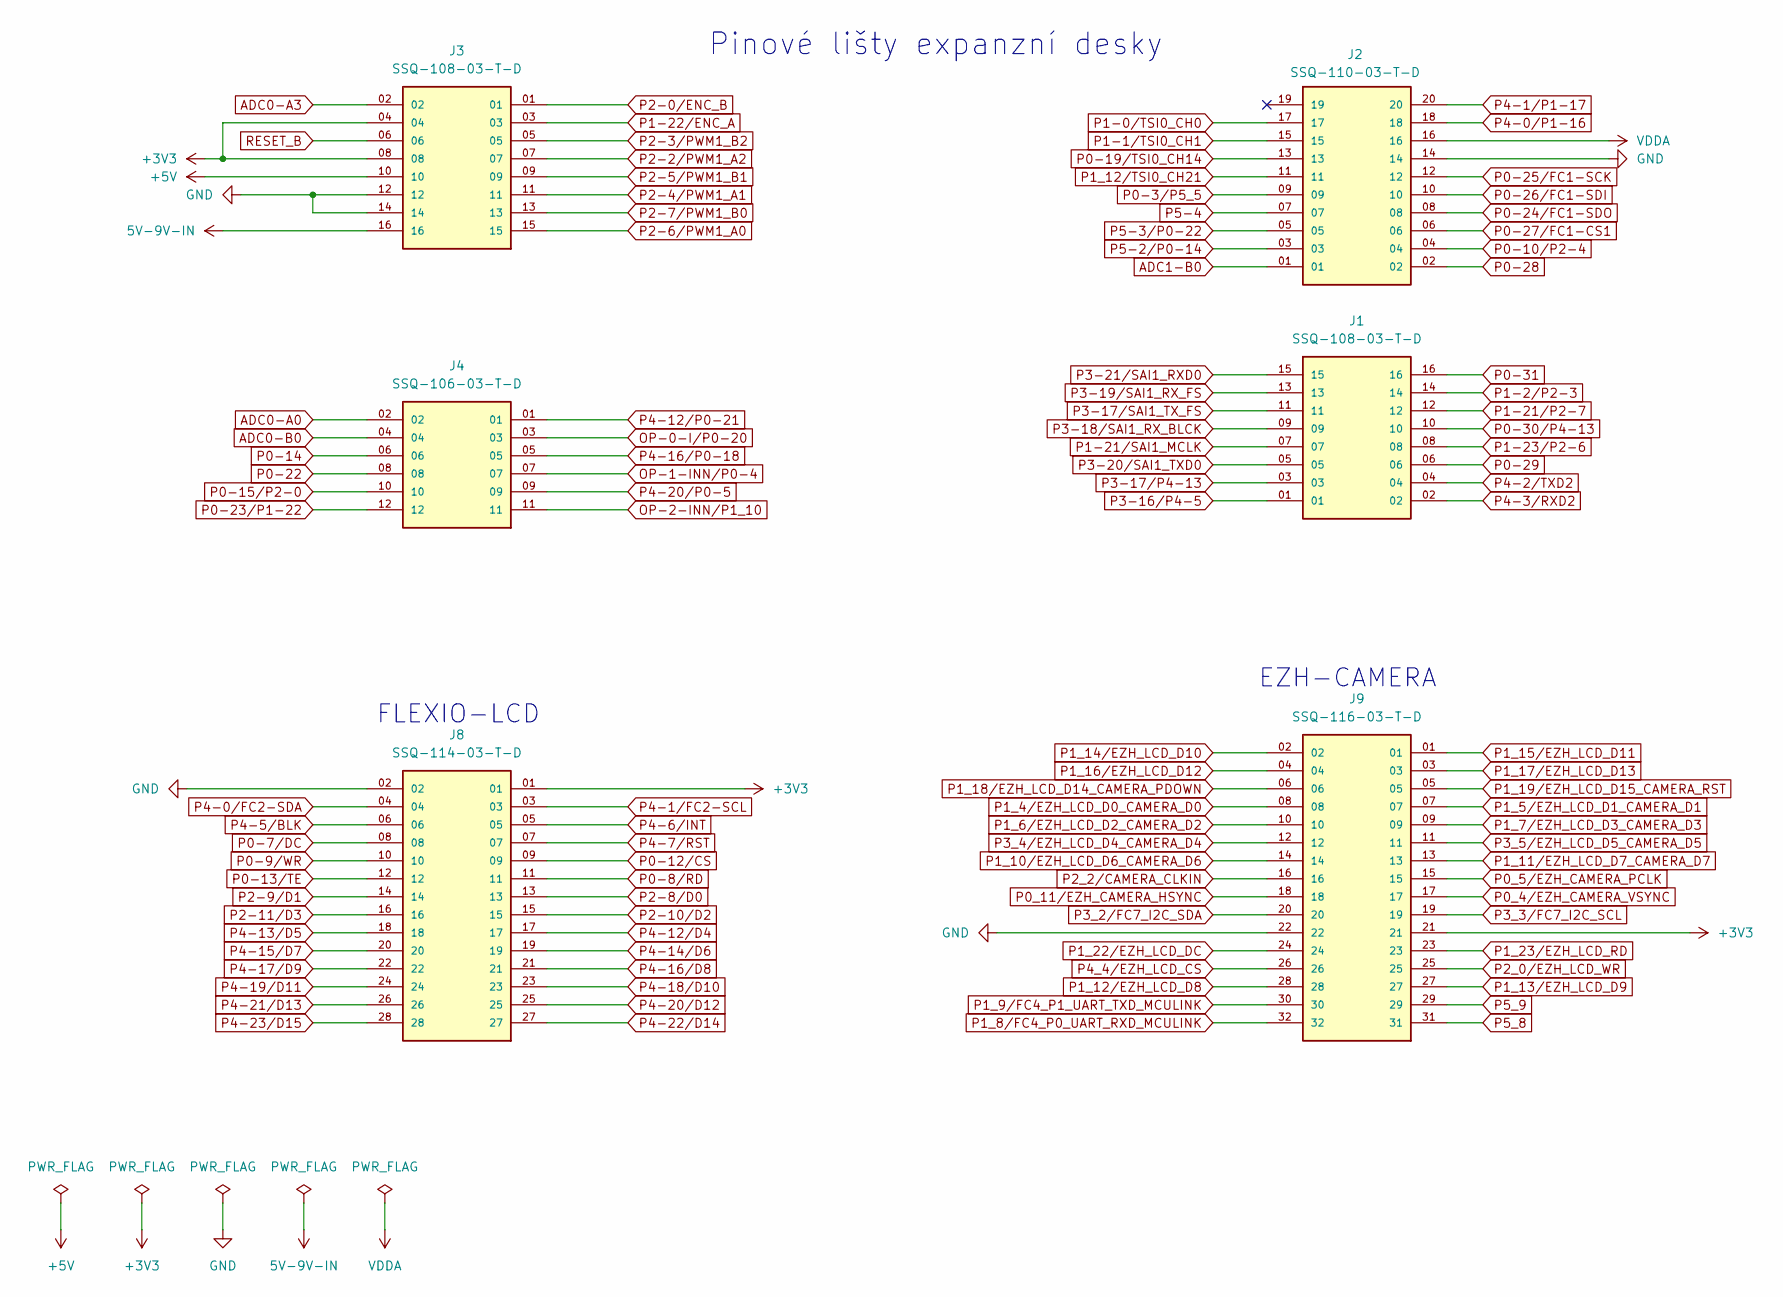
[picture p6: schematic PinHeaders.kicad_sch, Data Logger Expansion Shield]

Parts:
J1, J3: SSQ-108-03-T-D; SAMTEC_SSQ-108-XX-X-D; PARTREV A
J2: SSQ-110-03-T-D; SAMTEC_SSQ-110-03-T-D; PARTREV R
J4: SSQ-106-03-T-D; SAMTEC_SSQ-106-03-T-D; PARTREV R
J8: SSQ-114-03-T-D; SAMTEC_SSQ-114-03-T-D; PARTREV R
J9: SSQ-116-03-T-D; SAMTEC_SSQ-116-XX-X-D; PARTREV A

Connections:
5V-9V-IN: J3.16
+3V3: J3.04, J3.08, J8.01, J9.21; also elsewhere on the board
+5V: J3.10; also elsewhere on the board
ADC0-A0: J4.02
ADC0-A3: J3.02
ADC0-B0: J4.04
ADC1-B0: J2.01
GND: J2.14, J3.12, J3.14, J8.02, J9.22; also elsewhere on the board
OP-0-I/P0-20: J4.03
OP-1-INN/P0-4: J4.07
OP-2-INN/P1_10: J4.11
P0-3/P5_5: J2.09
P0-7/DC: J8.08; also elsewhere on the board
P0-8/RD: J8.11
P0-9/WR: J8.10; also elsewhere on the board
P0-10/P2-4: J2.04
P0-12/CS: J8.09
P0-13/TE: J8.12; also elsewhere on the board
P0-14: J4.06
P0-15/P2-0: J4.10
P0-19/TSI0_CH14: J2.13
P0-22: J4.08; also elsewhere on the board
P0-23/P1-22: J4.12
P0-24/FC1-SDO: J2.08
P0-25/FC1-SCK: J2.12
P0-26/FC1-SDI: J2.10
P0-27/FC1-CS1: J2.06
P0-28: J2.02
P0-29: J1.06
P0-30/P4-13: J1.10
P0-31: J1.16
P0_4/EZH_CAMERA_VSYNC: J9.17
P0_5/EZH_CAMERA_PCLK: J9.15
P0_11/EZH_CAMERA_HSYNC: J9.18
P1-0/TSI0_CH0: J2.17; also elsewhere on the board
P1-1/TSI0_CH1: J2.15; also elsewhere on the board
P1-2/P2-3: J1.14
P1-21/P2-7: J1.12
P1-21/SAI1_MCLK: J1.07
P1-22/ENC_A: J3.03
P1-23/P2-6: J1.08
P1_4/EZH_LCD_D0_CAMERA_D0: J9.08
P1_5/EZH_LCD_D1_CAMERA_D1: J9.07
P1_6/EZH_LCD_D2_CAMERA_D2: J9.10
P1_7/EZH_LCD_D3_CAMERA_D3: J9.09
P1_8/FC4_P0_UART_RXD_MCULINK: J9.32
P1_9/FC4_P1_UART_TXD_MCULINK: J9.30
P1_10/EZH_LCD_D6_CAMERA_D6: J9.14
P1_11/EZH_LCD_D7_CAMERA_D7: J9.13
P1_12/EZH_LCD_D8: J9.28
P1_12/TSI0_CH21: J2.11
P1_13/EZH_LCD_D9: J9.27
P1_14/EZH_LCD_D10: J9.02
P1_15/EZH_LCD_D11: J9.01
P1_16/EZH_LCD_D12: J9.04
P1_17/EZH_LCD_D13: J9.03
P1_18/EZH_LCD_D14_CAMERA_PDOWN: J9.06
P1_19/EZH_LCD_D15_CAMERA_RST: J9.05
P1_22/EZH_LCD_DC: J9.24
P1_23/EZH_LCD_RD: J9.23
P2-0/ENC_B: J3.01
P2-2/PWM1_A2: J3.07
P2-3/PWM1_B2: J3.05
P2-4/PWM1_A1: J3.11
P2-5/PWM1_B1: J3.09
P2-6/PWM1_A0: J3.15
P2-7/PWM1_B0: J3.13
P2-8/D0: J8.13
P2-9/D1: J8.14
P2-10/D2: J8.15
P2-11/D3: J8.16; also elsewhere on the board
P2_0/EZH_LCD_WR: J9.25
P2_2/CAMERA_CLKIN: J9.16
P3-16/P4-5: J1.01
P3-17/P4-13: J1.03
P3-17/SAI1_TX_FS: J1.11
P3-18/SAI1_RX_BLCK: J1.09
P3-19/SAI1_RX_FS: J1.13
P3-20/SAI1_TXD0: J1.05
P3-21/SAI1_RXD0: J1.15
P3_2/FC7_I2C_SDA: J9.20
P3_3/FC7_I2C_SCL: J9.19
P3_4/EZH_LCD_D4_CAMERA_D4: J9.12
P3_5/EZH_LCD_D5_CAMERA_D5: J9.11
P4-0/FC2-SDA: J8.04
P4-0/P1-16: J2.18; also elsewhere on the board
P4-1/FC2-SCL: J8.03
P4-1/P1-17: J2.20; also elsewhere on the board
P4-2/TXD2: J1.04
P4-3/RXD2: J1.02
P4-5/BLK: J8.06
P4-6/INT: J8.05
P4-7/RST: J8.07
P4-12/D4: J8.17
P4-12/P0-21: J4.01
P4-13/D5: J8.18
P4-14/D6: J8.19
P4-15/D7: J8.20
P4-16/D8: J8.21
P4-16/P0-18: J4.05
P4-17/D9: J8.22; also elsewhere on the board
P4-18/D10: J8.23
P4-19/D11: J8.24
P4-20/D12: J8.25
P4-20/P0-5: J4.09
P4-21/D13: J8.26
P4-22/D14: J8.27
P4-23/D15: J8.28
P4_4/EZH_LCD_CS: J9.26
P5-2/P0-14: J2.03
P5-3/P0-22: J2.05
P5-4: J2.07
P5_8: J9.31
P5_9: J9.29
RESET_B: J3.06
VDDA: J2.16

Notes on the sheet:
FLEXIO-LCD
Pinové lišty expanzní desky
EZH-CAMERA

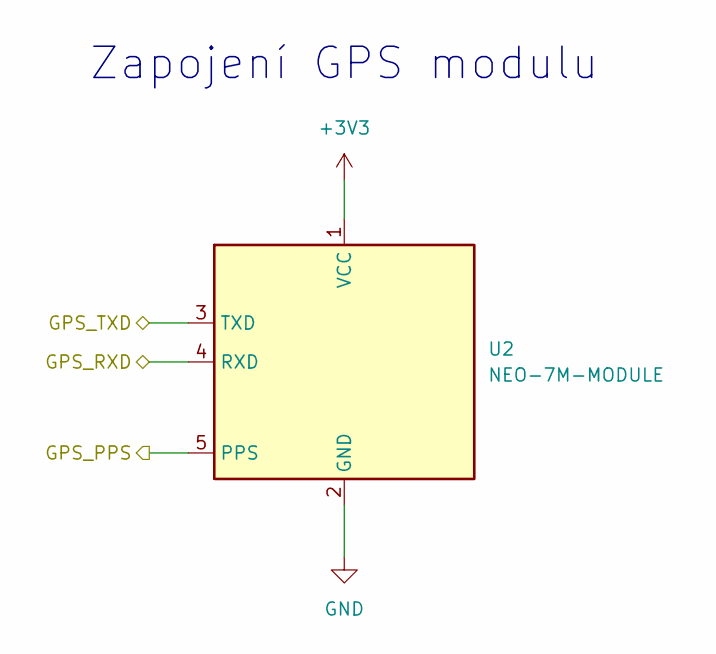
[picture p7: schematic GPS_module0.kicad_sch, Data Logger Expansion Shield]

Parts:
U2: NEO-7M-MODULE; Neo-7M-Module

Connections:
+3V3: U2.1 (VCC); also elsewhere on the board
/GPS_module_external/GPS_PPS: U2.5 (PPS)
GND: U2.2 (GND); also elsewhere on the board
P1-0/TSI0_CH0: U2.3 (TXD); also elsewhere on the board
P1-1/TSI0_CH1: U2.4 (RXD); also elsewhere on the board

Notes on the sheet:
Zapojení GPS modulu

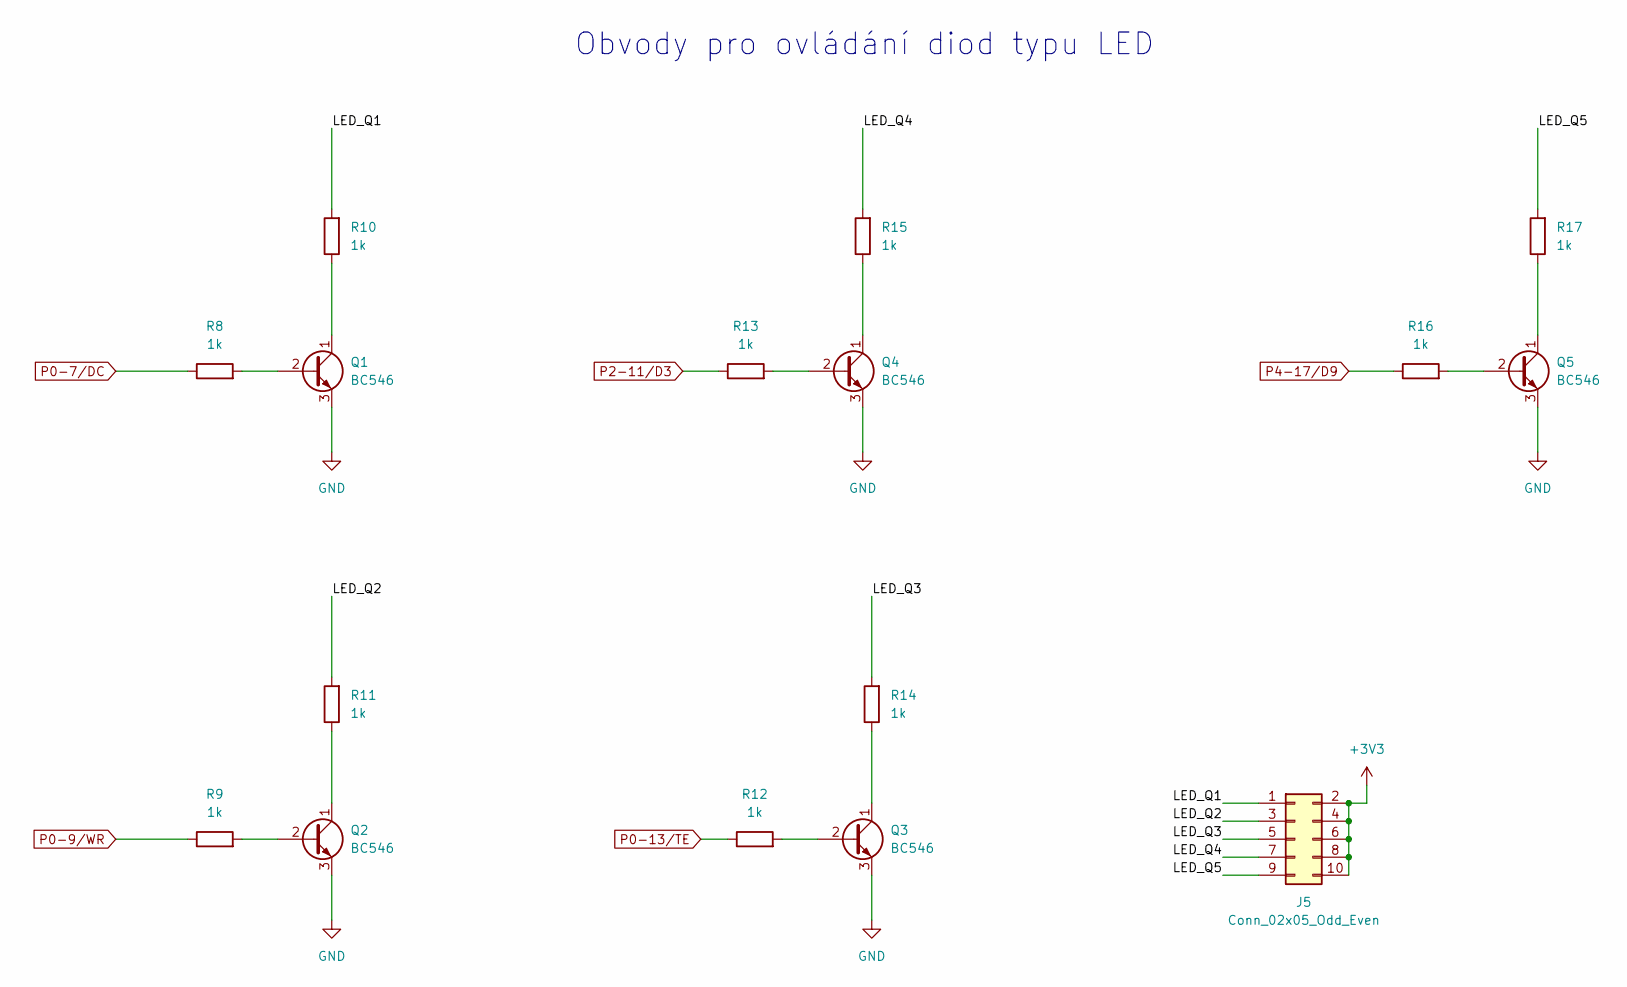
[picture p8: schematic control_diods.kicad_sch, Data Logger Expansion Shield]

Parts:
J5: Conn_02x05_Odd_Even; PinSocket_2x05_P2.54mm_Vertical
Q1, Q2, Q3, Q4, Q5: BC546; TO-92_Inline
R8, R9, R10, R11, R12, R13, R14, R15, R16, R17: 1k; R_1206_3216Metric_Pad1.30x1.75mm_HandSolder

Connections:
+3V3: J5.2, J5.4, J5.6, J5.8, J5.10; also elsewhere on the board
/control_diods/LED_Q1: J5.1, R10.2
/control_diods/LED_Q2: J5.3, R11.2
/control_diods/LED_Q3: J5.5, R14.2
/control_diods/LED_Q4: J5.7, R15.2
/control_diods/LED_Q5: J5.9, R17.2
GND: Q1.3 (E), Q2.3 (E), Q3.3 (E), Q4.3 (E), Q5.3 (E); also elsewhere on the board
unnamed: Q1.2 (B), R8.2
unnamed: Q1.1 (C), R10.1
unnamed: Q2.2 (B), R9.2
unnamed: Q2.1 (C), R11.1
unnamed: Q3.2 (B), R12.2
unnamed: Q3.1 (C), R14.1
unnamed: Q4.2 (B), R13.2
unnamed: Q4.1 (C), R15.1
unnamed: Q5.2 (B), R16.2
unnamed: Q5.1 (C), R17.1
P0-7/DC: R8.1; also elsewhere on the board
P0-9/WR: R9.1; also elsewhere on the board
P0-13/TE: R12.1; also elsewhere on the board
P2-11/D3: R13.1; also elsewhere on the board
P4-17/D9: R16.1; also elsewhere on the board

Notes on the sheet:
Obvody pro ovládání diod typu LED

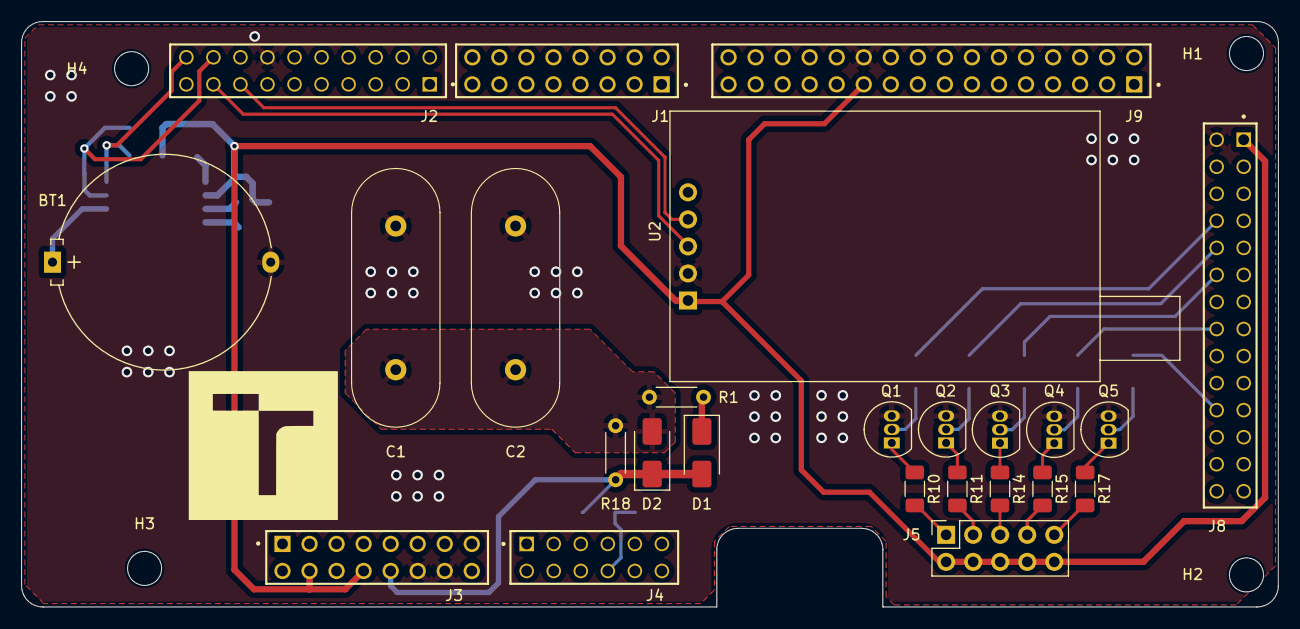
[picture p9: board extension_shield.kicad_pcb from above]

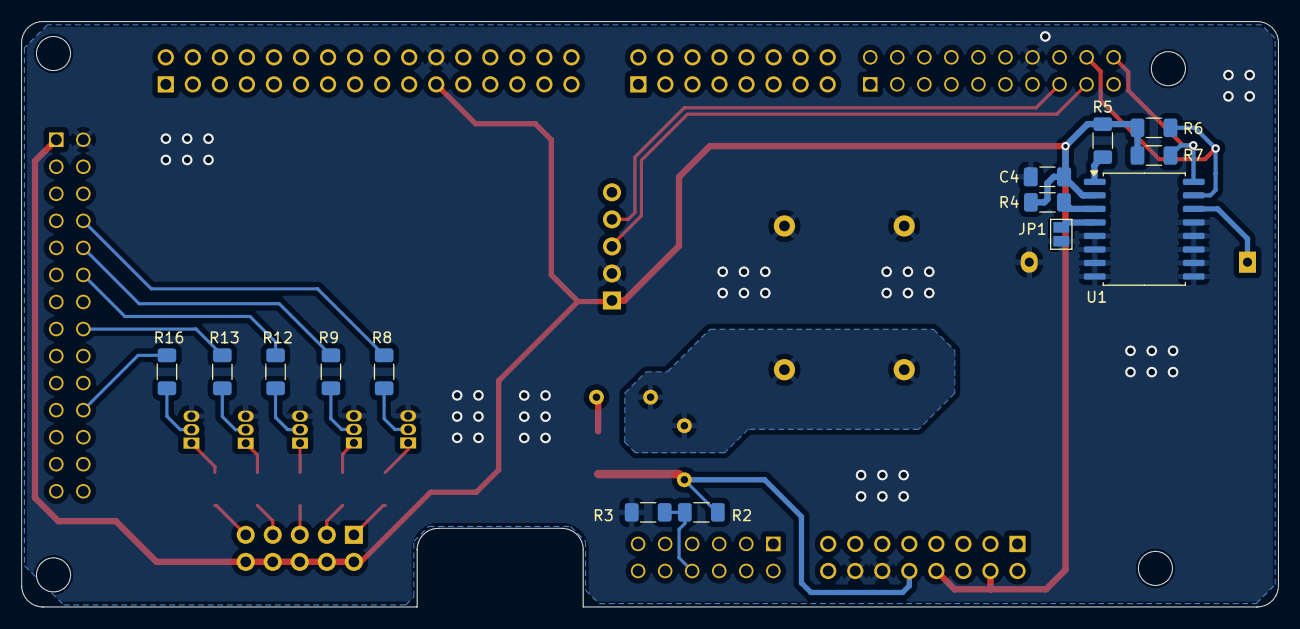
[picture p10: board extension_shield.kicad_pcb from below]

Board: 2 copper layers, 118.1 x 55.0 mm, 43 parts (14 on the bottom side), 34 nets.

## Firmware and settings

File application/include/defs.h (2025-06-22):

/******************************
 *  Project:        NXP MCXN947 Datalogger
 *  File Name:      defs.h
 *  Author:         Tomas Dolak
 *  Date:           22.09.2024
 *  Description:    Header File Providing Definitions To Set Up The Project.
 *
 * ****************************/

/******************************
 *  @package        NXP MCXN947 Datalogger
 *  @file           defs.h
 *  @author         Tomas Dolak
 *  @date           22.09.2024
 *  @brief          Header File Providing Definitions To Set Up The Project.
 * ****************************/

#ifndef DEFS_H_
#define DEFS_H_

/*******************************************************************************
 * Includes
 ******************************************************************************/
#include <stdbool.h>


/*******************************************************************************
 * Definitions
 ******************************************************************************/
#define NOT_IMPLEMENTED				#error "This Feature Is Not Implemented!"

/**
 * @brief 	Defines The Stack Size For Mass Storage Task.
 */
#define MSC_STACK_SIZE        ((uint32_t)(5000UL / (uint32_t)sizeof(portSTACK_TYPE)))

/**
 * @brief 	Defines The Stack Size For Recording Task.
 */
#define RECORD_STACK_SIZE     ((uint32_t)(5000UL / (uint32_t)sizeof(portSTACK_TYPE)))

/**
 * @brief Enables/Disables Mass Storage Functionality.
 * */
#define MSC_ENABLED					(true)

/**
 * @brief 	Enables/Disables Debug Mode
 * @details If Info Mode Is Enabled Then Basic Logs (Init. Progress, Configuration File Loading,...)
 * 			Are Printed Into Debug Console.
 */
#define INFO_ENABLED				(false)

/**
 * @brief 	Enables/Disables Debug Mode
 * @details If Debug Mode Is Enabled Then More Logs Are Printed Into Debug Console.
 */
#define DEBUG_ENABLED				(false)

/**
 * @brief Enables/Disables HW FIFO Queue on Application LPUART.
 */
#define UART_FIFO_ENABLED			(true)

/**
 * @brief Defines The Size of HW FIFO Queue.
 */
#define UART_FIFO_LENGHT			(4u)

/**
 * @brief Enables/Disables Print of Received Bytes From Application LPUART To Console.
 */
#define UART_PRINT_ENABLED			(false)

/**
 * @brief Enables/Disables Power Loss Detection.
 */
#define PWRLOSS_DETECTION_ENABLED	(true)

/**
 * @brief Enables/Disables GPIO For Testing Power Loss Detection.
 */
#define PWRLOSS_TEST_GPIOS			(false)

/**
 * @brief 	Constant 5 Tau, When Back-Up Power Capacitor is Charged To 99%.
 * @details In Seconds.
 */
#define TAU5						16.5

/**
 * @brief 	Time Interval When Power Loss Detection Became Active.
 * @details	In Seconds.
 */
#define PWRLOSS_DET_ACTIVE_IN_TIME	TAU5

/**
 * @brief Priority of LP_FLEXCOMM Interrupt (UART) For Rx Of Recorded Data.
 */
#define UART_RECEIVE_PRIO			(6U)

/**
 * @brief Priority of Comparator Interrupt For Power Loss Detection.
 */
#define PWRLOSS_DET_PRIO			(5U)

/**
 * @brief Priority of Comparator Interrupt For Power Loss Detection.
 */
#define PWRLOSS_TIMER_PRIO			(7U)

/**
 * @brief Enables/Disables Temperature Recording.
 */
#define TEMPERATURE_MEAS_ENABLED	(false)

/**
 * @brief Enables/Disables Signaling By LEDs.
 */
#define CONTROL_LED_ENABLED			(true)

/**
 * @brief	Default Maximal File Size If The Configuration File Could
 * 			Not Be Read Properly.
 */
#define DEFAULT_MAX_FILESIZE		8192

/**
 * @brief Configuration File.
 */
#define CONFIG_FILE 				"config"

/**
 * @brief 	Default Baud Rate If The Configuration File Could Not Be
 * 			Read Properly.
 */
#define DEFAULT_BAUDRATE			230400UL

/**
 * @brief	Default Number of Data Bits If The Configuration File Could
 * 			Not Be Read Properly.
 */
#define DEFAULT_DATA_BITS			kLPUART_EightDataBits

/**
 * @brief	Default Number of Stop Bits If The Configuration File Could
 * 			Not Be Read Properly.
 */
#define DEFAULT_STOP_BITS			kLPUART_OneStopBit

/**
 * @brief	Default UART Parity If The Configuration File Could
 * 			Not Be Read Properly.
 */
#define DEFAULT_PARITY				kLPUART_ParityDisabled

/**
 * @brief	Defines The Threshold Level of Free Memory on The SD card,
 * 			Below Which The Lack of Memory is Indicated.
 * @details In Megabytes.
 */
#define DEFAULT_FREE_SPACE			50UL

#endif /* DEFS_H_ */

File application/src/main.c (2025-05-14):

/******************************
 *  Project:        NXP MCXN947 Datalogger
 *  File Name:      mainc.c
 *  Author:         Tomas Dolak
 *  Date:           07.08.2024
 *  Description:    Implements Data Logger Application.
 *
 * ****************************/

/******************************
 *  @package        NXP MCXN947 Datalogger
 *  @file           main.c
 *  @author         Tomas Dolak
 *  @date           07.08.2024
 *  @brief          Implements Data Logger Application.
 * ****************************/

/*******************************************************************************
 * Includes
 ******************************************************************************/

/* NXP Board Specific */
#include "fsl_device_registers.h"
#include "fsl_debug_console.h"
#include "fsl_clock.h"

#include "pin_mux.h"
#include "clock_config.h"
#include "board.h"

/* FreeRTOS Includes. */
#include "semphr.h"

/* Application Includes */
#include "app_init.h"
#include "app_tasks.h"
/*******************************************************************************
 * Definitions
 ******************************************************************************/

/*******************************************************************************
 * Global Variables
 ******************************************************************************/
/**
 * @brief 	Buffer for Static Stack of Mass Storage Task.
 */
static StackType_t g_xMscTaskStack[MSC_STACK_SIZE];

/**
 * @brief 	TCB (Task Control Block) - Meta Data of Mass Storage Task.
 * @details Includes All The Information Needed to Manage The Task Such As Job Status,
 * 			Job Stack Pointer, Values of Variables During Context Switching.
 */
static StaticTask_t g_xMscTaskTCB;

/**
 * @brief  Buffer For Static Stack Of Record Task.
 */
static StackType_t g_xRecordTaskStack[RECORD_STACK_SIZE];

/**
 * @brief  TCB (Task Control Block) - Meta Data of Record Task.
 * @details Includes All The Information Needed to Manage The Task Such As Job Status,
 *          Job Stack Pointer, Values of Variables During Context Switching.
 */
static StaticTask_t g_xRecordTaskTCB;


 /**
 * MISRA Deviation: Rule 8.4 [Required]
 * Suppress: External Object Has Definition Without Prior Declaration in This File.
 * Justification: Declaration of 'g_msc' is intentionally placed in 'app_tasks.h',
 * The Current File Only Provides The Definition.
 */
/*lint -e9075 */
/**
 * @brief Global USB MSC Structure.
 */
usb_msc_struct_t g_msc;
/*lint +e9075  */

/**
 * @brief USB Mass Storage Task Handle.
 */
TaskHandle_t g_xMscTaskHandle 	 = NULL;

/**
 * @brief Semaphore For USB Mass Storage Task Management.
 */
SemaphoreHandle_t g_xSemMassStorage;

/**
 * @brief Record Task Handle.
 */
TaskHandle_t g_xRecordTaskHandle = NULL;

/**
 * @brief Semaphore For Record Task Management.
 */
SemaphoreHandle_t g_xSemRecord;

/*******************************************************************************
 * Code
 ******************************************************************************/
 
/*!
 * @brief Application Entry Point.
 */
int main(void)
{

	g_xSemRecord = xSemaphoreCreateBinary();
	g_xSemMassStorage = xSemaphoreCreateBinary();

    if ((NULL == g_xSemRecord) || (NULL == g_xSemMassStorage))
    {
        PRINTF("ERR: Failed to Create Semaphores!\n");
#if (CONTROL_LED_ENABLED == true)
		LED_SignalError();
#endif /* (CONTROL_LED_ENABLED == true) */
    }

    /* Launch Record Task With Dominance */
    (void)xSemaphoreGive(g_xSemRecord);

    /* Initialize board hardware. */
	APP_InitBoard();

	g_xRecordTaskHandle = xTaskCreateStatic(
    			  record_task,       		/* Function That Implements The Task. 		*/
                  "record_task",          	/* Text Name For The Task. 					*/
				  MSC_STACK_SIZE,      		/* Number of Indexes In The xStack Array. 	*/
                  NULL,    					/* Parameter Passed Into The Task. 			*/
				  TASK_PRIO,				/* Priority at Which The Task Is Created. 	*/
				  &g_xRecordTaskStack[0],   /* Array To Use As The Task's Stack.		*/
                  &g_xRecordTaskTCB );
    if (NULL == g_xRecordTaskHandle)
    {
    	PRINTF("ERR: MSC Task Creation Failed!\r\n");
#if (CONTROL_LED_ENABLED == true)
		LED_SignalError();
#endif /* (CONTROL_LED_ENABLED == true) */
    	ERR_HandleError();
    }


#if (true == MSC_ENABLED)

    g_xMscTaskHandle = xTaskCreateStatic(
    			  msc_task,       			/* Function That Implements The Task. 		*/
                  "msc_task",          		/* Text Name For The Task. 					*/
				  MSC_STACK_SIZE,      		/* Number of Indexes In The xStack Array. 	*/
                  NULL,    					/* Parameter Passed Into The Task. 			*/
				  TASK_PRIO - 1,			/* Priority at Which The Task Is Created. 	*/
				  &g_xMscTaskStack[0],      /* Array To Use As The Task's Stack.		*/
                  &g_xMscTaskTCB );
    if (NULL == g_xMscTaskHandle)
    {
    	PRINTF("ERR: MSC Task Creation Failed!\r\n");
#if (CONTROL_LED_ENABLED == true)
		LED_SignalError();
#endif /* (CONTROL_LED_ENABLED == true) */
    	ERR_HandleError();
    }

#endif /* (true == MSC_ENABLED) */

    vTaskStartScheduler();
    while (true)
    {
    	;
    }

}

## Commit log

2024-08-31 [RTC/DS3231] Enables RTC DS3231 Driver.
2024-08-31 [RTC/DS3231] Enables RTC DS3231 Driver. Imports EDMA Drivers.
2024-10-17 [USB_MSC/BM] Enablement of USB Mass Storage Device.
    - Enables Static FreeRTOS Tasks
    - Implements vApplicationGetIdleTaskMemory()
    - Implements vApplicationGetTimerTaskMemory()
    - Implements MSC_ENABLED and MSC_STACK_SIZE Macros
    - Adds Files That MSC Dependes On
2024-10-18 [USB_MSC] Removes KHCI Driver. Clears Code (Removes KHCI, LPCIP3511FS and LPCIP3511HS Options).
2024-10-19 [USB_MSC] Removes Unnecessary Files. Fixes Warnings.
    Removes:
    - CMSIS_driver/
    - doc/
    - boot_multicore_slave.c/.h (Dual Core Won't Be Probably Used)
    [fsl_clock.c, main.c]
2024-10-26 [USB_DET] Starts Implementation of USB Detection Thru USB1_HS_IRQHandler.
    - Initialize USB Stack in main.c (Also Enables USB_HS_IRQHandler Earlier in USB Stack Init.).
    - Implements Two Task (As Default It's Running record_task, After USB Is Connected, The Mass Storage Device is Initialized And msc_task Starts Running)
    - Task Switching Is Implemented by g_TaskMutex.
2024-11-10 [TASK_SWITCHING] Enables Task Switching Based On USB On-To-Go.
2024-11-18 [TIMER] Adds Handling of Time In RAM By Timer.
    - Firstly TIMER & RTC Are Initialized
    - Then Time Is Loaded From RTC To RAM
    - Time is Kept By Timer
2024-11-26 [UART] Implements Initial Version of the UART Peripheral Support.
    - UART_FIFO_ENABLED Macro For Version UART With FIFO Buffer.
2024-12-01 [RECORD/uart] Improves Application UART.
2024-12-01 [Fix/FATFS] Fixes Baseline For Processing 'config' File.
    - Filename 'config' in defs.h Has To Be Upper Case.
    - Disabled Deinit of FATFS.
    [app_tasks.c, defs.h, record.c]
2024-12-07 [RECORD/uart] Simplifies The Code For The UART Application.
2024-12-19 [RECORD] Start Enablement of Recording.
    - FRO_HF For Application LPUART7.
    - Reading of Baudrate From Config File.
    - Printing of Chars Into Terminal.
2024-12-19 [RECORD] Start Enablement of Recording.
    - First Buffer Printed (514 Bytes)
2024-12-19 [RECORD] Enables LPUART With Interrupt & HW Fifo For Recording.
2024-12-21 [Common] Updates Interrupt Priorities.
2024-12-23 [Common] Changed Component Name of record.c/.h. Disables UART If Activity on USB_HS is Detected.
2024-12-23 [Common] Adds Switch For Printing Recorded Data To LPUART4 or Store Them To SD Card.
2024-12-23 [RECORD] Adds Triple-Buffering Method.
    - 1x FIFO Buffer & 2x ADMA Buffers.
    - Content of ADMA Buffers Are Stored Into SD Card.
    - Switch Between ADMA Buffers.
2024-12-23 [RECORD] Implements Flush Function.
    - After 3 Seconds of Waiting When No Character is Received, The Rest of DMA Buffer is Saved To The SD Card, The File is Closed and The Next Action is Waited For - Whether Another Char Stream or Switc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
    - Implementation Uses xTaskGetTickCount() From FreeRTOS. FreeRTOS Maintains a Tick Counter That Increments With Each Timer Interrupt.
2024-12-23 [RECORD] Implemented Usage of Write Into SD Card With Non-Blocking Way.
    - Checks ADMA Error Status (ADMA_ERR_STATUS)
    + 3 bit -> ADMA Descriptor Error
    + 2 bit -> ADMA Length Mismatch Error
    + 1-0 bit -> ADMA Error State (When ADMA Error Occurred)
    Field Indicates The State of The ADMA When An
    Error Has Occurred During An ADMA Data Transfer.
    [main.c, record.c]
2025-01-09 [TASKS/switching] Fixes Task Switching (USB MSC Mode -> Recording Mode).
    [app_tasks.c]
2025-01-13 [IRTC] Implements Base Logic For Internal RTC To Capture Time In The Application.
    - Issues:
    - Time Currently Cannot Be Set
    [defs.h, main.c, record.c]
2025-01-18 [RECORD] Fixes Logic For IRTC. Enables Writing Time To File Metadata.
    [main.c, record.c]
2025-01-24 [COMMON] Unifies Error Handling.
    [app_tasks.c, main.c, record.c]
2025-01-25 [COMMON] Resolves Warnings During Compilation.
    [defs.h, record.c, rtc_ds3231.h]
2025-01-26 [RECORD] Fixed Setup of Baud Rate. Adds Possibility To Setup Log Size.
    [app_tasks.c, record.c]
2025-01-26 [FIX/flush] Fixed Flush Function. The Situation When lastTick Is Greater Then currentTick (Affected By ISR Routine).
    - Used __atimic_load_n GCC Inline Function.
    [app_tasks.c, record.c]
2025-02-01 [FIX/flush] Fixed Flush Function. (Abs. Value Between Current & Last Tick). Updates Conditions To Yoda Style.
    [record.c]
2025-02-02 [PWR_CONSUMPTION] Adds Power Consumption Log From PPK2.
2025-02-02 [TMP/i3c] Adds I3C Driver For Communication With P3T1755 Temperature Sensor.
2025-02-11 [CONTROL_LEDS] Prepares The Foundation For Control Diodes Logic.
2025-02-11 [TPM] Adds Base For Initialization of Temperature Sensor.
2025-02-18 [TMP] Improves I3C Driver.
2025-03-03 [IRTC] Fixes Convertion of I2C Driver From CMSIS To SDK.
    [main.c, rtc_ds3231.c, rtc_ds3231.h]
2025-03-03 [TMP] Adds Write & Read Function To Communicate With P3T1755 Temperature Sensor.
2025-03-04 [TMP] Enables Temperature Measurement With P3T1755 On-Board Sensor.
2025-03-04 [TMP] Sets Temperature Measurement Once Every 10 Minutes.
2025-03-30 [COMMON] Adds Baseline For Control LEDs. Changes Uart From FC7 To FC3
2025-03-30 [VIN_DETECTION] Adds Baseline For Power Loss Detection By Comparator.
    - Does Not Work Very Well
    [pwrloss_det.c]
2025-03-30 [COMMON] Improves Control of LEDs
2025-03-30 [COMMON] Fixes Warnings. Corrects Variable Names and Adds Doxygen Comments.
    [main.c, record.c, temperature.c]
2025-03-30 [COMMON] Adds Doxygen Comments & Corrects Variables Names.
    [app_tasks.c, defs.h]
2025-03-31 [CONTROL_LEDS] Adds Conditional Compilations. Changes GPIO Module To LED Module.
2025-03-31 [COMMON] Updates Doxygen Comments To Error Definitions.
    [defs.h]
2025-03-31 [PWRLOSS_DET] Fixed Power Loss Detection.
    - Replaced The Inverting Input With a Non-Inverting One of The LPCMP.
    [pwrloss_det.c]
2025-03-31 [PWRLOSS_DET] Improves Power Loss Detection & LED Modules. Changes Interrupt Prio. of Timer For Power Loss Detection Due To Interruption of Mass Storage Mode.
2025-04-01 [MUTEX] Modifies Task Switching Using Mutex.
2025-04-01 [MUTEX] Modifies Task Switching Using Mutexes (For Each Task).
    - Replaces Management With One Mutex and The usbAttach Signaling Variable
    [app_tasks.c, main.c]
2025-04-09 [MISRA] Resolves All Mandatory and Required MISRA Findings.
    [app_init.c, app_tasks.c, defs.h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]
2025-04-19 [MISRA] Fixes The Rest of MISRA Findings.
    [pwrloss_det.c]
2025-04-23 [MUTEX] Improves Task Switching With Mutex.
2025-04-25 [MUTEX] Adds Final Task Switching. Improves Parser, LED Blinking During Errors.
    - Default Values if Params Are Not In Configuration File.
    - Variables Names
    [app_tasks.c, defs.h, main.c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]
2025-05-03 [DOCS] Adds Pictures of LED States.
2025-05-03 [DOCS] Updates LEDs Recording Picture.
2025-05-03 [DOCS] Improves Descriptions of LEDs In README.md.
2025-05-04 [TIME] Fixes Time Convertion From DS3231 To IRTC.
    [defs.h, uart.c]
2025-05-06 [COMMON] Fixes Code Based on MISRA Findings & Improves Code Comments.
    [app_tasks.c, main.c, parser.c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]
2025-05-06 [COMMON] Fixed Last MISRA Finding.
    [app_tasks.c]
2025-05-07 [COMMON] Corrected Prints & Sets Default Setup To defs.h.
    [app_init.c, app_tasks.c, defs.h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]
2025-05-09 [HW/SHIELD] Adds Design of Expansion Shield.
    [GPS_module0.kicad_sch, PinHeaders.kicad_sch, RTC_DS3231M.kicad_sch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]
2025-05-09 [HW/SHIELD] Adds Genereated PDF Schematic & Newer Version of Expansion Shield.
    [GPS_module0.kicad_sch, PinHeaders.kicad_sch, RTC_DS3231M.kicad_sch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]
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2025-05-12 [HW] Updates Project of Expansion Shield.
    [GPS_module0.kicad_sch, PinHeaders.kicad_sch, RTC_DS3231M.kicad_sch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]
2025-05-12 [HW] Adds BOM in CSV Format.
    [BOM.csv]
2025-05-12 [COMMON] Adds Manual, and READMEs To Power Consumption & Power Loss Detection Measurements.
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2025-05-12 [COMMON] Corrects Names of Variables.
    [record.c, rtc_ds3231.c, temperature.c]
2025-05-12 [MISRA] Corrected Last Comment. Generated Doxygen Documentation.
    [record.c]
2025-05-12 [FIX] Fixed Default Value of max_bytes Parameter.
    [parser.c]
2025-05-13 [HW] Adds Labels To Expansion Shield Schematic, PDF Schematic & Performed Schematic, PCB Tests.
    [GPS_module0.kicad_sch, PinHeaders.kicad_sch, RTC_DS3231M.kicad_sch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]
2025-05-14 [COMMON] Switch Submodule Reference to Submitted Version of Technical Report.
2025-05-14 [COMMON] Re-Uploaded Hardware Files.
    [GPS_module0.kicad_sch, PinHeaders.kicad_sch, RTC_DS3231M.kicad_sch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]
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2025-06-22 [USB_MSC] Delays USB Interrupt Activation and Mass Storage Startup.
2025-06-23 [COMMON] Merge of Delayed USB Interrupt Activation and Mass Storage Startup Into Develop.
